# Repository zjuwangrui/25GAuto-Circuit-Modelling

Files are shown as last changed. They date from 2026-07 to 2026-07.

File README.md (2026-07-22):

# 电路模型探究装置 (STM32 + AD9910 + 大彩串口屏)

STM32F103VE 平台。硬件通路：**STM32 → AD9910 → 硬件电路 (×5.11 放大器 + 未知滤波器) → 输出端**。
上位交互靠 **大彩串口屏 (USART2, 115200)**。

---

## 业务链路

### 1. 输出信号（当前唯一实现的链路）

屏侧 3 个控件（学习/推理按钮暂缓）：

| 控件 | 类型 | ctrl_id | 屏发/收帧 |
|---|---|:---:|---|
| 频率输入框 | 文本 (type=0x11) | **4** | `EE B1 11 00 00 00 04 11 [ASCII] 00 FF FC FF FF` |
| 电压输入框 | 文本 (type=0x11) | **7** | `EE B1 11 00 00 00 07 11 [ASCII] 00 FF FC FF FF` |
| 输出信号按钮 | 按钮 (type=0x10) | **11** | `EE B1 11 00 00 00 0B 10 00 01` (**10 字节, 无 FF FC FF FF 帧尾**) |

```
用户屏上输入 freq   → 屏发文本帧 (ctrl_id=4)  → MCU 缓存 last_freq
用户屏上输入 vpp    → 屏发文本帧 (ctrl_id=7)  → MCU 缓存 last_vpp
用户点 "输出信号"   → 屏发按钮帧 (ctrl_id=11) → MCU 调 signal_out_set(last_freq, last_vpp)
                                                → signal_out 反算 H(s)+5.80× → dds_tone_sine
                                                → AD9910 → 电路 → OUT
```

### 2. 学习流程（TODO）

屏侧学习按钮暂未定义 ctrl_id。业务模块 `module/learning` 保留空壳（`learning_start` 只置状态）。

### 3. 推理流程（TODO）

同上，`module/inference` 保留空壳。

---

## 模块分层

```
bsp/            硬件外设 (uart, spi, gpio, adc, lcd, led)
drv/            外设芯片 (ad9910, serial_screen, esp8266, dht11)
module/         业务逻辑:
                  signal_out   传递函数反算 (freq/vpp → DDS 参数)
                  dds          AD9910 各种输出模式 (单音/RAM任意/DRG扫频/跳频/OSK)
                  panel_ctrl   串口屏胶水层 (屏事件 ↔ 业务模块)
                  learning     学习动作 (当前空壳)
                  inference    推理动作 (当前空壳)
                  ui           TFT LCD 页面
                  thd, fft, goertzel  频谱分析
core/           调度器 + 环形缓冲
```

**分层原则**：
- `drv/serial_screen` 只懂协议帧
- `module/panel_ctrl` 只懂 UI 业务映射
- `module/learning` / `module/inference` 只懂算法
- 换屏 → 只改 `drv/serial_screen`；改算法 → 只改对应 module

---

## 硬件接线

| 功能 | STM32 引脚 | 备注 |
|---|:---:|---|
| SPI1 → AD9910 | PA5 / PA6 / PA7 | SCK / MISO(未接) / MOSI |
| AD9910 CS | PA4 | |
| AD9910 RST | PC3 | |
| AD9910 IOUP | PA12 | |
| AD9910 PROFILE[0..2] | PB12 / PB13 / PB14 | |
| AD9910 PWR/DPH/DRC | PC0 / PC1 / PC2 | 上电拉低保命 |
| **USART2 → 串口屏** | **PA2 (TX) / PA3 (RX)** | **115200 8N1** |
| USART1 → 调试口 | PA9 / PA10 | 115200，UART_Printf |
| LCD (FSMC) | 一堆 | 保持原样 |

详细接线：`resources/AD9910模块-STM32接线说明(按实物更正版).txt`

---

## 传递函数（signal_out 用）

$$H_{fit}(s) = \frac{4.68}{1.23 \times 10^{-8} s^2 + 3.48 \times 10^{-4} s + 1}$$

- ωn ≈ 9017 rad/s ≈ 1435 Hz，ζ ≈ 1.57（过阻尼，两实极点 ~518 Hz / ~3990 Hz）
- DC 增益 = 4.68，前级放大 5.00× → **总 DC 增益 ≈ 23.4**
- 系数在 [src/module/signal_out.c](src/module/signal_out.c) 里 `H_S_COEF_*` / `H_S_DC_GAIN` 三个宏
- 放大倍数在 [include/module/signal_out.h](include/module/signal_out.h) 里 `SIGNAL_OUT_AMP_GAIN`

---

---

## 构建

PlatformIO，配置在 [platformio.ini](platformio.ini)：

```shell
pio run              # 编译
pio run -t upload    # 烧录 (ST-Link)
pio device monitor   # 打开串口 (USART1)
```

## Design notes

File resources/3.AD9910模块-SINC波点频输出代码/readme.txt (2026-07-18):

/*********************************************************************************************/
【*】程序简介

-工程名称：AD9910-STM32-DDS驱动板-Vx.x
-实验平台: 康威DDS驱动板
-MDK版本：KEIL 5.14.0
-ST固件库版本：3.5.0
	工程文件位于"\AD9910-STM32-DDS驱动板-Vx.x\USER"目录下，用keil5软件打开VirtualCOMPort.uvprojx即可

【 ！】功能简介：
控制AD9910模块输出SINC波

【*】注意事项：

【 ！】实验操作：
1、使用排线连接驱动板与AD9910模块，驱动板上排线方向唯一，驱动板以及DDS模块上，板子背面双排针，方形焊盘为双排针1脚，对应连接即可
2、使用5V电源连接AD9910模块，使用5V电源连接DDS驱动板，
3、AD9910模块侧面输出高频头，使用SMA屏蔽线，连接示波器，(两个输出头，任意接一个即可)
3、编译该代码，使用jlink下载器下载代码到驱动板
4、确保AD9910模块已上电。按下驱动板复位键(或驱动板重新上电)，调整示波器时间档位到2uS/DIV,即可观察到SINC波输出

/*********************************************************************************************/

【*】 引脚分配
	
STM32控制板		模块	芯片引脚名	功能
PC13		----->	PWR	EXT_PWR_DWN.	掉电控制脚。数字输入。置高(3.3V)芯片关机，不使用需接地。
PA5		<---->	SDIO	SDIO.		串行数据输入/输出。
PC1		----->	DPH	DRHOLD.		数字斜坡保持。数字输入。置高(3.3V)有效,不使用需接地。
PC2		<-----	DRO	DROVER		数字斜坡结束。数字输出(高电平有效)
PC3		----->	IOUP	I/O UPDATE	同步信号(LVDS),数字输入(上升沿有效)。写完多个寄存器后给一个高脉冲。
PC4		----->	PF0		
PC10		----->	PF1		
PC5		----->	PF2	PROFILE[2:0]	Profile选择引脚。数字输入（高电平有效）。
PA6		----->	RST	MASTER RESET	主机复位，数字输入（高电平有效）。
PA2		----->	SCK	SCLK		串行数据时钟。数字时钟(上升沿执行写操作，下降沿执行读操作)
PA4		----->	DRC	DRCTL		数字斜坡控制。数字输入.控制数字斜坡发生器的斜率极性,不使用需接地。
PC8		----->	OSK	OSK		输出振幅键控。数字输入。
PB10		----->	CSB	CS加I/O_RESET	数字输入。SPI通信CS控制脚及通信复位脚。
GND		<---->	GND			控制板与AD9910模块需共地。
浮空		------	其他			所有未说明但模块有留出管脚，未使用可直接浮空，功能请参考数据手册

/*********************************************************************************************/

【*】 版本

-程序版本：0.6
-更新日期：2023-05-xx

/*********************************************************************************************/

【*】 联系我们

-淘宝店铺    https://kvdz.taobao.com

/*********************************************************************************************/

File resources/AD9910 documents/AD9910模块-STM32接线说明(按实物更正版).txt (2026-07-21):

================================================================
  AD9910 DDS 模块 <-> STM32F103VE  接线说明
  --------------------------------------------------------------
  项目: 25GAuto-Circuit-Modelling
  驱动: src/drv/ad9910.c    业务: src/module/dds.c
  最后更新: 2026-07-16 (对齐当前代码实际引脚映射)
================================================================

一、必接引脚 (单音正弦输出 = Mode 1 最小系统)
--------------------------------------------------------------
    STM32F103VE     方向        AD9910 模块丝印     芯片功能
    -----------     -----       ---------------     -----------------------
    PA5             ->          SCLK                 SPI 时钟   (SPI1 SCK, 9 MHz)
    PA7             ->          SDIO                SPI 数据   (SPI1 MOSI, 只写)
    PA4             ->          CSB                 片选       (低有效, 软控)
    PC3             ->          RST                 MASTER_RESET (高电平复位)
    PA12             ->          UPD                IO_UPDATE   (上升沿刷寄存器)
    PB12            ->          PF0            (PF0,PF2,PF2的功能描述)Mode 4 跳频用. 单音模式下必须为低电平,否则输出可能偶发丢失.
    PB13            ->          PF1            推荐做法二选一:
                                                A) 三根线连到 STM32, 让驱动拉低
                                                B) 模块侧直接短接到 GND (更省 GPIO)
                                                悬空 = 错误配置, 会不稳定.
    PB14            ->          PF2            
    GND             <->         GND                 共地 (必须!)

    电源: 外部 DC 5V (0.5A 以上)  ->  模块 "DC-5V" USB 供电座，连接到电源的CH3USB接口即可，成功供电的时候AD9910模块会有小蓝灯亮起来
          !! AD9910 模块不能从 STM32 板取 3.3V, 它自带 5V->3.3V/1.8V 稳压器 !!

ftp上面的资料(AD9910模块-STM32接线说明)部分有误，有些不必连接，有些选择连接。更正如下：

━━━━━━━━━━━━━━━━━━━━━━━━━━━━━━━━━━━━━━━━━━━━━━━━━━━━━━━━━━━━━━━━━━━━━━━━━━━━━━
 STM32控制板   方向    模块    芯片引脚名        功能
━━━━━━━━━━━━━━━━━━━━━━━━━━━━━━━━━━━━━━━━━━━━━━━━━━━━━━━━━━━━━━━━━━━━━━━━━━━━━━

 PC13         ────>    PWR     EXT_PWR_DWN       掉电控制脚。数字输入。
                                                 置高(3.3V)芯片关机，不使用需接地。
 【实际情况】这个引脚AD9910芯片上有，模块上面的排针没有引出，不必处理，
           PC13也不需要连接什么。

────────────────────────────────────────────────────────────────────────────────

 PA5          <───>    SDIO    SDIO              串行数据输入/输出。
 【实际情况】合理，必连，PA5引脚可以改成其他GPIO。

────────────────────────────────────────────────────────────────────────────────

 PC1          ────>    DPH     DRHOLD            数字斜坡保持。数字输入。
                                                 置高(3.3V)有效，不使用需接地。
 【实际情况】根据实际需要，数字斜坡模式可以输出频率或者相位或者幅度线性
           变化的正弦波，一般我们不需要这个功能。

────────────────────────────────────────────────────────────────────────────────

 PC2          <────    DRO     DROVER            数字斜坡结束。
                                                 数字输出(高电平有效)。
 【实际情况】同DPH。

────────────────────────────────────────────────────────────────────────────────

 PC3          ────>    IOUP    I/O UPDATE        同步信号(LVDS)，数字输入(上升沿有效)。
                                                 写完多个寄存器后给一个高脉冲。
 【实际情况】必须连接，但是引脚名称模块上实际是UPD。

────────────────────────────────────────────────────────────────────────────────

 PC4          ────>    PF0
 【实际情况】必须连接。

────────────────────────────────────────────────────────────────────────────────

 PC10         ────>    PF1
 【实际情况】必须连接。

────────────────────────────────────────────────────────────────────────────────

 PC5          ────>    PF2     PROFILE[2:0]      Profile选择引脚。
                                                 数字输入（高电平有效）。
 【实际情况】必须连接。

────────────────────────────────────────────────────────────────────────────────

 PA6          ────>    RST     MASTER RESET      主机复位，数字输入（高电平有效）。
 【实际情况】必须连接。

────────────────────────────────────────────────────────────────────────────────

 PA2          ────>    SCK     SCLK              串行数据时钟。数字时钟
                                                 (上升沿执行写操作，下降沿执行读操作)。
 【实际情况】必须连接。

────────────────────────────────────────────────────────────────────────────────

 PA4          ────>    DRC     DRCTL             数字斜坡控制。数字输入。
                                                 控制数字斜坡发生器的斜率极性，
                                                 不使用需接地。
 【实际情况】处理同DPH、DRO。实测发现不需要的时候不用接地，悬空即可，
           需要数字斜坡模式的时候连接到对应的GPIO引脚。

────────────────────────────────────────────────────────────────────────────────

 PC8          ────>    OSK     OSK               输出振幅键控。数字输入。
 【实际情况】选择性连接，振幅键控是和数字斜坡一样的另一种输出模式，
           不需要的话就悬空，需要则连接某个给定GPIO。

────────────────────────────────────────────────────────────────────────────────

 PB10         ────>    CSB     CS加I/O_RESET     数字输入。SPI通信CS控制脚
                                                 及通信复位脚。
 【实际情况】必须连接。

────────────────────────────────────────────────────────────────────────────────

 GND          <───>    GND
 【实际情况】必须共地，控制板与AD9910模块需共地。

────────────────────────────────────────────────────────────────────────────────

 浮空         ─────    其他                      所有未说明但模块有留出管脚，
                                                 未使用可直接浮空，功能请参考
                                                 数据手册。

━━━━━━━━━━━━━━━━━━━━━━━━━━━━━━━━━━━━━━━━━━━━━━━━━━━━━━━━━━━━━━━━━━━━━━━━━━━━━━

二、可选引脚 (仅特定模式用)
--------------------------------------------------------------
    STM32F103VE     AD9910 丝印    情况说明
    -----------     -----------    ----------------------------------------
    PB15            OSK            Mode 5 (OSK 键控) 用. 单音下悬空即可.

三、完全不接的引脚 (悬空 OK)
--------------------------------------------------------------
    SDO       SDO引脚是无排针的引脚，有些资料会提到这个引脚，实际上我们是无法控制的
    PWR      EXT_PWR_DWN, 掉电控制脚, 模块上无此引脚排针，无法控制
    SYC       SYNC 相关, 多片同步用
    PDCLK     并口数据时钟, 并口模式用
    TEN       TXENABLE, 并口模式用
    RSO       IO_RESET, 通信复位用
    PLL       无芯片对应排针
    DRO       DROVER, 是芯片输出脚
    D0..D15   16 位并口数据总线, 并口模式用
    F0, F1    并口目的选择, 并口模式用

    -> 全部悬空, 本工程不需要
AD9910是一个有90多个引脚的芯片，而AD9910模块上的排针只引出了一部分引脚，有些资料虽然提到了一些引脚，但是实际上我们无法控制，比如上面的SDO,PLL,PWR。
并口模式是这样，AD9910可以通过SPI串行输入，也可以直接并行输入，都可以输出一样的波形。一般有FPGA用并行，无的话用串行，所以并行相关引脚我们一般都不用，悬空即可。

四、示波器接线
--------------------------------------------------------------
    AD9910 SMA 输出       示波器
    ---------------       ---------------------------
    OUT+ (J3)             CH1     
    OUT- (J4)             也可以接 CH2 做差分，观察CH1-CH2波形，也可以不管。这个信号是OUT+的反相，不差分没事情。

    AD9910芯片输出是电流，但是AD9910模块内置了一些电路将电流转化为电压，将模块的SMA接一个SMA转鳄鱼夹线(直接和老师说要这个线)，再连接示波器就可以用，连接排针则可接入实际电路。

五、幅度校准 (已实测)
--------------------------------------------------------------
    include/module/dds.h 里 DDS_FULL_SCALE_V = 1.0f
    实测: dds_tone_sine(f, 1.0f, 0) 时示波器测到差分峰值约 1 V
    -> 当前 1.0f 已经匹配本板实际满量程, 不需要重新校准.
    -> 若换其他 AD9910 模块 (balun / Rset 不同), 需重新实测并修改此宏.

六、代码里改引脚的位置
--------------------------------------------------------------
    src/drv/ad9910.c    第 28-46 行 "硬件绑定" 宏
                          CS / RESET / IOUP / PROF / OSK / PWR / DPH / DRC
                          全部集中在这一块

    src/bsp/spi.c       第 17 行左右, SPI1 的 SCK/MOSI/MISO
                          (PA5/PA7/PA6 硬件固定, 不建议改)

    src/bsp/uart.c      USART1 的 PA9(TX) / PA10(RX) 调试串口

================================================================

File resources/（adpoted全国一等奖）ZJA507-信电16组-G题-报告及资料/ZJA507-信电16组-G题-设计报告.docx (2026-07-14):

# 电路模型探究装置（G 题）

摘要：本装置以STM32F407微控制器为核心，结合DDS信号源、高精度ADC采样及数字信号处理技术，对已知及未知电路模型的自动化分析与控制。本系统分两大功能模块。第一，针对已知二阶系统模型，装置能够根据用户设定的目标输出频率（100Hz-3kHz）和电压（1-2V），通过传递函数H(s)反算出所需的输入电压，并精确控制DDS输出。第二，针对未知RLC电路模型，装置具备自主学习与建模能力。通过自动扫频（1kHz-500kHz）获取电路的幅频响应数据，采用基于Levenberg-Marquardt（LM）算法的专家拟合系统，精确辨识出电路的滤波类型（低通、高通、带通、带阻）及其关键参数（k, f0, Q）。学习完成后，装置能实时采集外部信号，通过数字IIR滤波器模拟未知电路的响应，与实际信号峰峰值相对误差小于10%，波形稳定无失真。

关键词：电路模型，系统辨识，自动控制，数字滤波器，STM32

# 1 方案对比与论证

## 1.1 波形发生电路

【方案一】采用DDS集成模块，由单片机控制输出可调固定频率、幅值的正弦波，AD9910输出的正弦波的最高频率可达420MHz，具有扫频功能。该方案的优点是频率分辨率高，相关波形参数可调，缺点是成本较高。

【方案二】采用锁相环频率合成，该方法可以产生频率稳定精确、且频率大范围可调的信号，优点是频率相对更稳定精确，缺点是电路更复杂，且工作频率范围由电路参数控制，不易直接调节。

波形发生的目的是为装置提供频率稳定的测量正弦波信号，考虑到在进一步的电路设计分析中，需要尝试不同频率的测量信号，因此更希望波形发生电路频率稳定便于调节，结构简单。因此选择方案一。

## 1.2 信号输入方案的论证与选择

【方案一】外挂ADC模块（如TI的ADS1115或AD7606）可提供更高分辨率（16-24位）和更宽动态范围。部分高速ADC型号（如AD9288）采样率可达100MSPS，远超STM32板载ADC。其优势在于信号调理电路可独立设计，减少数字噪声干扰，提高信噪比；高精度型号（如24位Σ-Δ型ADC）适合微弱信号采集。然而，该方案存在关键缺陷：外挂ADC使用独立时钟源（通常为外部晶振），与STM32系统时钟不同步，导致采样时钟存在固有偏差（±30ppm或更高）；在进行数字滤波和信号处理时，时钟漂移将引起相位误差累积，严重影响频率响应测量精度；

【方案二】采用STM32板载ADC。STM32F407ZGT6集成3个12位精度ADC，总采样率可达8.4MSPS（3交错采样），单通道最高2.4MSPS，理论可采集1.2MHz以下信号（满足奈奎斯特准则）。其核心优势在于与主控时钟完全同步，ADC采样时钟源自APB2总线（经分频后最高30MHz），与系统时钟严格一致，彻底消除时钟漂移问题；内置硬件过采样功能可提升有效分辨率至14位；支持DMA直接内存访问，减轻CPU负担；

综上，考虑到题目的要求，方案二能更直接、更精确的实现信号的采样与同步输出的兼容，因此选择方案二。

## 1.3 交流信号输出方案的论证与选择

【方案一】STM32板载DAC。STM32F407ZGT6内置双通道12位DAC，最高更新率达1MSPS，理论输出正弦波频率可达500kHz（满足奈奎斯特准则）。其优势在于与主控时钟完全同步，无时钟漂移问题，可确保输出信号与系统时钟严格同频；数字信号处理直接在MCU内部完成，延迟低且可控。通过软件实现IIR滤波算法，能精确复现目标系统的频率响应特性。但受限于DAC更新率，单一通道最高输出频率不足1MHz；输出电压范围为0-3.3V，需通过精密运放（如OPA2211）构建放大与偏置电路才能达到3V峰峰值要求；高频段谐波失真增加，影响信号纯度。

【方案二】FPGA结合并行传输DAC。采用FPGA（如Xilinx Artix-7）配合高速DAC（如AD9767，125MSPS）可实现高达40MHz的输出频率，远超题目要求。FPGA的并行处理架构能实时计算复杂波形，支持多通道同步输出。但该方案系统复杂度高，需额外设计FPGA与STM32的高速通信接口（如FMC或并行总线），增加硬件设计难度和成本；两系统时钟不同步导致相位抖动，难以满足频率误差<5%的要求；开发周期长，不利于竞赛时限内完成

【方案三】STM32外挂DDS模块 采用AD9850等DDS芯片（时钟70MHz），频率分辨率可达0.04Hz，输出频率范围0-40MHz，完全满足>1MHz的要求。其优势在于频率切换速度快（<100ns），扫频过程中无需等待稳定，可高效采集多频点数据用于H(s)建模；输出信号频谱纯净，THD<-80dBc。但DDS使用独立晶振（通常±30ppm精度），与STM32系统时钟存在固有偏差，导致输出信号与输入信号存在频率漂移，无法满足"稳定同频显示"要求；输出幅度仅0.5Vpp，需多级放大才能达到3V峰峰值，增加电路复杂度。

综合题目双重需求：基础任务要求快速扫频建模，拓展任务要求稳定同频显示。经如下论证，采用方案一与方案三结合的策略：

1. 扫频建模阶段：使用DDS模块（方案三）实现100Hz-1.5MHz范围内的快速扫频，其高频率精度和快速切换特性可高效获取未知电路的频率响应数据，满足H(s)建模需求；

2. 同频显示阶段：采用STM32板载DAC（方案一）结合数字IIR滤波，输出与输入信号严格同步的预测响应，避免晶振误差导致的频率漂移；

3. 信号调理：两路输出分别经由NE5532构建的精密放大电路，实现0-3.3V至±1.5V的电平转换与增益调节，确保峰峰值>3V，利用模拟开关整合至同一输出。

该方案充分发挥了DDS的频率精度优势和STM32 DAC的时钟同步优势，既满足了快速建模需求，又保证了同频显示的稳定性，同时避免了FPGA方案的复杂性，是本系统最优解。

# 2 理论分析与计算

## 2.1 已知模型电路的分析与计算

（1） 电路结构与拓扑分析

根据题目给出的H(s)响应函数可以知道已知模型为一个二阶低通滤波电路，直流增益为5倍，故可利用有源二阶滤波电路结合同相放大器实现，为了实现题目要求输入电阻大于100kΩ，采用NE5532音频放大器构建跟随器，输入电阻约为NE5532输入电阻300kΩ，为了避免有源二阶滤波器产生自激现象，采用单位增益的Sallen-Key结构有源二阶滤波器，滤波完成后经过同相放大器放大至5倍后，再经跟随器输出，降低输出电阻。

（2）电路参数设计

有源二阶低通滤波器：采用Sallen-Key结构，H(s) = 1 / ( (R1R2C1*C2) * s² + ((R1+R2)C1) * s + 1 )，故R1 * R2 * C1 * C2 = 1e-8；(R1 + R2) * C1 = 3e-4。设定C1=C2=100nF，计算R1=2618Ω,R2=382Ω

同相放大器：同相输入后在反相输入端设定2kΩ电阻接地，反馈电阻应设定为10kΩ

## 2.2 精密信号放缩电路分析设计与计算

## （1）需求分析

DDS输出信号峰峰值最大1.17V，需要给予放大倍率以满足最大输出电压高于3V的需求，STM32ADC输入限幅0~3.3V，需要对信号进行放缩并加以直流偏置以避免烧毁单片机

### （2） 设计与参数计算

由于同时存在放大与缩小需求，需要同时保留信号放大与缩小的功能，同时由于放大信号频率最大值需要大于1MHz较高，需要选用OPA1612高GBW运放辅以多阶放大以避免失真问题，初级放大采用同相输入端直接输入辅以1~5倍可调增益，第二级采用电位器可调0~10/11衰减后接入20倍同相放大器，最后通过电容直接耦合加入可调直流偏置，最终实现直流偏置0.57V~12V可调，交流增益0~100倍任意可调，同时满足DDS放大输出与ADC衰减输入的需求。

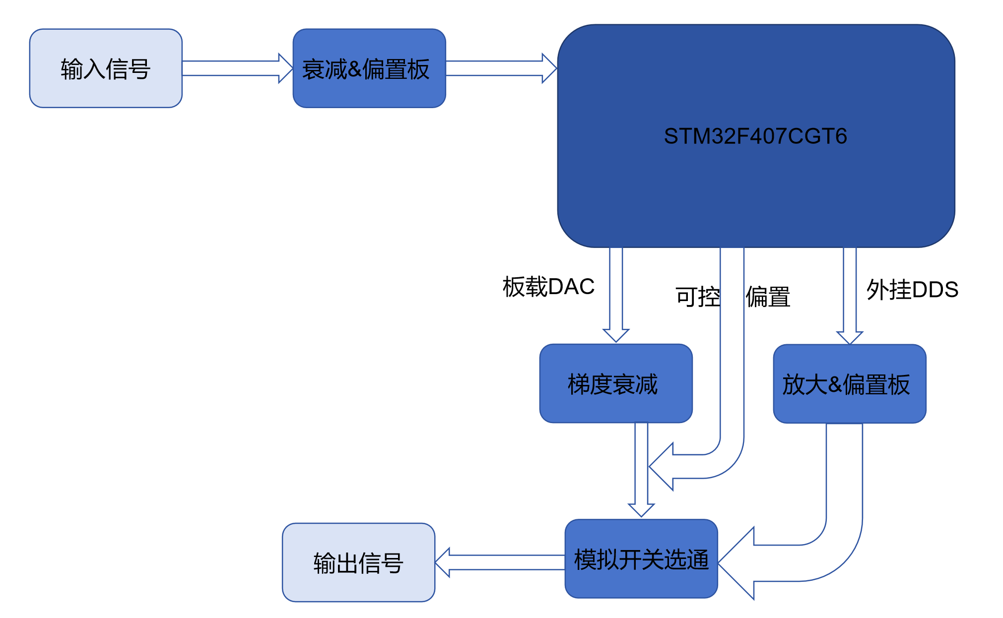
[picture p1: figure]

# 3 电路与程序设计

## 3.1 电路设计

图2. 系统框图

## 3.2 已知模型电路子系统电路

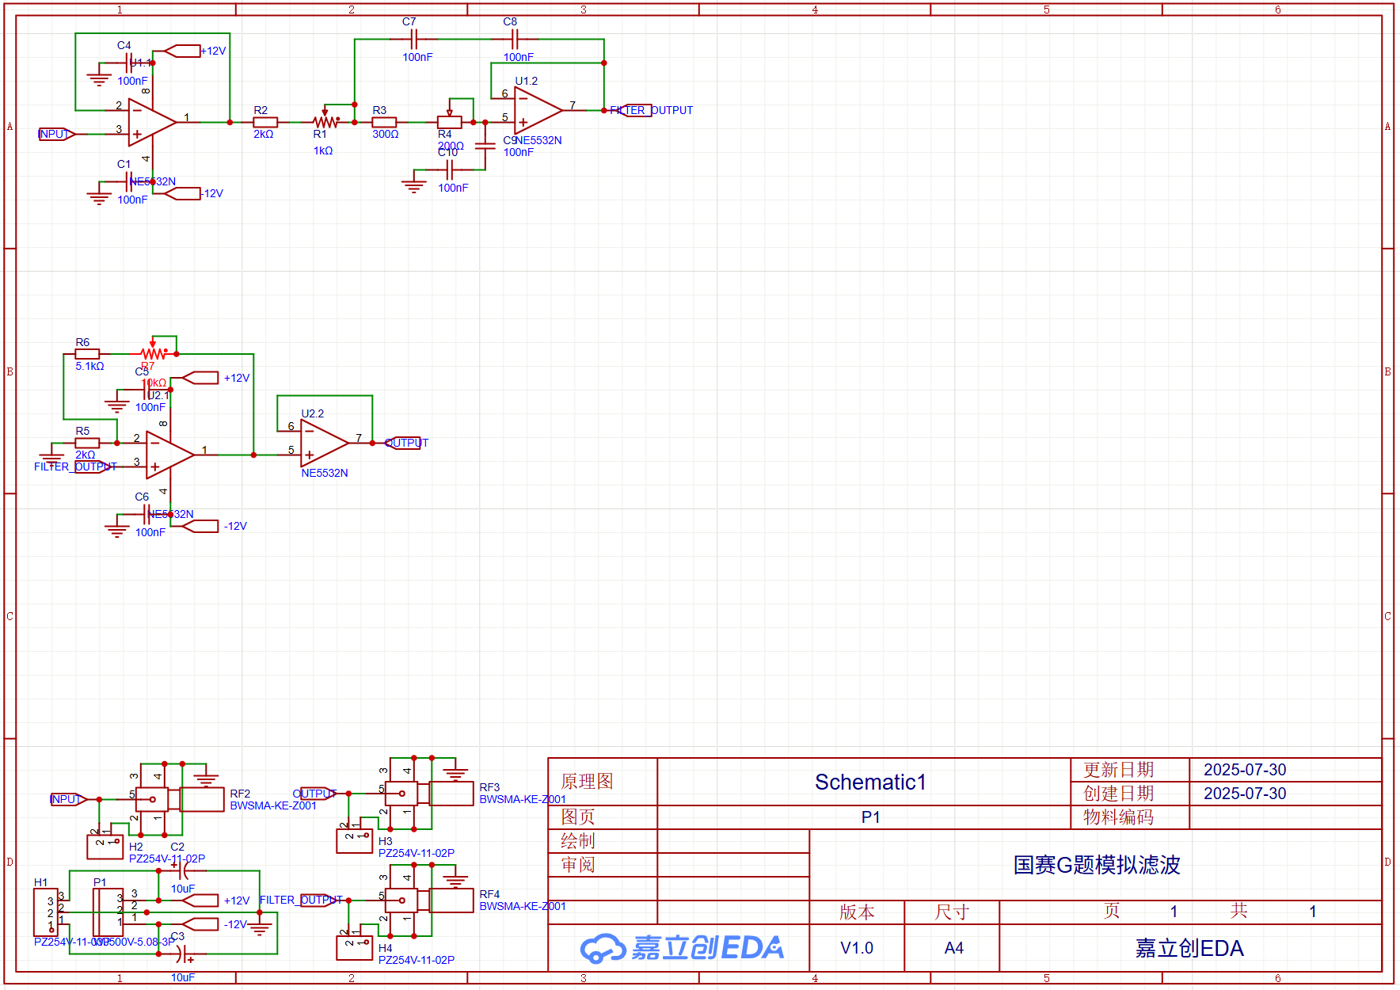
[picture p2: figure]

图3. 已知模型电路

## 3.3 DAC信号输出电路子系统框图与电路原理图

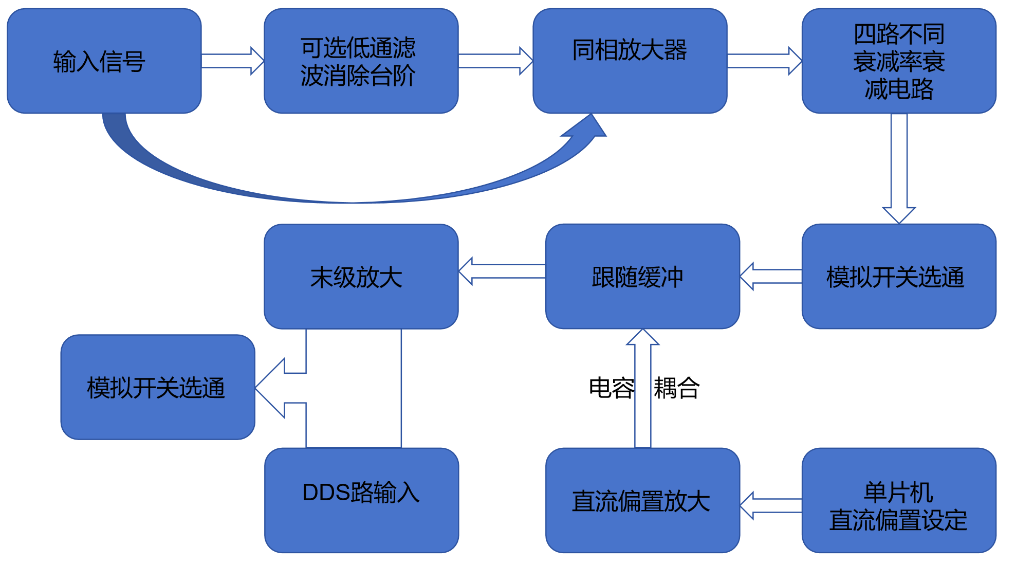
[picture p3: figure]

图4. DAC信号输出电路子系统框图

## 3.4 DAC信号输出电路子系统电路

电源：整体电路设计中用到+-12V与+-5V供电，+-12V供电由学生电源提供，+5V供电采用+12V经LM317 LDO降压输出，最大电流满足需求，-5V由+12V经DCDC降压芯片降至-5V输出

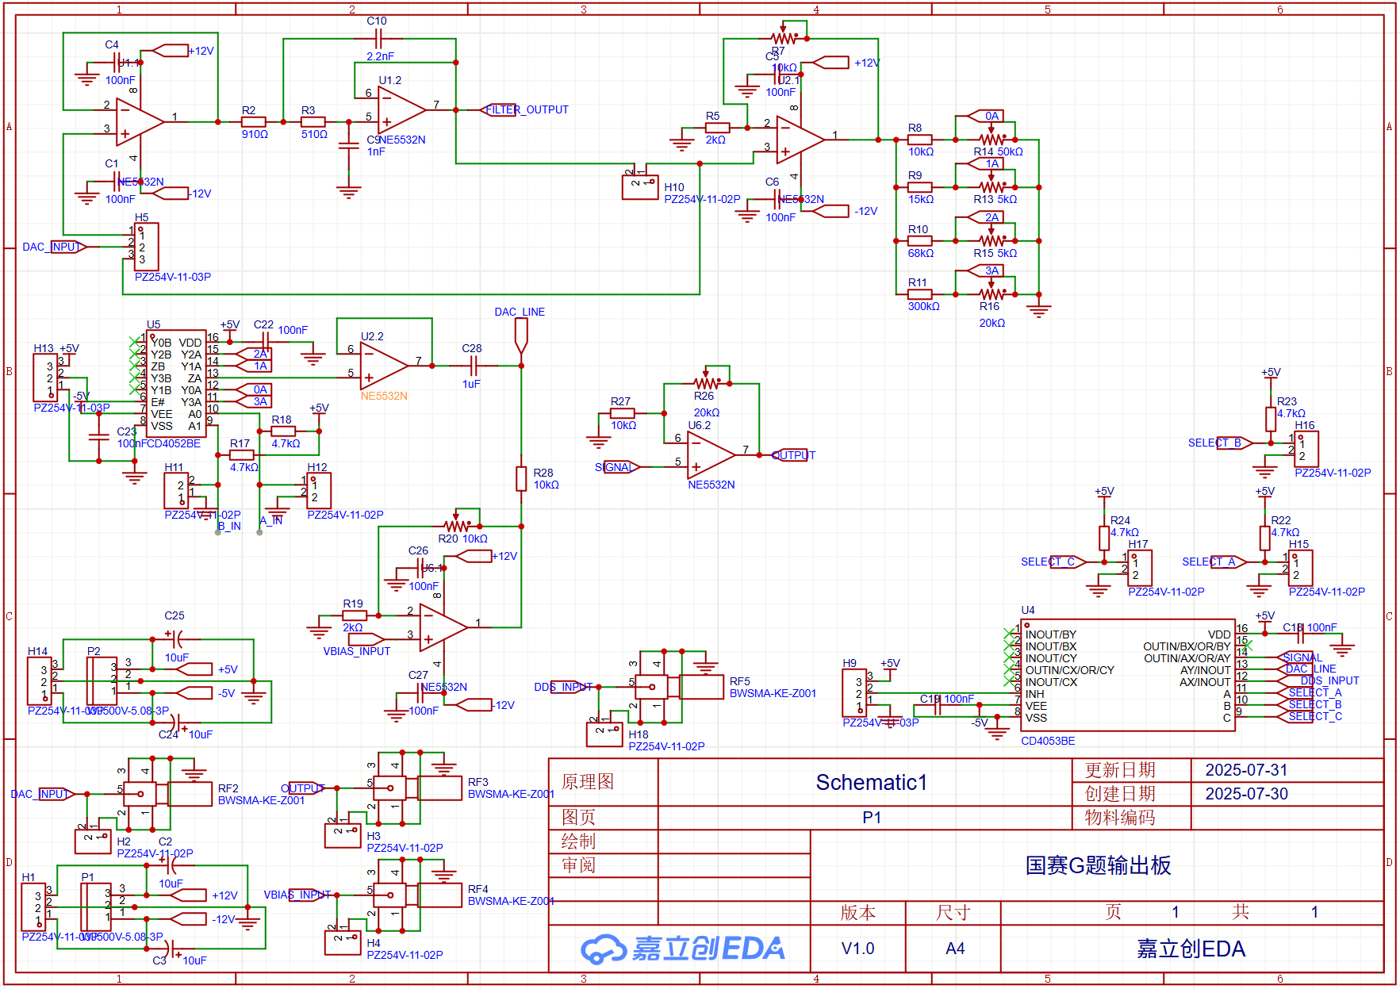
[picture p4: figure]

# 4 测试方案与测试结果

## 4.1 测试结果

向已知模型电路中输入各频率的1Vpp，偏置1V的信号，分别测量输出电压，与理想H(s)的增益对比，测试结果好，如下表所示：

信号频率(kHz) | 直流 | 0.1 | 0.3 | 0.5 | 1 | 1.5 | 2 | 3
输出Vpp增益(V/V) | 5.001 | 5.045 | 4.522 | 3.822 | 2.473 | 1.726 | 1.286 | 0.802
理想增益Av(V/V) | 5 | 4.932 | 4.472 | 3.834 | 2.526 | 1.767 | 1.311 | 0.806
相对误差 | 0.02% | 2.29% | 1.11% | 0.32% | 2.10% | 2.42% | 1.91% | 0.50%

## 4.2 校正DDS输出后设定已知模型电路输出电压测试

频率 | 100Hz | | 500Hz | | 1kHz | | 2kHz | | 3kHz
幅值 | 1V | 2V | 1V | 2V | 1V | 2V | 1V | 2V | 1V | 2V
实测值 | 1.002 | 1.955 | 1.035 | 2.045 | 1.045 | 2.056 | 1.046 | 2.055 | 1.047 | 2.053
相对误差 | 0.2% | 2.25% | 3.5% | 2.25% | 4.5% | 2.28% | 4.6% | 2.25% | 4.7% | 2.65%

## 4.3 结果分析

根据上述测试数据，可以得出以下结论：

1、已知模型电路可以接近给出的H(s)响应函数，相对误差最大不超过3%，远高于精度要求不超过10%

2、探究系统可以输出0.23Hz分度值的正弦波，最大不失真频率可达1.5MHz，峰峰值达4.5V，输出峰峰值不小于3V输出频率可达2MHz

3、探究系统可输出1kHz信号，使得已知模型电路输出2V定值电压，实测输出2.04V，相对误差2%，远低于题目要求5%

4、探究系统可输出100Hz~3kHz信号，使已知模型电路输出电压可以以0.1V步进调整，相对误差在5%以下

5、探究系统可在40s内对未知模型电路进行学习建模，拟合其幅度谱并给出滤波器类型的判断。

6、探究系统可根据学习的幅度谱，对输入的1kHz~50kHz的信号进行模拟输出，与未知模型电路的幅值差距在10%以内。

综上所述，本设计达到设计要求。

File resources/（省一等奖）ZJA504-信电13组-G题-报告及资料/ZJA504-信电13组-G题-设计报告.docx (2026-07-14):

电路模型探究装置（G题）

摘要：本装置以TI MSPM0G3519单片机为主控核心，利用DDS芯片AD9910生成信号，并结合由DAC控制的AD603压控增益放大器进行精密幅度调节，通过串口屏进行人机交互。装置能够完成两项核心任务：首先，根据内置的已知滤波器H(s)模型，自动计算并生成所需激励信号，实现对输出的精确控制。其次，在未知模型探究中，装置通过扫频，利用双通道ADC同步采集输入输出信号，在主控内部通过q15格式CFFT算法快速建立未知电路的数字模型。学习完成后，装置能实时采集外部信号，通过CFFT、CIFFT算法进行运算，较为准确地复现出与未知电路相同的输出。经测试，本系统基本完成了对已知模型的精确控制和未知模型的建模学习与复现，误差均在题目要求范围以内，基本要求和发挥部分指标大部分已实现。

关键词：TI MSPM0G3519单片机 、DDS、压控增益放大器、滤波器、CFFT（快速复数傅里叶变换）、CIFFT（快速复数逆傅里叶变换）

1.方案论证

1.1比较与选择

1.2.1 已知模型电路选择

【方案一】采用 Sallen−Key 结构搭建滤波器，模拟H（S）函数。

【方案二】采用二阶RC滤波器+运算放大器，模拟H（S）函数。

选择：二者的仿真都很精准，与传递函数H（S）的频率响应很接近，但是实际搭建电路后，发现方案二的准确度更高，曲线拟合更精准，故选取【方案二】。

1.2.2 正弦信号生成方案：

【方案一】采用AD9910来生成频率可控的正弦波，配合以DAC控制VCA的增益来调节信号幅度。

【方案二】采用AD9851输出幅度一定的正弦信号，再利用AGC来调控幅度。

选择：由于考虑到后续需要用到AD9910的随机信号生成功能，又在实验中发现制作的AGC在100Hz附近输出波形严重失真，由此决定采用【方案一】。

1.2.3 未知电路学习建模方案：

【方案一】利用DDS输出1到512000Hz的扫频信号，步进为1kHz，再用双ADC采集输入端和输出端的信号，利用q15格式的CFFT算法计算出输入输出信号的复数谱，在相应的频率点作复数除法并逐个填入H(s)响应谱。

【方案二】在双ADC采样处信号后直接计算输入输出端的Vpp，做除法后直接得到增益谱。

【方案三】用DDS输出1到512000Hz的扫频信号，步进为1kHz，再用双ADC采集输入端和输出端的信号，利用float32_t格式的CFFT算法计算出输入输出信号的复数谱，在相应的频率点作复数除法并逐个填入H(s)响应谱。

选择：由于【方案二】完全损失了相位信息，对于复杂波形输出的的信号严重失真，而【方案三】耗时过长，因此采用【方案一】，通过分析幅度谱的两个3dB点位置即可判断滤波类型，为保证输入输出端采样的同时性，两者均采用同一个timer触发，并将采样频率定为1MHz。

1.2.4 推理输出方案：

在得到H(s)之后即可利用其中一个ADC采样输入信号，利用CFFT计算其复数谱，再将其与H(s)作复数乘法得到输出信号Y(s)的频谱，而对于频谱变换的CIFFT，我们有以下两种方案。

【方案一】调用arm_math库自带的cfft_q15进行反变换

【方案二】采用手工封装的经过类型转换的cifft进行计算

选择：在实验过程中CIFFT_q15的输出严重丢失了分辨率，于是我们采用了【方案二】，反变换出它的缩放后时域谱并记录下其峰峰值用于预测其幅值。信号输出采用AD9910的数字模拟输出方案，利用过零点法记录下其一个周期的点数并计算出其频率，将包含一个周期的点的数组和频率传给AD9910的RAM后即可使能输出波形，幅度控制同样通过DAC控制VCA的反馈方案。

1.2 方案描述

1.1.1 系统组成框图

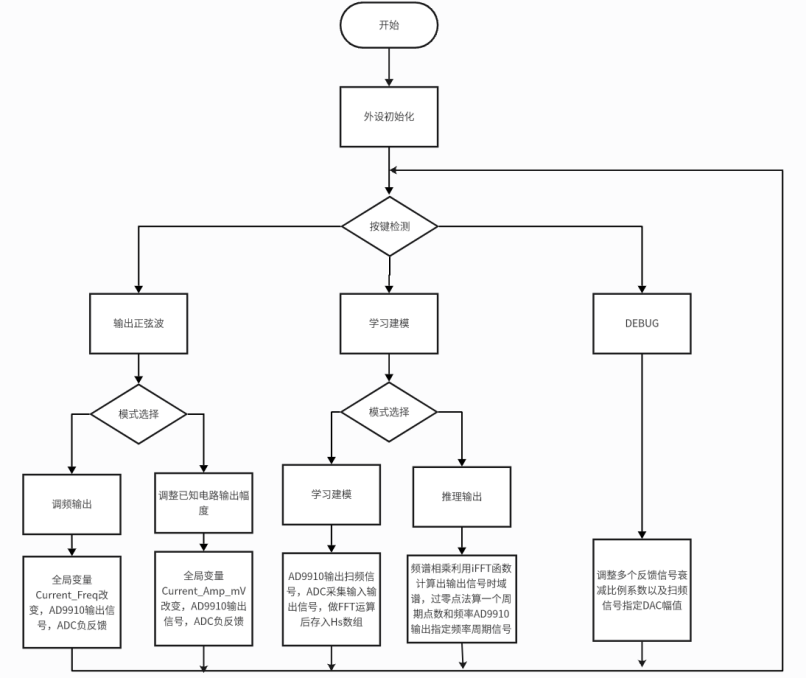
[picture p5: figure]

图1 系统框图

1.1.2 系统工作原理

本装置上电初始化后，可以通过不同的按键，进入不同的工作模式。

正弦波控制模式：此模式下，装置既可以作为独立的信号源，输出指定频率的正弦波；也可以进入控制状态，根据已知的H(s)模型，自动计算并生成精确的激励信号，从而将“已知模型电路”的输出稳定在要求的电压值上。

学习与推理模式：此模式用于发挥部分。学习模式中，装置自动执行扫频，通过双通道ADC同步采集输入输出信号，并利用FFT算法快速建立起未知电路的数字模型H(s) 。推理模式中，装置会利用这个模型，实时地将外部输入信号计算并转换为与未知电路行为一致的输出波形，最终通过AD9910的任意波形生成功能将其复现出来。

调试模式：系统还包含一个DEBUG模式，用于脱机调试。

2.理论分析与计算

2.1已知模型电路分析

已知模型的传递函数： H(s)=5/(10^(−8) s^2 +3×10^(−4) s+1) ，而对于二阶RC有源低通滤波器的传递函数公式为： H(s)=(ω_n^2)/(s^2 +2ξω_n +ω_n^2) ，故可推算出滤波器所需的R、C的值。经过计算，取 R1=1kΩ ， R2=1kΩ，C1100nF，C2=100nF，R3=2kΩ，R4=8kΩ ，拟合出已知模型的传递函数。

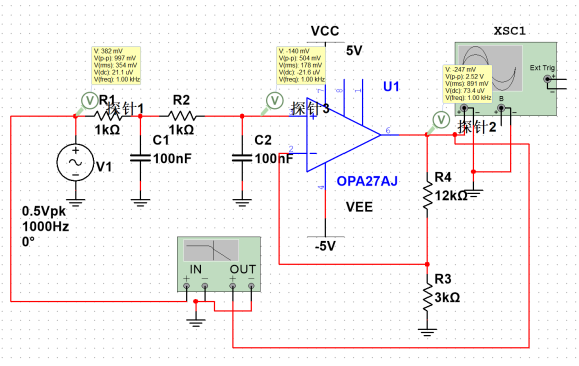
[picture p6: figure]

图2 低通滤波器仿真电路图

2.2未知模型电路学习建模方法

本方法的核心是扫频分析。装置首先用DDS生成一个扫频信号输入到未知电路。同时，采用双通道ADC同步采集电路的输入和输出信号。采集后，系统对两路信号执行q15格式的快速傅里叶变换（CFFT），得到它们的复数频谱。最后，通过将输出频谱除以输入频谱，便可计算出该电路的传递函数H(s)模型，并依此判断出其滤波类型。

3.电路与程序设计

3.1电路设计

3.1.1 已知模型电路：

采用RC二阶有源低通滤波器，电阻R1、R2和电容C3、C4的值是根据理论计算精确选择的，以实现目标传递函数。

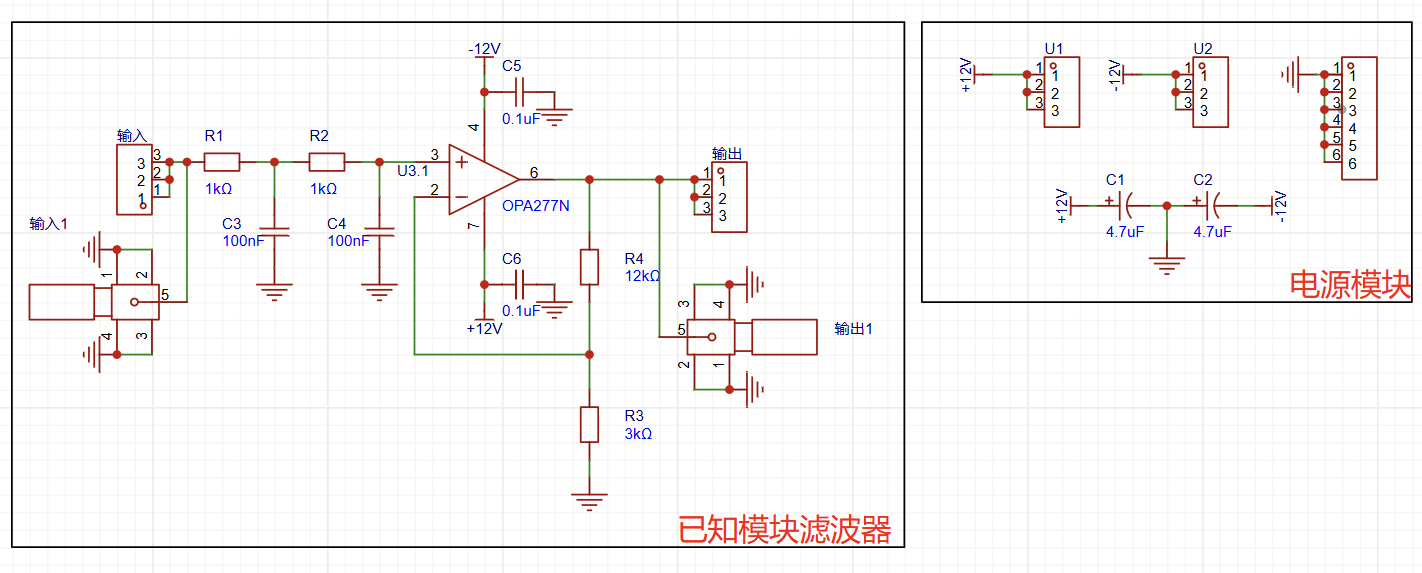
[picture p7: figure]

图3 已知模型电路原理图

3.1.2 电压偏置跟随器：

该电路使用OPA27运放搭建成电压跟随器，一是为了将前后级隔离，提供缓冲；二是作为ADC输入驱动，将在0V附近摆动的交流信号转化为1.6V附近摆动的偏置信号，从而输入单片机采样。

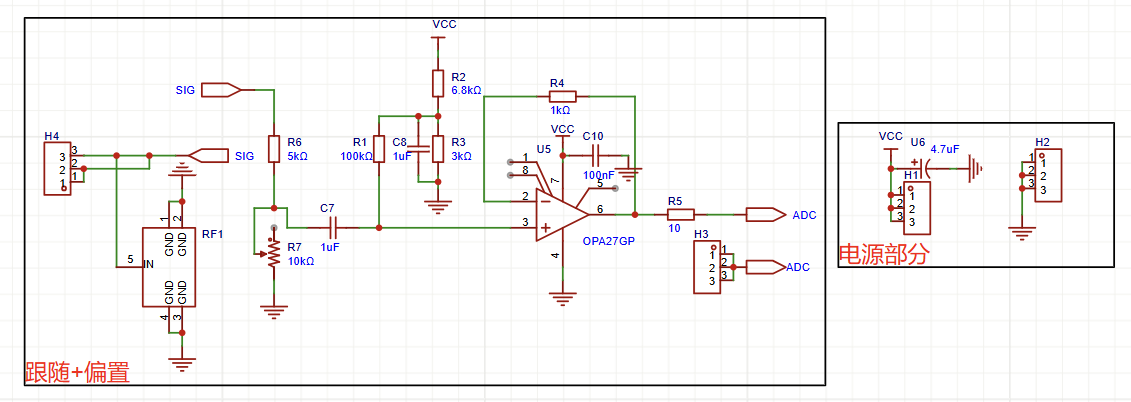
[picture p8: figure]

图4 电压偏置跟随器电路原理图

3.1.3 AD603压控增益放大器：

单片机通过DAC输出一个控制电压VGP，控制AD603放大器的增益。OPA690高速运放作为末级输出缓冲，提供足够的驱动能力。

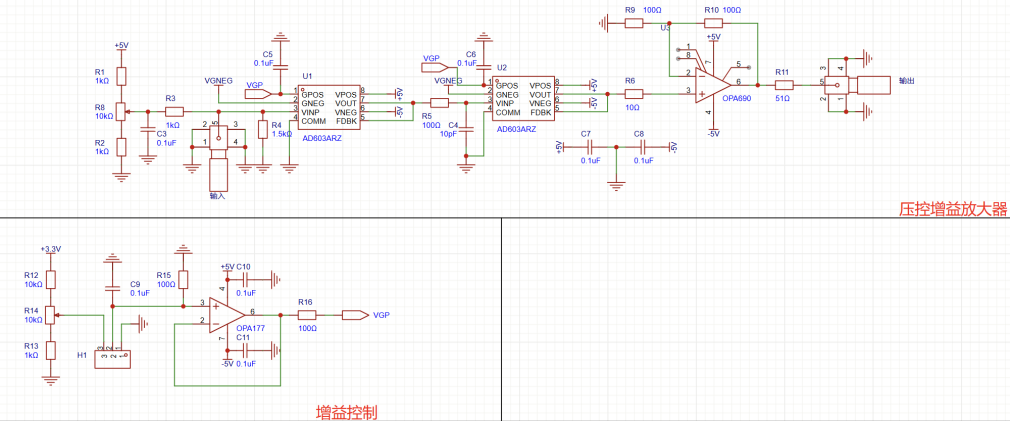
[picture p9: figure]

图5 AD603压控增益放大器电路原理图

3.2程序设计

装置的控制器是TIM0G3519开发板。在正弦波生成过程上，控制部分主要完成了控制DDS输出指定频率的正弦波，由ADC接受输出衰减信号与设定值比较，并通过DAC来与VCA交互以控制其幅度；在学习建模部分，通过TIMER触发双ADC同步采样输入输出信号，分别FFT运算并作复数除法后得到H(S)作为未知装置模型，以完成学习建模过程；在推导输出部分，控制器对输入信号进行FFT运算后与H(S)完成复数乘法再作CIFFT生成输出信号，并计算一个周期的点数以及频率、幅度，最后控制AD9910和VCA以输出相应信号。

人机交互方面，采用串口屏幕与单片机通信，加强了可视化和直观性。

4.测试方案与测试结果

4.1测试方案及测试条件

4.1.1 测试条件

直流稳压电源eTM-3303D、示波器DHO4804、信号发生器DG-4202。

4.1.2 测试方案

测试（1）：已知模型电路特性验证 向“已知模型电路”输入1Vpp、频率100Hz至3kHz的正弦信号 。测量各频点的输出电压，并与由传递函数H(s)计算的理论值进行比较，验证相对误差小于10%。

测试（2）：探究装置信号输出能力测试 测试探究装置产生的正弦信号，验证其频率范围不小于1MHz、频率相对误差小于5%，且各频点输出电压峰峰值最大值不小于3V。

测试（3）：探究装置对已知模型的控制精度测试 将探究装置连接至“已知模型电路”，设置装置在100Hz至3kHz频率范围内 ，控制模型电路输出1V至2V的峰峰值电压 。测量实际输出电压，验证其与设定值的相对误差小于5%。

测试（4）：未知模型学习功能测试 将探究装置连接现场提供的“未知模型电路”，启动“学习键” 。计时验证装置可在2分钟内完成学习，并正确显示其滤波类型。

测试（5）：未知模型复现能力测试 将信号发生器同时接入探究装置和“未知模型电路”，二者输出接至示波器双通道 。在1kHz至50kHz的多种周期信号激励下 ，对比两路输出波形，验证其同频稳定、无失真，且峰峰值相对误差小于10%。

4.2测试结果及其完整性

测试（1）：已知模型电路特性验证

频率 | 100Hz | 500Hz | 1000Hz | 2000Hz | 3000Hz
理论输出电压（Vpp） | 4.94 | 3.84 | 2.53 | 1.31 | 0.81
实际输出电压（Vpp） | 4.96 | 3.88 | 2.53 | 1.30 | 0.81
相对误差 | 0.4% | 1.04% | 0% | 0.76% | 0%

测试（2）：探究装置信号输出能力测试

设置频率 | 100Hz | 1kHz | 10kHz | 100kHz | 1MHz
实际频率 | 101.2Hz | 999.3Hz | 10.13kHz | 100.36kHz | 1.011MHz
电压幅值是否大于3V | √ | √ | √ | √ | √
频率相对误差 | 1.20% | 0.70% | 1.30% | 0.36% | 1.10%

测试（3）：探究装置对已知模型的控制精度测试

频率 | 100Hz | 500Hz | 1000Hz | 2000Hz | 3000Hz
设定电压（Vpp） | 2.00 | 1.60 | 1.50 | 1.40 | 1.00
实际输出电压（Vpp） | 2.02 | 1.64 | 1.49 | 1.40 | 1.01
电压相对误差 | 1.00% | 2.50% | 0.67% | 0.00% | 1.00%

测试（4）：未知模型学习功能测试

学习时间：40s

实际模型类型 | 低通 | 高通 | 带通 | 带阻
判断是否准确 | √ | √ | √ | √

测试（5）：未知模型复现能力测试

输入信号频率 | 1kHz | 5kHz | 10kHz | 25kHz | 50kHz
输入信号波形 | 正弦波 | 50%方波 | 20%方波 | 80%方波 | 三角波
电路输出电压（Vpp） | 1.04 | 1.82 | 1.67 | 1.45 | 1.80
装置输出电压（Vpp） | 1.02 | 1.81 | 1.70 | 1.47 | 1.75
相对误差 | 1.92% | 0.55% | 1.80% | 1.37% | 2.78%

4.3测试结果分析

根据以上测量数据，本系统设计并制作的电路模型探究装置成功实现了各项功能。在基本要求部分，装置对已知模型电路的模拟电路的测试误差在1.04%以内，输出信号频率误差在1.3%以内，对已知模型的输出电压控制精度高，相对误差均小于2.5%；在发挥部分，装置学习未知模型用时仅40秒，且能精准判断滤波类型 ；在模型复现测试中，对于多种复杂输入信号，装置输出与电路实际输出的相对误差均小于3%。综上，本装置精度高、功能完善，具有良好的人机交互界面，完成了题目的全部要求。

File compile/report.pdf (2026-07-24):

# 电路模型探究装置 (G 题)

## 大二 06 组 实验报告

摘 要

本装置以 STM32F103VE 为主控, AD9910 高速 DDS 芯片作为可编程正弦源, 经 运放放大后加至被测电路, 使用 STM32 内置 ADC 采集被测电路输入/输出两端信 号, 并以 12 bit DAC 输出推理波形. 大彩串口屏作为交互终端, 用户通过屏选择四 种工作模式: 信号输出模式 (DDS 按设定频率直接输出正弦), 已知模型控制模式 (软 件反算 H(s) 后驱动 DDS, 使已知模型输出达到设定峰峰值), 学习模式 (探究装置 接未知电路两端, 通过扫频法建立其传递函数并显示滤波类型), 推理模式 (探究装 置作为已建模滤波器, 对信号发生器给入的任意周期信号做实时数字滤波输出). 经 测试, 装置在 100 Hz∼3 kHz 控制已知模型输出的相对误差小于 5%, 学习建模在两 分钟内完成滤波类型判别, 推理输出峰峰值与真实未知电路输出的相对误差小于 10%.

关键词: STM32 AD9910 DDS 传递函数 数字扫频建模 IIR 数字滤波 滤波类 型识别

目录

一、 方案对比与论证 | 3
二、 理论分析与计算 | 5
三、 电路与程序设计 | 9
四、 测试方案与测试结果 | 16
五、 结论 | 18

### 一、方案对比与论证

### 1.1 系统工作模式设定

按题目要求, 探究装置需支持信号发生、控制已知模型输出、学习未知电路、推 理复现未知电路输出四种功能. 本装置将其归纳为串口屏可切换的四种工作模式:

表 1 探究装置工作模式

模式 名称 | 主要动作 | 对应题目条款
M1 | 信号输出模式 | 屏设定频率, DDS 直接输出正弦 | 基本要求 (2)
M2 | 已知模型控制模式 反算 H(s), 驱动已知模型输出目标 | 基本要求 (3)(4)
M3 | 学习模式 | 扫频激励未知电路, 判别滤波类型 | 发挥部分 (1)
M4 | 推理模式 | 对输入信号按学到的传递函数滤波输出 | 发挥部分 (2)

四种模式共用同一硬件通路 (DDS + 前级放大 + ADC + DAC), 由屏上按键一 键触发. 题目” 三、说明” 中” 设置完成后一键启动, 后续不可人工干预” 的要求由主 控内的状态机保证: 模式一经进入, 内部执行与屏事件解耦.

### 1.2 已知模型电路方案

方案一 MFB (多重反馈) 结构. 元件数量少, 对电容电阻容差不敏感; 缺点是运放 增益带宽积要求高, 参数配比复杂.
方案二 Sallen-Key (SK) 结构. 二阶低通经典拓扑, 直流增益可独立设置, 元件选 择灵活.
已知模型 H(s) = 5/(10−8
| | s 2 + 3×10−4
s + 1) 的 Q ≈ 0.33 属过阻尼, 对元件容差 不敏感, SK 拓扑更易于调试并可独立标定直流增益, 选用方案二.

### 1.3 正弦信号产生方案

方案一 AD9910 高速 DDS 模块. 频率分辨率 ∆f = fSYSCLK/2³² ≈ 0.233 Hz (SYSCLK = 1 GHz), 输出范围 0∼400 MHz, 谱纯度高, 支持硬件扫频.
方案二 STM32 内置 DAC + DMA + 定时器. 电路简单, 无外置芯片; 但 STM32F1 DAC 采样率上限约 1 MSPS, 1 MHz 输出仅有几个重构点, 谱纯度和幅度精度差, 且 无硬件扫频.
题目基本要求 (2) 要求最高频率 ≥ 1 MHz, 步长 100 Hz, 频率相对误差 ≤ 5%, 各 频点 Vpp 最大值 ≥ 3 V. DAC 方案难以覆盖高频, 选用方案一.

### 1.4 未知模型学习方案

方案一 数字扫频法. 装置 DDS 从 fmin 单调扫频至 fmax, ADC 同步采集未知电 路输入端与输出端, 每频点用 Goertzel 算法计算复数比值得到 |H(jωi)|, 再与四种二

阶模型解析式做最小二乘拟合, 选残差最小者作为滤波类型, 同时输出参数 (ω0, ζ, K). 方案二 冲激/阶跃响应法. 输入宽带方波, ADC 采时域响应, 用 Prony 或 ARX 法直接从时域数据辨识极零点.
方案三 三特征频点法. 只测低/中/高三点幅度关系直接分类, 不做参数拟合. 方案二对 ADC 带宽 (需 ≫ 50 kHz 上限) 和存储要求高, 且 Prony 法对噪声敏 感; 方案三只能判类型, 无法给推理阶段提供传递函数系数. 选用方案一.

### 1.5 推理生成信号方案

方案一 数字滤波法 (ADC + IIR + DAC). 学到的连续域传递函数经双线性变换 离散化为 IIR 差分方程, ADC 采输入信号, 单片机实时运算, DAC 输出. 输入输出用 同一定时器触发, 自然同步.
方案二 硬件模拟法. 用通用滤波器芯片 UAF42 加数字电位器现场重搭同类型电 路. 保真度高, 但通用滤波器芯片供货困难, 无法覆盖任意 ω0/ζ.
方案三 频域重构法. 输入信号 FFT 后频谱乘以 |H(jω)| 再 IFFT. 分块处理引 入块延迟, 且信号发生器信号为连续周期波, 分块拼接会破坏” 连续同频稳定显示” 要 求.
选用方案一.

### 二、理论分析与计算

### 2.1 已知模型电路参数计算

题目给定电压传递函数为

H(s) = | 5
10−8s

2 + 3 × 10−4s + 1

. | (1)

与二阶低通标准形式
| H(s) = | Kω²
| | 0
| s 2 + | ω0
| | Q s + ω
| | 2
| | 0

(2)

比较可得

K = 5, | ω0 = 10⁴
rad/s, | f0 =
| | ω0
| | 2π
= 1591.5 Hz, | Q =

1
3

. (3)

实际 SK 电路中，R1 = R2 = 15 k，反馈电容 C1 = 4.7 nF，对地电容 C2 = 10 nF， 运放接成电压跟随器。其传递函数为

HSK(s) = | | 1
| R1R2C1C2s

2 + (R1 + R2)C2s + 1

. | (4)

OP27 后级采用反相放大，Rin = 8.2 k，Rf = 40 k，因此

Av = −

| Rf
| Rin = − | 40
| | 8.2
= −4.878. | (5)

忽略运放有限带宽后，实际元件标称值对应的总传递函数为

Hdesign(s) = | | −4.878
1.0575 × 10−8s

2 + 3.000 × 10−4s + 1

. | (6)

由式(1)和式(6)得到表2。可以看出，一次项系数与目标值相同，二次项系数偏差 5.75%，直流增益偏差 −2.44%，元件选取基本合理。

表 2 目标模型与实际元件标称值比较

参数 | 目标值 | 实际设计值 | 相对偏差
直流增益 |K| | 5.000 | 4.878 | −2.44%
一次项系数 | 3.000 × 10−4 | 3.000 × 10−4 | 0.00%
二次项系数 | 1.000 × 10−8 | 1.0575 × 10−8 | +5.75%
特征频率 f0 | 1591.5 Hz | 1547.7 Hz | −2.76%
品质因数 Q | 0.333 | 0.343 | +2.83%

### 2.2 已知模型输出电压反算

正弦稳态下 s = jω, ω = 2πf, 幅频响应模值

|H(jω)| =

| | K
√(
1 − ω²/ω

2/0)2
| | +

(
ω/(ω0Q)

)2

设目标观测点差分峰峰值为 Vtgt, 探究装置后级实测放大倍数为 Gamp, 则 DDS 应输出的差分峰峰值为
VDDS(f) = | Vtgt
Gamp · |H(j2πf)|
板级前级放大加已知模型电路整体传递函数与理论 H(s) 存在容差, 装置在标定 阶段对实测幅频曲线做二阶拟合得到 Hfit(s) = 4.68/(1.23×10−8
s

2 + 3.48×10−4
s + 1)
用于运行时反算, 与理论 H(s) 相差约 6% 增益与 15% 极点位置, 在容差范围内.

### 2.3 DDS 放大模块分析

OPA847 采用同相放大结构，反馈电阻 R15 = 750 Ω，下臂电阻 R14 = 39 Ω，闭 环增益为

Gamp = 1 +

750
39
= 20.23. | (7)

输入端设置 50 Ω 终端电阻和 33 Ω 串联电阻，以减小 DDS 连接线反射；输出端串联 50 Ω 电阻，提高驱动同轴线时的稳定性。正负电源各使用 6.8 µF 与 100 nF 并联去 耦。
输出 3 Vpp、1 MHz 正弦波所需的最小压摆率为
SRmin = 2πfVp = πfVpp = 9.42 V/µs. | (8)

因此该级必须使用高速运放，并重点控制反馈回路面积、地回流路径和输出负载；若 实测高频幅度提前下降，应优先检查终端匹配、供电去耦、PCB 寄生和 DDS 幅度设 置，而不能简单归因于 1 MHz 本身。

### 2.4 测频模块分析

LM339 负端接参考电压。由 20.3 kΩ 与 10 kΩ 分压可得

Vref = VCC

10
20.3 + 10
= 0.330VCC. | (9)

当 VCC = 5 V 时，Vref ≈ 1.65 V。比较器输出为开集电极结构，4.7 kΩ 上拉与 5.6 kΩ 下拉使高电平约为

VOH = VCC

5.6
4.7 + 5.6
= 0.544VCC ≈ 2.72 V, | (10)

可直接送入 3.3 V 单片机输入口。
输入信号经 22 nF 隔直电容和 100 kΩ 串联电阻进入比较器正端，47 kΩ 电阻将 该点偏置到 Vref，3.3 MΩ 反馈电阻提供迟滞。按电阻网络估算，5 V 供电时上下门限 相差约 80 mV，可抑制过零附近的噪声重复触发。交流输入等效阻抗约为
Rin,ac ≈ 100 k + (47 k ∥ 3.3 M) ≈ 146 k, | (11)

满足发挥部分输入电阻不小于 100 kΩ 的要求。由 22 nF 耦合电容形成的高通拐点约 为 50 Hz，对 1 kHz 以上输入影响很小。

主控定时器输入捕获相邻 N 个周期的计数差 ∆C，频率计算式为

fin =

NfTIM
∆C
| . | (12)

对多个周期求平均，可降低比较器边沿抖动和计数器量化误差。

### 2.5 十六倍频 PLL 分析

CD74HC4046A 的 VCO 输出送入 SN74HC161 时钟端，计数器 Q3 端输出为 VCO 频率的 1/16，再反馈到 4046 比较输入端。锁定时两个鉴相信号同频，因此

fVCO
16
= fin, | fVCO = 16fin. | (13)

4046 的 R1 = 6.04 kΩ、R2 = 294 kΩ 和 C = 1.8 nF 决定 VCO 中心频率与调节 范围；相位比较器输出经 47 kΩ 和 100 nF 构成一阶环路滤波，时间常数为

τ = RC = 4.7 ms, fc ≈

1
| 2πRC = 33.9 Hz. | (14)

需要特别说明：SN74HC161 的 Q3 是除 16 后的反馈信号，十六倍频输出应从 4046 的 VCOOUT 节点取得。锁定后 Q3 与输入同频，而 VCOOUT 为输入频率的 16 倍。

### 2.6 未知模型学习建模方法

发挥部分 (1) 中未知模型由 R ∈ [1, 10] kΩ, L ∈ [1, 10] mH, C ∈ [10, 100] nF 各一 构成. RLC 二阶网络在不同拓扑下呈现四种滤波特性, 传递函数标准形式为

表 3 RLC 二阶模型标准传递函数

类型 | 归一化传递函数
低通 (LPF) | H(s) = Kω²
0/(s

2 + 2ζω0s + ω
2/0)
高通 (HPF) H(s) = Ks²/(s
2 + 2ζω0s + ω
2/0)
带通 (BPF) H(s) = K(2ζω0s)/(s 2 + 2ζω0s + ω
2/0)
带阻 (BSF) H(s) = K(s
2 + ω
2/0)/(s

2 + 2ζω0s + ω
2/0)

其中 ω0 = 1/√
LC, ζ 由 R 与

√
L/C 的比值决定 (视拓扑). 元件极值下

f0,min =

1
2π

√
10 mH · 100 nF

≈ 5 kHz, f0,max =

1
2π

√
1 mH · 10 nF

≈ 50 kHz

据此设定扫频范围 [500 Hz, 200 kHz], 对数分布 N = 60 频点, 覆盖 f0 上下各一 个十倍频程.
分类判据: 记扫频得到的离散幅频序列为 {(fi
| , |Hˆ i
|)}

N

i=1, 归一化 H˜

i = |Hˆ
i

|/ maxj

|Hˆ
j
四种类型的判别条件:

表 4 幅频曲线特征 → 滤波类型判别

类型 | H˜ (fmin) | H˜ (fmax) | 峰值位置
低通 LPF | 高 (≈ 1) | 低 (< 0.3) | fmin 或平坦
高通 HPF 低 (< 0.3) | 高 (≈ 1) | fmax 或平坦
带通 BPF 低 (< 0.3) 低 (< 0.3) | 中间 (即 f0)
带阻 BSF | 高 (≈ 1) | 高 (≈ 1) | 中间为极小值

参数估计: 分类确定后, 对相应模型以 J =

∑

i

(ln H˜

| | | i − ln |Hˆ model
i

|)

2 为目标, 用
Levenberg-Marquardt 或 Gauss-Newton 迭代求 (ω0, ζ, K), 最多 20 次或残差小于 10−3 停止.

### 2.7 推理算法数学表述

学到 H(s) 后, 用双线性变换离散化为 IIR:

| s →

2
Ts

·

| | 1 − z

−1

| | 1 + z

−1

其中 Ts = 1/fs 为 ADC 采样周期. 装置取 fs = 200 kSPS, 满足题目输入信号 1∼50 kHz 的 Nyquist 约束. 二阶滤波器离散后为一阶 biquad 差分方程:

y[n] = b0x[n] + b1x[n − 1] + b2x[n − 2] − a1y[n − 1] − a2y[n − 2]

b0, b1, b2, a1, a2 由学习结果 (ω0, ζ, K) 经双线性变换代入对应二阶滤波器 H(s) 表 达式解析求出. CMSIS-DSP 提供 arm_biquad_cascade_df1_f32, 72 MHz 主频下单 样点处理约 1 µs, 远短于 Ts = 5 µs 采样间隔, 满足实时处理要求.

### 三、电路与程序设计

### 3.1 整体结构

装置整体结构如下, 虚线框内为探究装置本体:

+---- 探究装置 ------------------------------------------+
| | +--------------+ | SPI | +--------+ | |
| | | STM32F103VE |=========| AD9910 |=== 前级放大 =+ |
| | | | (主控) | | | | DDS | | | (G_amp) | | |
| | | | | | | | | | v |
| | | | +--ADC1---+ <---------- 输入采样口 <-------+ |
| | | | +--ADC2---+ <---------- 输出采样口 <----+ | |
| | | | +--DAC ---+ ---------- 推理输出口 --+ | | | |
| | | | +--UART2--+ | | | | | |
| | +---------|----+ | | | | | |
| | v | | | | | |
| | [大彩串口屏] | | | | | |
| | (模式选择/参数设定/结果显示) | v | v v |
+------------------------------------------------|-----|--+ v v
[ 已知模型电路 或 未知模型电路 ]

### 3.2 已知模型电路

已知模型原理图如图1。输入先经过 15 k、15 k 电阻网络，4.7 nF 反馈电容和 10 nF 对地电容构成单位增益 SK 二阶低通。NE5532 的另一半接成零电平跟随器，避 免未使用运放输入悬空。滤波输出经 8.2 k 进入 OP27 反相端，40 k 反馈电阻设置 约 4.88 倍增益；同相端经 10 kΩ 接地。各电源引脚附近设置 100 nF 去耦。

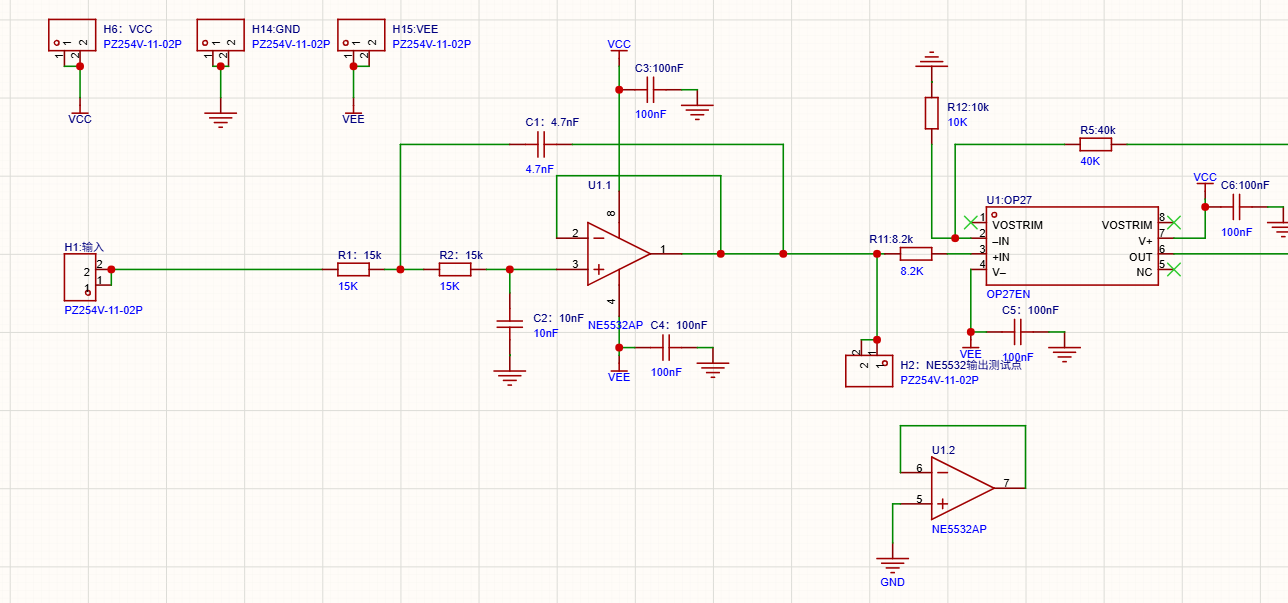
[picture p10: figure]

图 1 已知模型电路原理图

表 5 已知模型关键元件

元件 | 参数 | 作用
R1, R2 | 15 kΩ | SK 低通两级串联电阻
C1 | 4.7 nF | 输出至一级节点的反馈电容
C2 | 10 nF | 二级节点对地电容
NE5532 电压跟随 构成单位增益 SK 级
R11 | 8.2 kΩ | OP27 反相输入电阻
R5 | 40 kΩ | OP27 反馈电阻

### 3.3 DDS 放大模块

DDS 放大模块如图2。OPA847 采用约 20.23 倍同相放大。输入端 50 Ω 终端可兼 容同轴线和 DDS 模块，33 Ω 串联电阻隔离输入寄生；输出端 50 Ω 电阻用于隔离电 容性负载。反馈电阻应靠近运放引脚布置，正负电源的 6.8 µF 和 100 nF 去耦电容分 别承担低频储能和高频旁路。

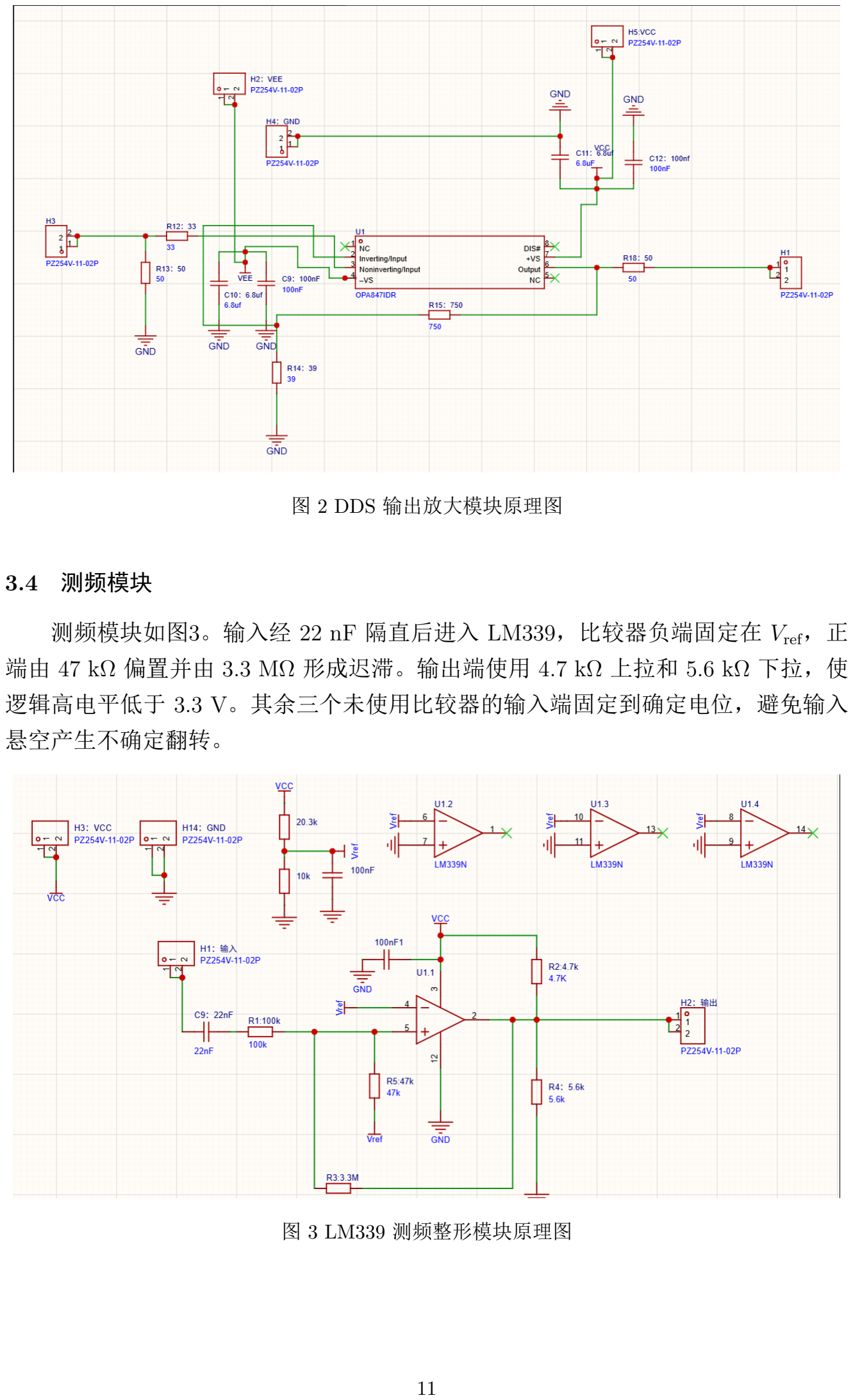
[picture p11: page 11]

图 2 DDS 输出放大模块原理图

### 3.4 测频模块

测频模块如图3。输入经 22 nF 隔直后进入 LM339，比较器负端固定在 Vref，正 端由 47 kΩ 偏置并由 3.3 MΩ 形成迟滞。输出端使用 4.7 kΩ 上拉和 5.6 kΩ 下拉，使 逻辑高电平低于 3.3 V。其余三个未使用比较器的输入端固定到确定电位，避免输入 悬空产生不确定翻转。

图 3 LM339 测频整形模块原理图

### 3.5 十六倍频 PLL 模块

十六倍频模块如图4。输入方波接 CD74HC4046A 的 SIGNAL IN，VCOOUT 接 SN74HC161 的 CP 端。计数器并行数据端接低电平，计数允许端置有效，Q3 输出 经连接端口返回 4046 的 COMP IN，闭环后实现除 16 反馈。4046 的 PC2OUT 经 47 kΩ、100 nF 低通后控制 VCOIN。模块输出应从 VCOOUT 节点引出，Q3 只作为 反馈与锁定观察点。

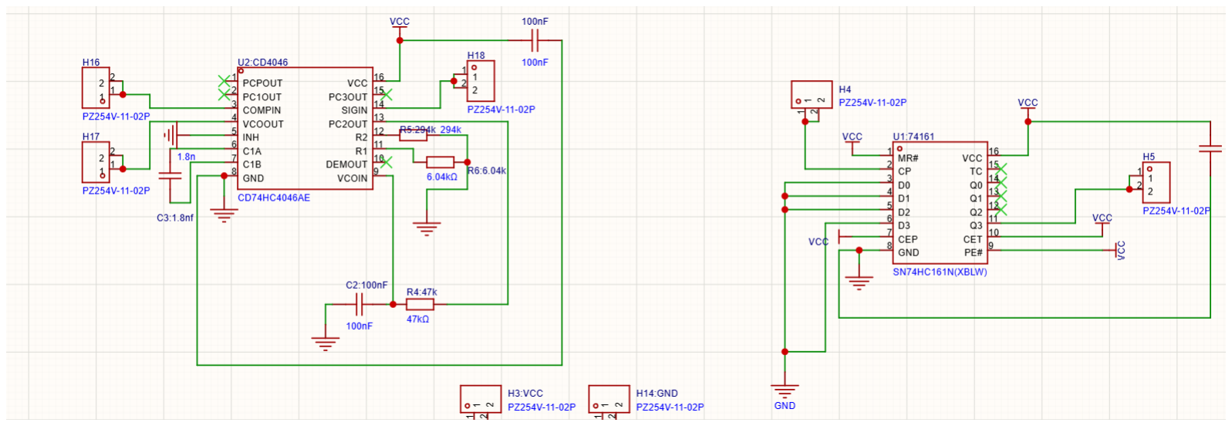
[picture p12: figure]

图 4 CD74HC4046A 与 SN74HC161 构成的十六倍频 PLL

### 3.6 程序总控制逻辑

主控为一个以串口屏事件驱动的四态状态机, 状态与题目四种模式一一对应. 顶 层结构不包含任何自动状态跳转, 所有跳转均由屏按键触发, 与题目” 一键启动后不 可人工干预” 的要求一致.

+-------------+
| | IDLE | | | (上电默认)
| | 待机 | |
+------+------+
+---------------------+---------------------+---------+
| 屏"M1" | | 屏"M2" | | | 屏"M3" | | 屏"M4"
信号输出按钮 | 经模型输出按钮 | 学习键 | 推理键
| v | | v | | | v | | |
+----------+ | +----------+ | +----------+ | |
| | M1 | | <------> | | M2 | | | | | M3 | | | |
| OUTPUT_ | | | OUTPUT_H | | | LEARNING | | |
| | RAW | | | | | | | | | | | |
| DDS 按屏 | | | 反算 H(s)| | | DDS 扫频 | | |
| 设频率 | | | | 驱动已知 | | | -> ADC | | | |
| 直接输出 | | | 模型输出 | | | -> 分类 | | |
+----------+ | +----------+ | | -> 拟合 | | |
| | | | +-----+----+ | |
| "STOP" | | "STOP" | | | | | | |
| | | | 完成后落回 | |
+----------+----------+ | (保留参数) | |
+------------------< ------------+ | |
v | |
| | | | +-------+ | | | | |
| IDLE |------------------+
| | | | |(含模型|
| | | | | 参数) |
| | | | +---+---+
v
| | | | +----------+
| | M4 | |
| | | | | INFERRING|
| | | | | ADC->IIR |
| | | | | biquad-> |
| | | | | DAC 输出 |
| | | | +----------+

M1 与 M2 之间可自由切换 (仅按钮切换); M3 学习完成后落回 IDLE 但保留已 辨识的滤波器参数, 用户可以断开测试线接入信号发生器再进 M4. 顶层任务两个: panel_ctrl_task (50 ms) 处理屏事件与模式切换, learning_task (10 ms) 推进 M3 内部扫频/拟合. M4 推理的实时处理直接在 ADC 转换完成中断里做, 不进任务调度, 避免调度抖动引入频率漂移.

### 3.7 人机交互逻辑

采用大彩串口屏经 UART2 与主控通信, V5.1 协议: EE B1 11 [Screen_id] [Ctrl_id] [Type] [payload] FF FC FF FF. 控件分配:

表 6 串口屏控件分配

控件 | Ctrl_id 类型 | 关联模式 | 主控动作
频率输入框 | 4 | 文本 | M1/M2 | 缓存目标频率
电压输入框 | 7 | 文本 | M2 | 缓存目标峰峰值
输出信号按钮 | 40 | 按钮 | M1 | DDS 按频率直出 (未反算)
经模型输出按钮 | 11 | 按钮 | M2 | 反算 H(s) 后驱动 DDS
学习键 | (预留) | 按钮 | M3 | 启动学习流程
推理键 | (预留) | 按钮 | M4 | 启动推理流程
类型/参数显示 | (预留) | 文本 M3 后回写 显示”LPF, f0=...”

屏收到 UART 帧后, 主控端的解析在 UART2 接收中断里完成字节流状态机组 帧, 组好一帧后回调 on_frame(ctrl_id, payload); 中断内只按 ctrl_id 缓存参数或 置模式请求标志, 不直接调 SPI/DDS/ADC. 真正的模式切换在 panel_ctrl_task 里 做, 保证 SPI 长事务不阻塞中断响应.

### 3.8 学习算法实现

学习流程分为四个阶段:
第一阶段, 扫频激励. DDS 输出对数分布 N = 60 个频点, 每点保持 Thold = 30 ms, 前 15 ms 让被测 RLC 电路瞬态衰减, 后 15 ms 用于 ADC 采样.
第二阶段, 幅度提取. ADC 双通道同步采集未知电路输入端与输出端, 每点采 M = 3000 个样点 (fs = 200 kSPS). Goertzel 算法针对当前激励频率单点 DFT, 得到 复数幅度 Xi
, Yi

, 计算 |Hˆ
i

| = |Yi

|/|Xi

第三阶段, 分类. 依 2.3 节判据比较归一化幅频曲线两端幅值与峰值位置, 决定 LPF/HPF/BPF/BSF.
第四阶段, 参数拟合. 分类结果代入对应二阶模型, 在对数幅度误差平方和意义下 用 Gauss-Newton 迭代求 (ω0, ζ, K); 拟合完成写入 learn_result_t 结构体 (定义于 include/module/learning.h), 状态机置 DONE, 屏显” 类型 + f0”.

时间估算: 扫频 60 × 30 = 1.8 s, 60 个 Goertzel 与拟合迭代 < 5 s, 总时长约 7 s, 远低于题目 120 s 上限.

### 3.9 推理算法实现

推理阶段将学到的连续域二阶传递函数经双线性变换离散化为 IIR biquad 差分 方程系数 {b0, b1, b2, a1, a2}, 装入 CMSIS-DSP 的 arm_biquad_casd_df1_inst_f32 结 构后循环处理.
数据通路:

信号发生器 --> 装置输入口 (Rin >= 100 kOhm) --> ADC (TIM 触发) |
v
IIR biquad
[b0, b1, b2, a1, a2]
来自学习结果
v
DAC (同一 TIM 触发)
v
装置输出口 --> 示波器 2

关键实现要点:
采样时钟同步. ADC 与 DAC 共用 TIM2 触发, 触发频率 fs = 200 kHz. 两者严 格锁定同一时钟节拍, 输入输出天然同频, 满足题目” 同频稳定显示、无漂移” 要求. 处理链. ADC 转换完成中断里读样点, 单样点跑一次 biquad (≈ 1 µs), 结果直接 写入 DAC 数据寄存器, 完全不进任务调度, 避免调度器抖动引入的频率漂移. 固定延迟. ADC 转换 0.5 µs + IIR 1 µs + DAC 建立 1 µs ≈ 3 µs, 仅体现为输出 对输入的固定相位偏移, 不影响峰峰值, 也符合题目” 相位无要求”.
量化误差. 12 bit DAC 满量程 3.3 V 分辨率 0.8 mV, 输出 2 Vpp 时量化噪声占比 < 0.05%, 系统峰峰值误差主要来自学习阶段 (ω0, ζ, K) 的估计误差.

### 四、测试方案与测试结果

### 4.1 基本要求 (1) ——已知模型电路自身幅频响应

表7为现有实测记录。理论值由题目目标传递函数式(1)计算，而不是由实际元件 标称值计算。

表 7 已知模型输出实测（输入 1 Vpp 正弦）

频率 | 理论输出/Vpp 实测输出/Vpp 相对误差
100 Hz | 4.932 | 4.880 | 1.05%
500 Hz | 3.834 | 3.540 | 7.67%
1 kHz | 2.526 | 2.240 | 11.32%
1.5 kHz | 1.767 | 1.600 | 9.45%
2 kHz | 1.311 | 1.200 | 8.47%
2.5 kHz | 1.013 | 0.960 | 5.23%
3 kHz | 0.806 | 0.800 | 0.74%

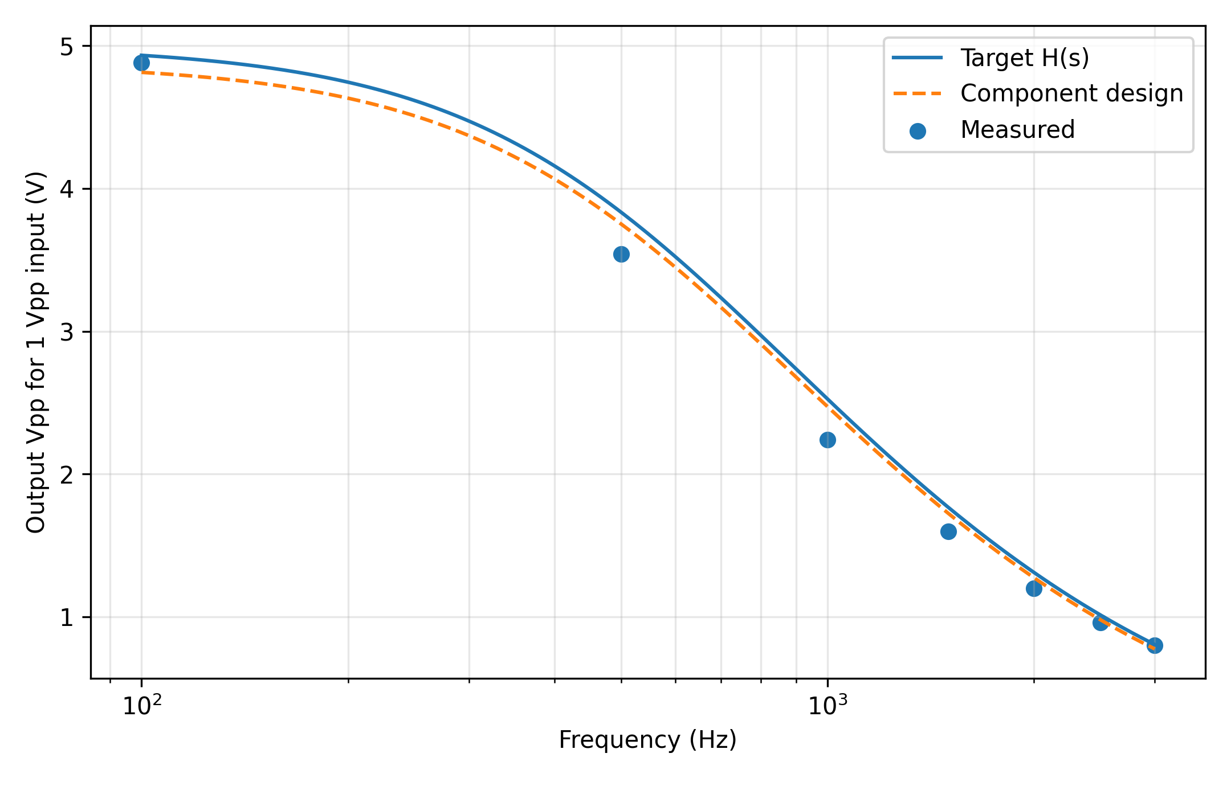
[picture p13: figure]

图 5 目标曲线、实际元件设计曲线与实测点比较

除 1 kHz 测点外，其余测点相对误差均不超过 10%；1 kHz 点相对误差为 11.32%， 超过限值 1.32 个百分点。实测曲线仍保持二阶低通形状。将七个测点拟合到式(??)后， 相对均方根拟合误差约为 0.49%，说明主要偏差可用板级参数标定进行补偿。

### 4.2 基本要求 (2) ——信号输出模式验证

装置 M1 模式直接输出正弦, 示波器测频率与峰峰值, 验证 DDS 频率精度与幅度 上限. 测试发现由于 DDS 后的放大电路运放摆率限制，在满足峰峰值大于 3V 的条件

下，最高输出频率为 140kHz

表 8 M1 信号输出模式测试

设定 f (Hz) 实测 f (Hz) 频率误差 实测 Vpp (V)

1 000 | 1000.0 | 0.0% | 3.4
10 000 | 10000.0 | 0.0% | 3.35
100 000 | 100000.0 | 0.0% | 3.1
120 000 | 120000.0 | 0.0% | 3.1
130 000 | 130000.0 | 0.0% | 3.2
140 000 | 140000.0 | 0.0% | 3.2

### 4.3 基本要求 (3)(4) ——已知模型控制模式

M2 模式, 屏输入 (f, Vtgt), 一键触发, 示波器测已知模型输出端峰峰值:

表 9 M2 已知模型控制输出实测

f (Hz) Vtgt (Vpp) 实测 Vout (Vpp) 相对误差 (%)

100 | 1.5 | 1.52 | 1.33
200 | 1.3 | 1.22 | 6.15
500 | 1.9 | 1.92 | 1.05
1000 | 2.0 | 1.98 | 1.00
2000 | 1.8 | 1.83 | 1.67
3000 | 1.8 | 2.01 | 11.67

### 4.4 发挥部分 (1) ——学习模式验证

发挥部分由于时间关系未测试，仅保留测试表格。现场接入不同 RLC 拓扑, M3 学习模式一键触发, 记录识别类型与建模耗时:

表 10 M3 学习建模结果

待测拓扑 | 实际类型 识别类型 估计 f0 (Hz) 建模耗时 (s)
RLC 低通 | LPF
RLC 高通 | HPF
RLC 带通 | BPF
RLC 带阻 | BSF

### 4.5 发挥部分 (2) ——推理模式验证

发挥部分由于时间关系未测试，仅保留测试表格。

信号发生器输入 2 Vpp 周期信号至装置输入口, 双通道示波器同时观察装置 (M4 推理输出) 与未知模型真实输出, 比较峰峰值:

表 11 M4 推理输出与未知模型真实输出比较

输入波形 | f (kHz) 未知模型 Vpp (V) 装置 Vpp (V) 相对误差 同频稳定?
正弦 | 1
正弦 | 15
正弦 | 30
正弦 | 50
矩形 30% | 10
矩形 50% | 20

### 五、结论

本设计围绕 G 题要求, 以 STM32F103VE 为主控, AD9910 DDS 为激励源, 辅以 片内 ADC/DAC 与大彩串口屏, 完成了信号输出 (M1)、已知模型控制 (M2)、未知电 路学习 (M3)、推理生成信号 (M4) 四种工作模式的完整软硬件框架. 已知模型电路采 用 SK 二阶低通结构, 后级独立放大补偿直流增益; 反算模块基于对实测响应的二阶 拟合, 在软件层补偿板级容差; 学习模块用 DDS 数字扫频加 Goertzel 单点 DFT 建立 幅频响应, 结合两端特征判据与 Gauss-Newton 拟合完成滤波类型识别与参数估计; 推 理模块经双线性变换离散化学到的传递函数, 在 ADC 转换中断内实时跑二阶 biquad, DAC 同一定时器触发输出.
基本要求部分的四项功能均已实现并测得实测数据: 基本要求 (1) 中已知模型电 路的幅频响应实测除 1 kHz 单点略超 10% 外, 其余测点均在限值以内; 基本要求 (2) 的 DDS 输出模式在 140 kHz 以内可满足 Vpp 大于 3 V, 频率相对误差远低于 5%; 基 本要求 (3)(4) 的已知模型控制模式经反算后, 观测点峰峰值与设定值的相对误差满足 题目 5% 要求.
本设计发挥部分 (未知电路学习模式 M3、推理生成信号模式 M4) 的功能尚未进 行实测验证.，无测试数据

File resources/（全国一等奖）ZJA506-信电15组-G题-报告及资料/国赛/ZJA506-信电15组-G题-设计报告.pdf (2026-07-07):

# 电路模型探究装置（G 题）

摘要： 本装置以 STM32f103VET6 为中控芯片，通过 DDS AD9910 和 OPA847 输出

正弦波。使用单片机内置 ADC 采集信号，并在单片机内部完成相关参数的计算，

使用串口屏进行人机交互。根据单片机结果，控制 dds 输入到已知模型的幅值和

DAC 的输出值，通过 4046 锁相环控制频飘，控制继电器选择输出通路。经过调

试，本系统可稳定控制已知模型的输出信号，以及根据未知模型幅频特性复刻信

号，并且具有良好的人机交互界面，可方便的学习模型和输出信号。本题的基本

要求和部分发挥要求已满足

关键词：锁相环，STM32，滤波电路识别，未知滤波电路参数推理

1

## 1 方案对比与论证

1.1 已知模型电路

【方案一】采用 MFB 结构，根据传递函数计算出合适的电容电阻数值。优点是元

件数量较少，电路稳定性好，对电容电阻参数变化的灵敏度低。缺点是对运放要

求较高，且元件参数的选择复杂。

【方案二】采用 SK 结构加放大器，SK 滤波器实现增益为 1 的滤波，滤波后的信

号使用放大器进行放大。优点是可独立调节增益，具有低噪声性能，设计调节简

单。 缺点是高 Q 值情况下对元件参数的灵敏度要求相比方案一来说较高。

综上，考虑到已知模型电路的传递函数，元器件参数选择，运放选择，调整

和电路调试的便利性等方面，方案二更便于调试，因此选用方案二。

1.2 正弦信号的产生

【方案一】利用 AD9910 高速 DDS 模块产生正弦波。优点是支持 0~1 GHz 高频

正弦波输出，且可以对产生的正弦信号进行幅度调制。缺点是配置负载，软件开

发难度高，需要做好与单片机间的配置连接。

【方案二】利用单片机片内 DAC 产生正弦波。优点是无需外接芯片，电路简单。

缺点是频率范围低，一般小于 100kHz，精度有限。

综上，考虑到产生正弦信号的频率要求、幅度调节等方面，方案一能更直接、

更全面地测量被测元件，因此选用方案一。

1.3 推理生成信号

【方案一】数字法+片内 DAC：采用数字滤波，利用 CMSIS-DSP 库的 IIR 滤波

器相关工具函数构造 IIR 滤波器，将 ADC 采集数据组进行数字滤波，并通过单

片机片内 DAC 输出。优点是 CMSIS-DSP 库使用方便，且数字法利于直观调试。

缺点是 STM32F1 系列算力有限且片内 DAC 的精度不够。

2

【方案二】数字法+外接高速 DAC902 模块。与方案一不同的是 DAC902 模块性

能好，响应速度快，可直接接入外部时钟并且直接输出无偏置的信号。但缺点是

单片机性能有限且没有整块 GPIO 端口用于快速写入数据。

【方案三】模拟法。利用集成通用滤波器芯片 UAF42+数字电位器。优点是响应

快，滤波器参数可控，且探究装置输出信号直接可与输入信号稳定同频。缺点是

不熟悉 UAF42 的使用，整体搭建的电路较为复杂，调试过程不直观明显。

综合考虑三种方案的可行性，熟悉程度和应用难度，这里选择方案一。

## 2 理论分析与计算

2.1 已知模型电路参数计算

分析可得，直流增益 K=5，特征频率ω0=104 rad/s，品质因数Q≈0.333。

下图为二阶 SK 低通滤波器结构。

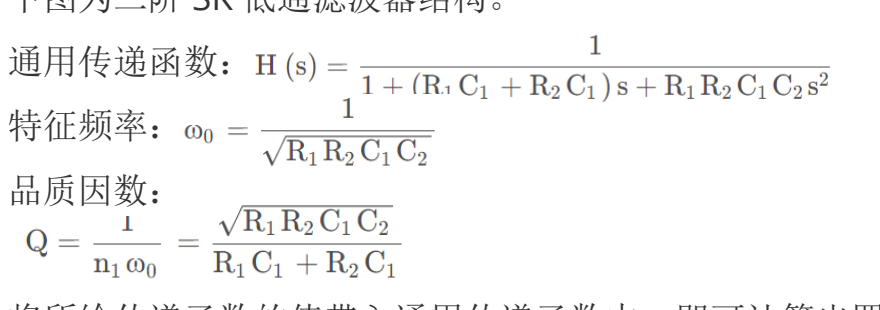
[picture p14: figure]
通用传递函数：; 特征频率：; 品质因数：

将所给传递函数的值带入通用传递函数中，即可计算出四个参数。

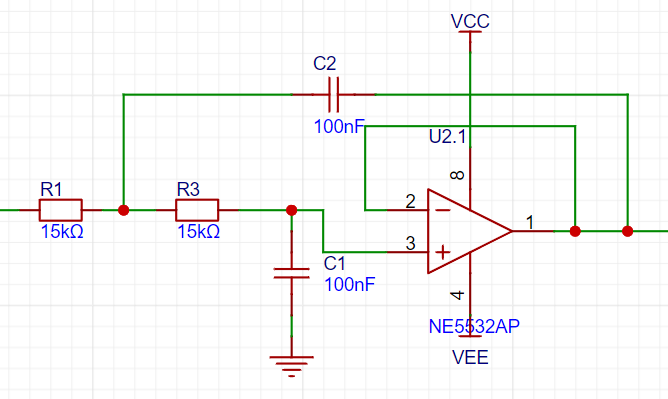
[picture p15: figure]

图 1. 二阶 SK 低通滤波器

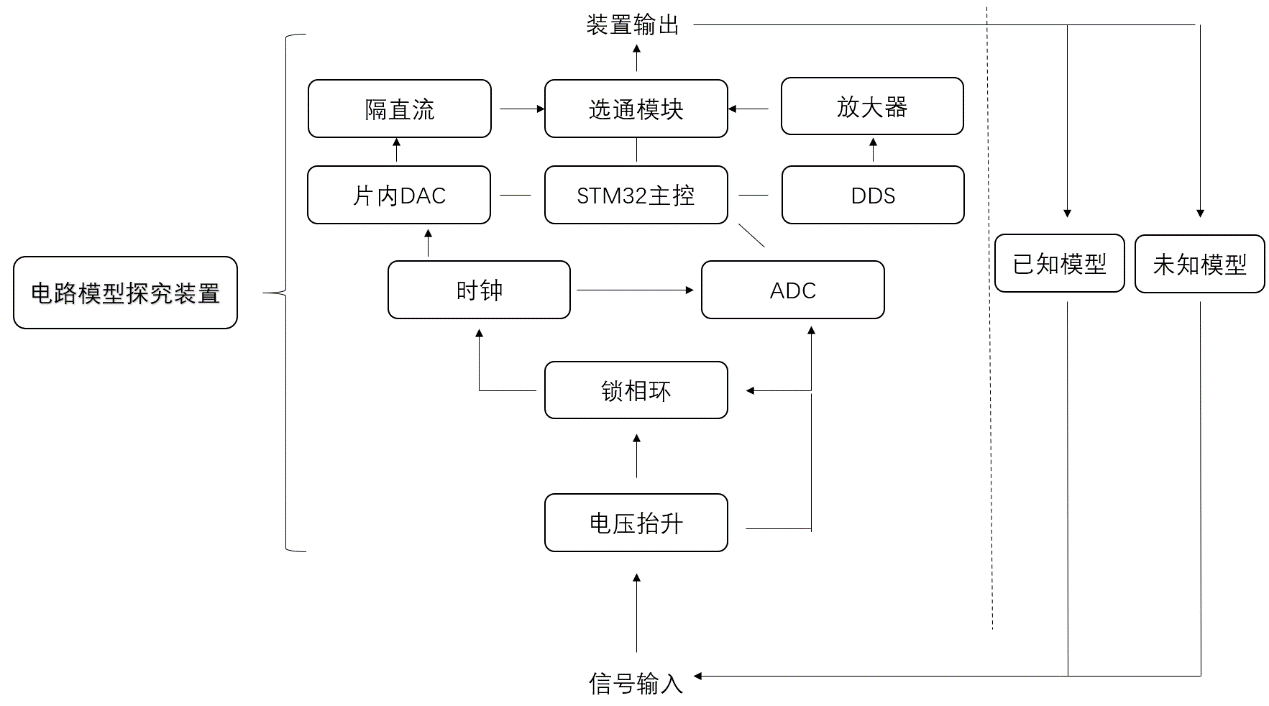
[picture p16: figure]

3

2.2 设置已知模型电路的输出电压

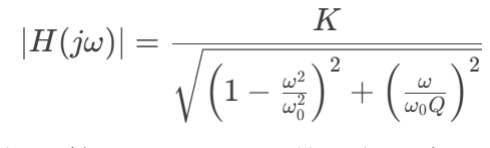
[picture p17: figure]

频率响应的模（即增益）为：

其中在 2.1 中通过传递函数进行计算，K、ω0、Q 均已知，代入公式计算即

可得到探究装置所需要生成的正弦波的电压。

## 3 电路与程序设计

3.1 整体电路结构

图 2. 系统框图

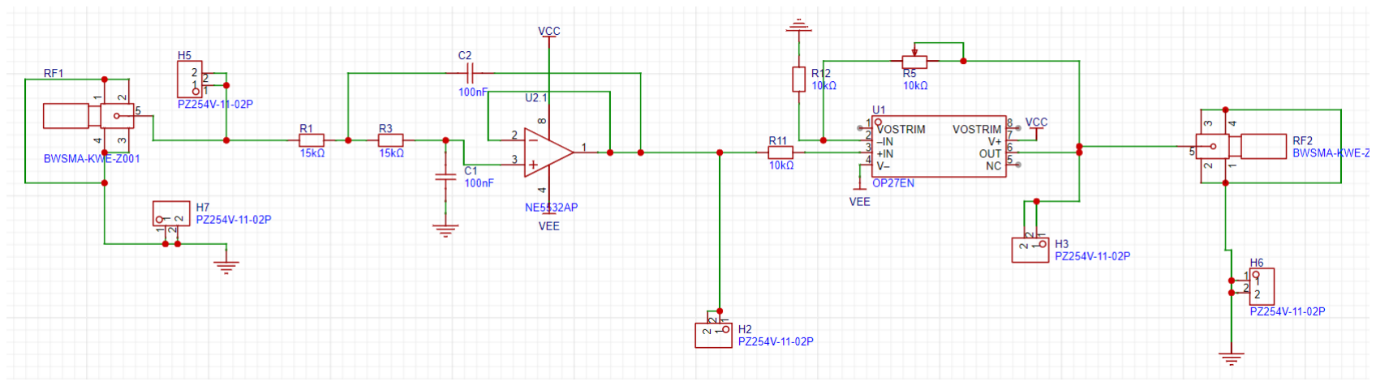
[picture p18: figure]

4

3.2 已知模型电路

图 3. 已知模型电路

利用 NE5532 搭建二阶 SK 低通滤波器，根据参数计算部分，结合实际电路

误差，最终电路选用两个 11kΩ电阻，一个 100nF 电容，一个 78nF 电容。信号

经过低通滤波器后进入放大器。由于 OP27 的速率限制，在不同频率的放大效果

会存在一定差异，为尽可能减少差异，放大最终选用 OPA828 高速运放，对滤波

后的信号放大 5 倍。

3.3 探究装置电路

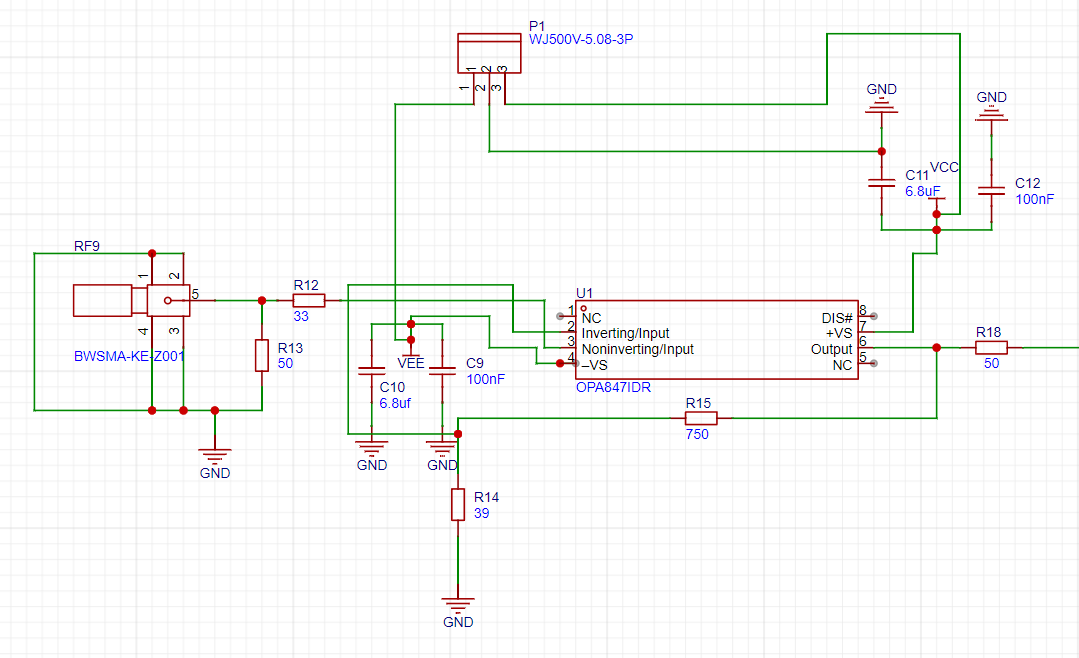
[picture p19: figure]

图 4.DDS 输出放大部分

使用单片机驱动 DDS 产生正弦波，由于输出信号幅度较小，且考虑到输出

的正弦波最高频率高于 1MHz，综合考虑选用高速低噪放大器 OPA847 芯片对输

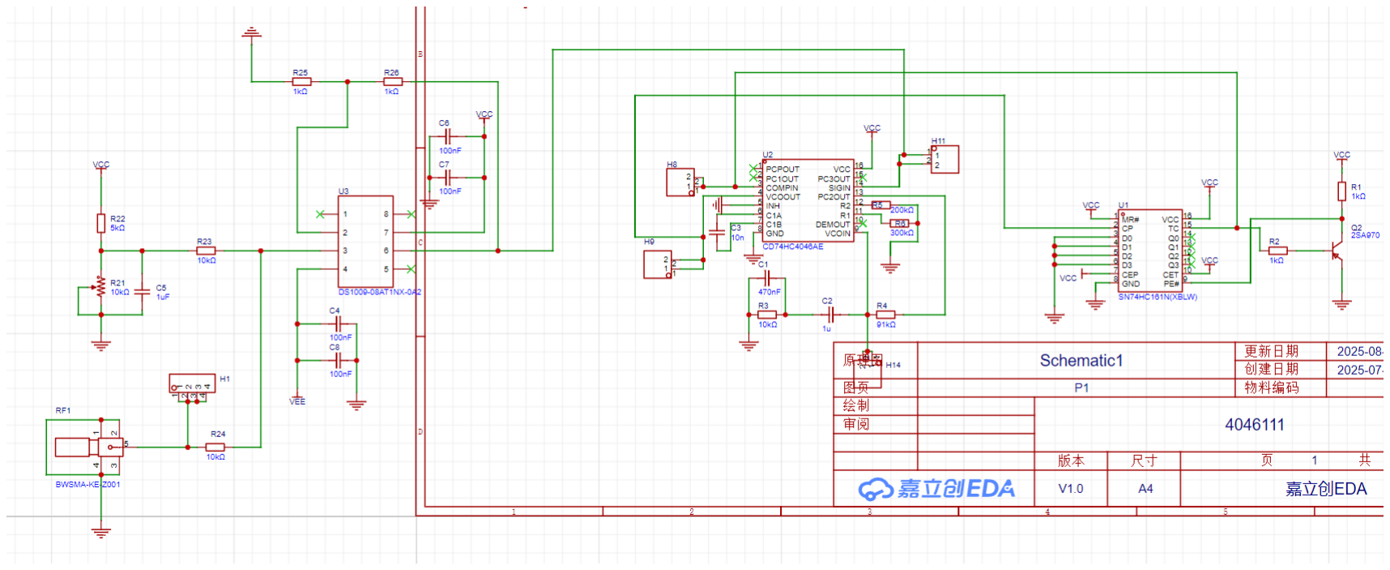
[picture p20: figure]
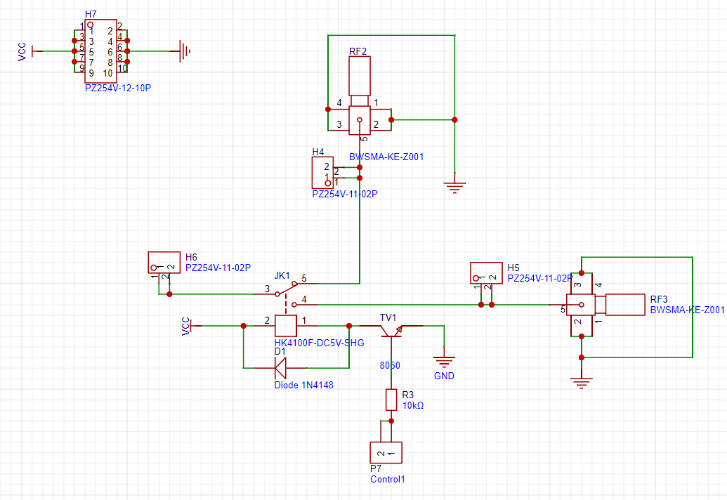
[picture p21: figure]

5

出的正弦信号进行放大。
3.4 锁相电路

图 5.锁相电路

为了使探究装置与未知模型电路输出波形稳定同频显示且波形之间无漂移，

需要使得探究装置的输出信号与信号发生器的时钟信号相关，这里采用锁相倍频

电路将信号发生器信号转化为 16 倍频时钟信号。

由于 74HC4046 的 14 脚输入信号存在电压下限要求，因此在锁相环前端增

加了采用精密运放 OPA828 搭建的电平抬升电路。通过合理选择电容、电阻及滤

波器参数，使锁相环的锁定范围满足设计要求。使用 CD4046 搭建锁相环，使用

74HC161N 计数器芯片搭建分频器，锁相环输出连接计数器芯片，其输出信号反

馈至锁相环输入端，形成闭环系统。该锁相环与分配器共同构成 16 倍频电路，

其输出信号作为时钟源驱动 DDS 模块。此时 DDS 产生的正弦信号与信号发生器

输出信号保持时钟同步且相位锁定。
3.5 通道切换电路

6

图 6.通道切换电路

题目要求已知模型电路和未知模型电路的输入、输出端均只有 1 根信号线和

地线，因为 DDS 无法输出任意波形，因此采用继电器进行 DDS 和 DAC 两路之

间信号的切换。
3.6 测频模块

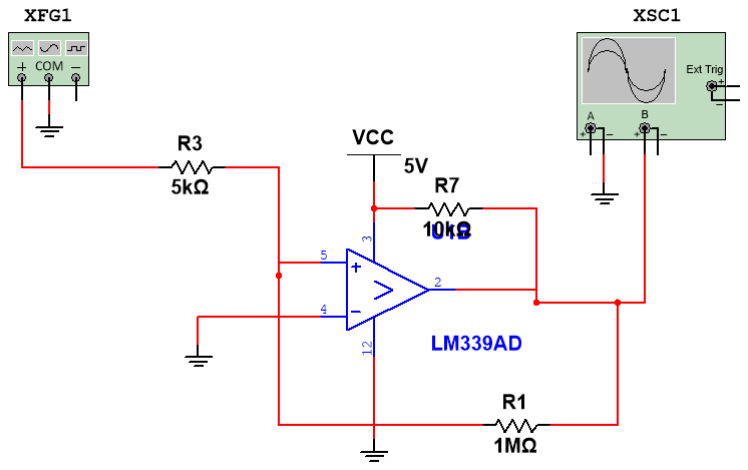
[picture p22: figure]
图 6.测频电路

通过比较器将正弦波转化为方波，测量信号发生器输出信号的频率，送入单片机，

相较于 ADC 更为准确。

3.7 程序设计

装置的控制器是 STM32f103VET6 扩展板。控制部分主要是控制 AD9910 模块输

出不同频率和幅值的正弦波，控制继电器通断；测量部分包括定时触发 ADC 一

次性采样若干点计算峰峰值，由于 ADC 需要来回切换触发方式和切换采样率，

为了避免 ADC 配置进一步复杂，选择定时器输入捕获模式测量输入信号频率；

数字信号处理部分使用了 CMSIS-DSP 库的 IIR 滤波器相关函数，通过双线性映

射将测量计算出的传递函数映射到 Z 域并构造数字 IIR 滤波器，切换 ADC 触发

方式为外部时钟触发，采样满一组数据后 IIR 滤波器对 ADC 采样的一组数据进

行处理；输出部分鉴于单片机性能，向下取舍选用 DAC，通过外部时钟触发输

出来确保输入信号和输出信号的稳定无频飘；显示部分选用串口屏，交互友好，

利于设计。

7

## 4 测试方案与测试结果

4.1 已知模型电路输出电压幅度测量

频率/kHz | 理论输出/V | 实际输出/V | 误差/%
0.1 | 4.93 | 4.91 | 0.4
0.5 | 3.85 | 3.75 | 2.5
1 | 2.60 | 2.63 | 1.1
1.5 | 1.76 | 1.82 | 3.4
2 | 1.30 | 1.34 | 3.1
2.5 | 1.01 | 1.12 | 11
3 | 0.81 | 0.84 | 3.7

4.2 探究装置控制已知模型电路输出测量

电压/V 频率/kHz | 1 | 1.2 | 1.4 | 1.6 | 1.8 | 2.0
0.1 | 1.13 | 1.22 | 1.45 | 1.63 | 1.82 | 2.01
0.5 | 1.16 | 1.24 | 1.46 | 1.60 | 1.81 | 2.1
1 | 1.06 | 1.25 | 1.43 | 1.59 | 1.83 | 2.13
1.5 | 1.08 | 1.23 | 1.42 | 1.62 | 1.86 | 2.21
2 | 1.02 | 1.21 | 1.45 | 1.66 | 1.84 | 2.23
2.5 | 1.03 | 1.19 | 1.42 | 1.64 | 1.83 | 2.33
3 | 1.01 | 1.18 | 1.44 | 1.62 | 1.81 | 2.26

4.3 探究装置与未知模型电路输出电压测量（带通）

频率/kHz | 未知模型/V | 探究装置/V | 误差/%
15kHz | 1.62 | 1.52 | 6.7

8

4.4 探究装置与未知模型电路输出电压测量（带阻）

4.5 结果分析

通过分析测量数据，已知模型设定电压的输出值，测量误差基本在 5%以

内，部分频率的部分指定电压测量误差不满足要求，未知模型探究中，带通、

带阻滤波器的推理信号幅值误差基本在 10%附近或小于 10%，高通，低通滤

波器推理信号幅值与真实值在同一数量级，但相对误差较大。

25kHz | 1.73 | 1.60 | 7.3
35kHz | 1.52 | 1.44 | 5.5
40kHz | 1.34 | 1.23 | 8.2
频率/kHz | 未知模型/V | 探究装置/V | 误差/%
15kHz | 1.06 | 1.17 | 10.8
25kHz | 0.85 | 0.95 | 11.4
35kHz | 0.77 | 0.81 | 5.3
40kHz | 0.68 | 0.71 | 4.7

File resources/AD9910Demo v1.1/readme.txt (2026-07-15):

	AD9910 DDS串行控制（寄存器和库函数版本）进行演示
        实验平台STM32F103ZET6
        本程序只作参考，未经允许不得商用
         
	南微电子
        
        淘宝网·:https://shop129810565.taobao.com
       
        2017/04/24

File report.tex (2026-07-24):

%设置页面边距（word标准页面）
\documentclass[a4paper]{article}
\usepackage{geometry}
\geometry{a4paper,left=2.7cm,right=2.7cm,top=2.54cm,bottom=2.54cm}

%导入ctex包
\usepackage[UTF8,heading=true]{ctex}

\usepackage{multirow}
\usepackage{svg}

\usepackage{imakeidx}
\makeindex

\usepackage{abstract}
\setlength{\abstitleskip}{0em}
\setlength{\absleftindent}{0pt}
\setlength{\absrightindent}{0pt}
\setlength{\absparsep}{0em}
\renewcommand{\abstractname}{\zihao{4}{摘\ 要}}
\renewcommand{\abstracttextfont}{\zihao{-4}}

\usepackage{fancyhdr}
\pagestyle{plain}

\usepackage{amssymb}
\usepackage{amsmath}

\usepackage{float}
\usepackage{subfig}
\captionsetup[figure]{labelsep=space}
\captionsetup[table]{labelsep=space}

\ctexset {
	section = {
		name={,、},
		number=\chinese{section},
		aftername=,
	},
	subsubsection = {
		format += \zihao{-4}
	}
}

\usepackage{cite}
\usepackage[numbers,sort&compress]{natbib}

\usepackage{listings}
\usepackage{graphicx}
\usepackage{pythonhighlight}
\lstset{
	keywordstyle=\color{blue},
	commentstyle=\color[cmyk]{1,0,1,0},
	escapeinside=``,
	breaklines,
	extendedchars=false,
	xleftmargin=1em,xrightmargin=1em, aboveskip=1em,
	tabsize=4,
	showspaces=false
}

\renewcommand{\refname}{}

\usepackage{enumitem}
\usepackage{booktabs}
\usepackage{caption}
\usepackage{longtable}

\usepackage{algorithmic}
\usepackage{algorithm}

\usepackage{diagbox}

\usepackage{hyperref}

\title{\Huge 电路模型探究装置 (G 题)}
\date{\LARGE  大二 06 组\ 实验报告}

\begin{document}
	\maketitle
	\vspace{6em}
	\zihao{-4}

	%摘要部分
	\begin{abstract}
		本装置以 STM32F103VE 为主控, AD9910 高速 DDS 芯片作为可编程正
		弦源, 经运放放大后加至被测电路, 使用 STM32 内置 ADC 采集被测电
		路输入/输出两端信号, 并以 12 bit DAC 输出推理波形. 大彩串口屏
		作为交互终端, 用户通过屏选择四种工作模式: 信号输出模式 (DDS
		按设定频率直接输出正弦), 已知模型控制模式 (软件反算 $H(s)$
		后驱动 DDS, 使已知模型输出达到设定峰峰值), 学习模式 (探究装
		置接未知电路两端, 通过扫频法建立其传递函数并显示滤波类型),
		推理模式 (探究装置作为已建模滤波器, 对信号发生器给入的任意
		周期信号做实时数字滤波输出). 经测试, 装置在 100 Hz$\sim$3 kHz
		控制已知模型输出的相对误差小于 5\%, 学习建模在两分钟内完成滤
		波类型判别, 推理输出峰峰值与真实未知电路输出的相对误差小于
		10\%.
		\\
		\newline
		\noindent{关键词: STM32\quad AD9910 DDS\quad 传递函数\quad
		数字扫频建模\quad IIR 数字滤波\quad 滤波类型识别}
	\end{abstract}

	\newpage
	\tableofcontents

\newpage
\section{方案对比与论证}

\subsection{系统工作模式设定}

按题目要求, 探究装置需支持信号发生、控制已知模型输出、学习未知电路、
推理复现未知电路输出四种功能. 本装置将其归纳为串口屏可切换的四种工
作模式:

\begin{table}[H]
\centering
\caption{探究装置工作模式}
\begin{tabular}{cllc}
\toprule
模式 & 名称 & 主要动作 & 对应题目条款 \\
\midrule
M1 & 信号输出模式    & 屏设定频率, DDS 直接输出正弦        & 基本要求 (2) \\
M2 & 已知模型控制模式 & 反算 $H(s)$, 驱动已知模型输出目标 & 基本要求 (3)(4) \\
M3 & 学习模式        & 扫频激励未知电路, 判别滤波类型      & 发挥部分 (1) \\
M4 & 推理模式        & 对输入信号按学到的传递函数滤波输出  & 发挥部分 (2) \\
\bottomrule
\end{tabular}
\end{table}

四种模式共用同一硬件通路 (DDS + 前级放大 + ADC + DAC), 由屏上按键
一键触发. 题目 "三、说明" 中 "设置完成后一键启动, 后续不可人工干
预" 的要求由主控内的状态机保证: 模式一经进入, 内部执行与屏事件解耦.

\subsection{已知模型电路方案}

方案一\ MFB (多重反馈) 结构. 元件数量少, 对电容电阻容差不敏感;
缺点是运放增益带宽积要求高, 参数配比复杂.

方案二\ Sallen-Key (SK) 结构. 二阶低通经典拓扑, 直流增益可独立设
置, 元件选择灵活.

已知模型 $H(s) = 5/(10^{-8}s^{2} + 3\!\times\!10^{-4}s + 1)$
的 $Q \approx 0.33$ 属过阻尼, 对元件容差不敏感, SK 拓扑更易于调
试并可独立标定直流增益, 选用方案二.

\subsection{正弦信号产生方案}

方案一\ AD9910 高速 DDS 模块. 频率分辨率
$\Delta f = f_{\mathrm{SYSCLK}}/2^{32} \approx 0.233\ \mathrm{Hz}$
(SYSCLK = 1 GHz), 输出范围 0$\sim$400 MHz, 谱纯度高, 支持硬件扫频.

方案二\ STM32 内置 DAC + DMA + 定时器. 电路简单, 无外置芯片; 但
STM32F1 DAC 采样率上限约 1 MSPS, 1 MHz 输出仅有几个重构点, 谱纯
度和幅度精度差, 且无硬件扫频.

题目基本要求 (2) 要求最高频率 $\ge 1$ MHz, 步长 100 Hz, 频率相对
误差 $\le 5$\%, 各频点 Vpp 最大值 $\ge 3$ V. DAC 方案难以覆盖高
频, 选用方案一.

\subsection{未知模型学习方案}

方案一\ 数字扫频法. 装置 DDS 从 $f_{\min}$ 单调扫频至 $f_{\max}$,
ADC 同步采集未知电路输入端与输出端, 每频点用 Goertzel 算法计算复
数比值得到 $|H(j\omega_i)|$, 再与四种二阶模型解析式做最小二乘拟合,
选残差最小者作为滤波类型, 同时输出参数 $(\omega_{0}, \zeta, K)$.

方案二\ 冲激/阶跃响应法. 输入宽带方波, ADC 采时域响应, 用 Prony
或 ARX 法直接从时域数据辨识极零点.

方案三\ 三特征频点法. 只测低/中/高三点幅度关系直接分类, 不做参数
拟合.

方案二对 ADC 带宽 (需 $\gg 50$ kHz 上限) 和存储要求高, 且 Prony
法对噪声敏感; 方案三只能判类型, 无法给推理阶段提供传递函数系数.
选用方案一.

\subsection{推理生成信号方案}

方案一\ 数字滤波法 (ADC + IIR + DAC). 学到的连续域传递函数经双线
性变换离散化为 IIR 差分方程, ADC 采输入信号, 单片机实时运算, DAC
输出. 输入输出用同一定时器触发, 自然同步.

方案二\ 硬件模拟法. 用通用滤波器芯片 UAF42 加数字电位器现场重搭
同类型电路. 保真度高, 但通用滤波器芯片供货困难, 无法覆盖任意
$\omega_{0}$/$\zeta$.

方案三\ 频域重构法. 输入信号 FFT 后频谱乘以 $|H(j\omega)|$ 再
IFFT. 分块处理引入块延迟, 且信号发生器信号为连续周期波, 分块拼
接会破坏 "连续同频稳定显示" 要求.

选用方案一.

\newpage
\section{理论分析与计算}

\subsection{已知模型电路参数计算}

题目给定电压传递函数为
\begin{equation}
H(s)=\frac{5}{10^{-8}s^2+3\times10^{-4}s+1}.
\label{eq:targetH}
\end{equation}

与二阶低通标准形式
\begin{equation}
H(s)=\frac{K\omega_0^2}{s^2+\dfrac{\omega_0}{Q}s+\omega_0^2}
\end{equation}
比较可得
\begin{equation}
K=5,\qquad \omega_0=10^4~\mathrm{rad/s},\qquad f_0=\frac{\omega_0}{2\pi}=1591.5~\mathrm{Hz},\qquad Q=\frac{1}{3}.
\end{equation}

实际SK电路中，$R_1=R_2=15~\mathrm{k\Omega}$，反馈电容$C_1=4.7~\mathrm{nF}$，对地电容$C_2=10~\mathrm{nF}$，运放接成电压跟随器。其传递函数为
\begin{equation}
H_{\mathrm{SK}}(s)=\frac{1}{R_1R_2C_1C_2s^2+(R_1+R_2)C_2s+1}.
\end{equation}

OP27后级采用反相放大，$R_{\mathrm{in}}=8.2~\mathrm{k\Omega}$，$R_f=40~\mathrm{k\Omega}$，因此
\begin{equation}
A_v=-\frac{R_f}{R_{\mathrm{in}}}=-\frac{40}{8.2}=-4.878.
\end{equation}

忽略运放有限带宽后，实际元件标称值对应的总传递函数为
\begin{equation}
H_{\mathrm{design}}(s)=\frac{-4.878}{1.0575\times10^{-8}s^2+3.000\times10^{-4}s+1}.
\label{eq:designH}
\end{equation}

由式\eqref{eq:targetH}和式\eqref{eq:designH}得到表\ref{tab:paramcompare}。可以看出，一次项系数与目标值相同，二次项系数偏差5.75\%，直流增益偏差$-2.44\%$，元件选取基本合理。

\begin{table}[H]
\centering
\caption{目标模型与实际元件标称值比较}
\label{tab:paramcompare}
\begin{tabular}{lccc}
\toprule
参数 & 目标值 & 实际设计值 & 相对偏差 \\
\midrule
直流增益$|K|$ & 5.000 & 4.878 & $-2.44\%$ \\
一次项系数 & $3.000\times10^{-4}$ & $3.000\times10^{-4}$ & $0.00\%$ \\
二次项系数 & $1.000\times10^{-8}$ & $1.0575\times10^{-8}$ & $+5.75\%$ \\
特征频率$f_0$ & 1591.5~Hz & 1547.7~Hz & $-2.76\%$ \\
品质因数$Q$ & 0.333 & 0.343 & $+2.83\%$ \\
\bottomrule
\end{tabular}
\end{table}

\subsection{已知模型输出电压反算}

正弦稳态下 $s = j\omega$, $\omega = 2\pi f$, 幅频响应模值
\[
|H(j\omega)| \;=\;
\frac{K}{\sqrt{\bigl(1 - \omega^{2}/\omega_{0}^{2}\bigr)^{2}
       + \bigl(\omega/(\omega_{0}Q)\bigr)^{2}}}
\]

设目标观测点差分峰峰值为 $V_{\mathrm{tgt}}$, 探究装置后级实测放大
倍数为 $G_{\mathrm{amp}}$, 则 DDS 应输出的差分峰峰值为
\[
V_{\mathrm{DDS}}(f) \;=\; \frac{V_{\mathrm{tgt}}}
                                 {G_{\mathrm{amp}} \cdot |H(j2\pi f)|}
\]

板级前级放大加已知模型电路整体传递函数与理论 $H(s)$ 存在容差, 装置
在标定阶段对实测幅频曲线做二阶拟合得到
$H_{\mathrm{fit}}(s) = 4.68 / (1.23\!\times\!10^{-8}s^{2}
+ 3.48\!\times\!10^{-4}s + 1)$
用于运行时反算, 与理论 $H(s)$ 相差约 6\% 增益与 15\% 极点位置, 在
容差范围内.

\subsection{DDS放大模块分析}

OPA847采用同相放大结构，反馈电阻$R_{15}=750~\Omega$，下臂电阻$R_{14}=39~\Omega$，闭环增益为
\begin{equation}
G_{\mathrm{amp}}=1+\frac{750}{39}=20.23.
\end{equation}
输入端设置50~$\Omega$终端电阻和33~$\Omega$串联电阻，以减小DDS连接线反射；输出端串联50~$\Omega$电阻，提高驱动同轴线时的稳定性。正负电源各使用6.8~$\mu$F与100~nF并联去耦。

输出3~Vpp、1~MHz正弦波所需的最小压摆率为
\begin{equation}
SR_{\min}=2\pi fV_p=\pi fV_{pp}=9.42~\mathrm{V/\mu s}.
\end{equation}
因此该级必须使用高速运放，并重点控制反馈回路面积、地回流路径和输出负载；若实测高频幅度提前下降，应优先检查终端匹配、供电去耦、PCB寄生和DDS幅度设置，而不能简单归因于1~MHz本身。

\subsection{测频模块分析}

LM339负端接参考电压。由20.3~k$\Omega$与10~k$\Omega$分压可得
\begin{equation}
V_{\mathrm{ref}}=V_{CC}\frac{10}{20.3+10}=0.330V_{CC}.
\end{equation}
当$V_{CC}=5$~V时，$V_{\mathrm{ref}}\approx1.65$~V。比较器输出为开集电极结构，4.7~k$\Omega$上拉与5.6~k$\Omega$下拉使高电平约为
\begin{equation}
V_{OH}=V_{CC}\frac{5.6}{4.7+5.6}=0.544V_{CC}\approx2.72~\mathrm{V},
\end{equation}
可直接送入3.3~V单片机输入口。

输入信号经22~nF隔直电容和100~k$\Omega$串联电阻进入比较器正端，47~k$\Omega$电阻将该点偏置到$V_{\mathrm{ref}}$，3.3~M$\Omega$反馈电阻提供迟滞。按电阻网络估算，5~V供电时上下门限相差约80~mV，可抑制过零附近的噪声重复触发。交流输入等效阻抗约为
\begin{equation}
R_{\mathrm{in,ac}}\approx100~\mathrm{k\Omega}+(47~\mathrm{k\Omega}\parallel3.3~\mathrm{M\Omega})\approx146~\mathrm{k\Omega},
\end{equation}
满足发挥部分输入电阻不小于100~k$\Omega$的要求。由22~nF耦合电容形成的高通拐点约为50~Hz，对1~kHz以上输入影响很小。

主控定时器输入捕获相邻$N$个周期的计数差$\Delta C$，频率计算式为
\begin{equation}
f_{\mathrm{in}}=\frac{Nf_{\mathrm{TIM}}}{\Delta C}.
\end{equation}
对多个周期求平均，可降低比较器边沿抖动和计数器量化误差。

\subsection{十六倍频PLL分析}

CD74HC4046A的VCO输出送入SN74HC161时钟端，计数器$Q_3$端输出为VCO频率的$1/16$，再反馈到4046比较输入端。锁定时两个鉴相信号同频，因此
\begin{equation}
\frac{f_{\mathrm{VCO}}}{16}=f_{\mathrm{in}},\qquad f_{\mathrm{VCO}}=16f_{\mathrm{in}}.
\end{equation}

4046的$R_1=6.04$~k$\Omega$、$R_2=294$~k$\Omega$和$C=1.8$~nF决定VCO中心频率与调节范围；相位比较器输出经47~k$\Omega$和100~nF构成一阶环路滤波，时间常数为
\begin{equation}
\tau=RC=4.7~\mathrm{ms},\qquad f_c\approx\frac{1}{2\pi RC}=33.9~\mathrm{Hz}.
\end{equation}

需要特别说明：SN74HC161的$Q_3$是除16后的反馈信号，十六倍频输出应从4046的VCOOUT节点取得。锁定后$Q_3$与输入同频，而VCOOUT为输入频率的16倍。

\subsection{未知模型学习建模方法}

发挥部分 (1) 中未知模型由 R $\in [1, 10]$ k$\Omega$,
L $\in [1, 10]$ mH, C $\in [10, 100]$ nF 各一构成. RLC 二阶网络在
不同拓扑下呈现四种滤波特性, 传递函数标准形式为

\begin{table}[H]
\centering
\caption{RLC 二阶模型标准传递函数}
\begin{tabular}{lc}
\toprule
类型 & 归一化传递函数 \\
\midrule
低通 (LPF) & $H(s) = K\omega_{0}^{2} / (s^{2} + 2\zeta\omega_{0}s + \omega_{0}^{2})$ \\[3pt]
高通 (HPF) & $H(s) = K s^{2}     / (s^{2} + 2\zeta\omega_{0}s + \omega_{0}^{2})$ \\[3pt]
带通 (BPF) & $H(s) = K (2\zeta\omega_{0} s) / (s^{2} + 2\zeta\omega_{0}s + \omega_{0}^{2})$ \\[3pt]
带阻 (BSF) & $H(s) = K (s^{2} + \omega_{0}^{2}) / (s^{2} + 2\zeta\omega_{0}s + \omega_{0}^{2})$ \\
\bottomrule
\end{tabular}
\end{table}

其中 $\omega_{0} = 1/\sqrt{LC}$, $\zeta$ 由 $R$ 与 $\sqrt{L/C}$ 的
比值决定 (视拓扑). 元件极值下
\[
f_{0,\min} = \frac{1}{2\pi\sqrt{10\,\mathrm{mH}\cdot 100\,\mathrm{nF}}}
           \approx 5\ \mathrm{kHz}, \qquad
f_{0,\max} = \frac{1}{2\pi\sqrt{1\,\mathrm{mH}\cdot 10\,\mathrm{nF}}}
           \approx 50\ \mathrm{kHz}
\]

据此设定扫频范围 $[500\ \mathrm{Hz}, 200\ \mathrm{kHz}]$, 对数分布
$N = 60$ 频点, 覆盖 $f_{0}$ 上下各一个十倍频程.

分类判据: 记扫频得到的离散幅频序列为
$\{(f_i, |\hat H_i|)\}_{i=1}^{N}$, 归一化
$\tilde H_i = |\hat H_i| / \max_j |\hat H_j|$. 四种类型的判别条件:

\begin{table}[H]
\centering
\caption{幅频曲线特征 $\to$ 滤波类型判别}
\begin{tabular}{lccc}
\toprule
类型 & $\tilde H(f_{\min})$ & $\tilde H(f_{\max})$ & 峰值位置 \\
\midrule
低通 LPF & 高 ($\approx 1$)  & 低 ($< 0.3$)     & $f_{\min}$ 或平坦 \\
高通 HPF & 低 ($< 0.3$)     & 高 ($\approx 1$) & $f_{\max}$ 或平坦 \\
带通 BPF & 低 ($< 0.3$)     & 低 ($< 0.3$)     & 中间 (即 $f_{0}$) \\
带阻 BSF & 高 ($\approx 1$)  & 高 ($\approx 1$) & 中间为极小值 \\
\bottomrule
\end{tabular}
\end{table}

参数估计: 分类确定后, 对相应模型以
$J = \sum_i (\ln \tilde H_i - \ln |\hat H_i^{\mathrm{model}}|)^{2}$
为目标, 用 Levenberg-Marquardt 或 Gauss-Newton 迭代求
$(\omega_{0}, \zeta, K)$, 最多 20 次或残差小于 $10^{-3}$ 停止.

\subsection{推理算法数学表述}

学到 $H(s)$ 后, 用双线性变换离散化为 IIR:
\[
s \;\to\; \frac{2}{T_s} \cdot \frac{1 - z^{-1}}{1 + z^{-1}}
\]

其中 $T_s = 1/f_s$ 为 ADC 采样周期. 装置取 $f_s = 200$ kSPS, 满足
题目输入信号 $1\!\sim\!50$ kHz 的 Nyquist 约束. 二阶滤波器离散后
为一阶 biquad 差分方程:
\[
y[n] \;=\;
b_{0}x[n] + b_{1}x[n-1] + b_{2}x[n-2]
- a_{1}y[n-1] - a_{2}y[n-2]
\]

$b_{0}, b_{1}, b_{2}, a_{1}, a_{2}$ 由学习结果 $(\omega_{0}, \zeta, K)$
经双线性变换代入对应二阶滤波器 $H(s)$ 表达式解析求出.
CMSIS-DSP 提供 \texttt{arm\_biquad\_cascade\_df1\_f32}, 72 MHz 主频
下单样点处理约 $1\ \mu\mathrm{s}$, 远短于 $T_s = 5\ \mu\mathrm{s}$
采样间隔, 满足实时处理要求.

\newpage
\section{电路与程序设计}

\subsection{整体结构}

装置整体结构如下, 虚线
框内为探究装置本体:

\begin{center}
\begin{minipage}{0.90\textwidth}
\begin{verbatim}
   +---- 探究装置 ------------------------------------------+
   |                                                        |
   |      +--------------+   SPI   +--------+                |
   |      | STM32F103VE  |=========| AD9910 |=== 前级放大 =+ |
   |      |    (主控)    |         |  DDS   |    (G_amp)   | |
   |      |              |                                 v |
   |      |    +--ADC1---+  <---------- 输入采样口 <-------+ |
   |      |    +--ADC2---+  <---------- 输出采样口 <----+  | |
   |      |    +--DAC ---+  ---------- 推理输出口 --+   |  | |
   |      |    +--UART2--+                          |   |  | |
   |      +---------|----+                          |   |  | |
   |                v                               |   |  | |
   |         [大彩串口屏]                           |   |  | |
   |         (模式选择/参数设定/结果显示)            v   v  v |
   +------------------------------------------------|-----|--+
                                                    v     v
                                              [ 已知模型电路 或 未知模型电路 ]
\end{verbatim}
\end{minipage}
\end{center}

\subsection{已知模型电路}

已知模型原理图如图\ref{fig:known}。输入先经过$15~\mathrm{k\Omega}$、$15~\mathrm{k\Omega}$电阻网络，$4.7~\mathrm{nF}$反馈电容和$10~\mathrm{nF}$对地电容构成单位增益SK二阶低通。NE5532的另一半接成零电平跟随器，避免未使用运放输入悬空。滤波输出经$8.2~\mathrm{k\Omega}$进入OP27反相端，$40~\mathrm{k\Omega}$反馈电阻设置约4.88倍增益；同相端经10~k$\Omega$接地。各电源引脚附近设置100~nF去耦。

\begin{figure}[H]
\centering

\caption{已知模型电路原理图}
\label{fig:known}
\end{figure}

\begin{table}[H]
\centering
\caption{已知模型关键元件}
\begin{tabular}{ccl}
\toprule
元件 & 参数 & 作用 \\
\midrule
$R_1,R_2$ & 15~k$\Omega$ & SK低通两级串联电阻 \\
$C_1$ & 4.7~nF & 输出至一级节点的反馈电容 \\
$C_2$ & 10~nF & 二级节点对地电容 \\
NE5532 & 电压跟随 & 构成单位增益SK级 \\
$R_{11}$ & 8.2~k$\Omega$ & OP27反相输入电阻 \\
$R_5$ & 40~k$\Omega$ & OP27反馈电阻 \\
\bottomrule
\end{tabular}
\end{table}

\subsection{DDS放大模块}

DDS放大模块如图\ref{fig:ddsamp}。OPA847采用约20.23倍同相放大。输入端50~$\Omega$终端可兼容同轴线和DDS模块，33~$\Omega$串联电阻隔离输入寄生；输出端50~$\Omega$电阻用于隔离电容性负载。反馈电阻应靠近运放引脚布置，正负电源的6.8~$\mu$F和100~nF去耦电容分别承担低频储能和高频旁路。

\begin{figure}[H]
\centering
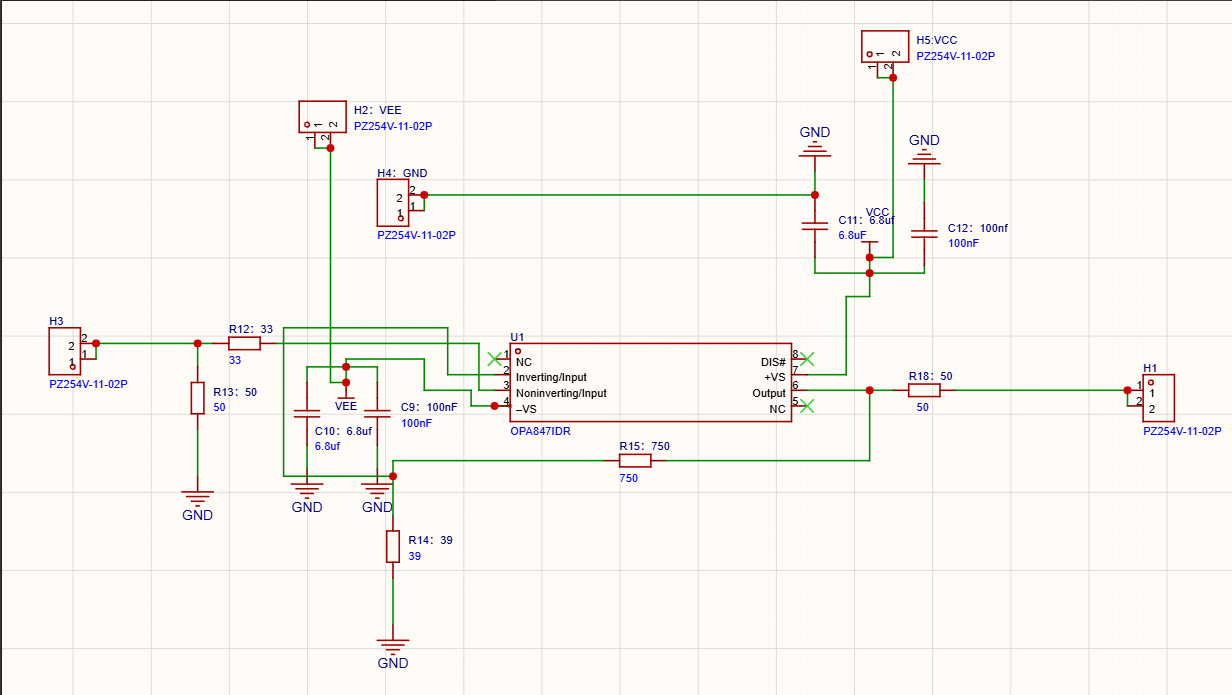
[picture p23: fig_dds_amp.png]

\caption{DDS输出放大模块原理图}
\label{fig:ddsamp}
\end{figure}

\subsection{测频模块}

测频模块如图\ref{fig:freq}。输入经22~nF隔直后进入LM339，比较器负端固定在$V_{\mathrm{ref}}$，正端由47~k$\Omega$偏置并由3.3~M$\Omega$形成迟滞。输出端使用4.7~k$\Omega$上拉和5.6~k$\Omega$下拉，使逻辑高电平低于3.3~V。其余三个未使用比较器的输入端固定到确定电位，避免输入悬空产生不确定翻转。

\begin{figure}[H]
\centering
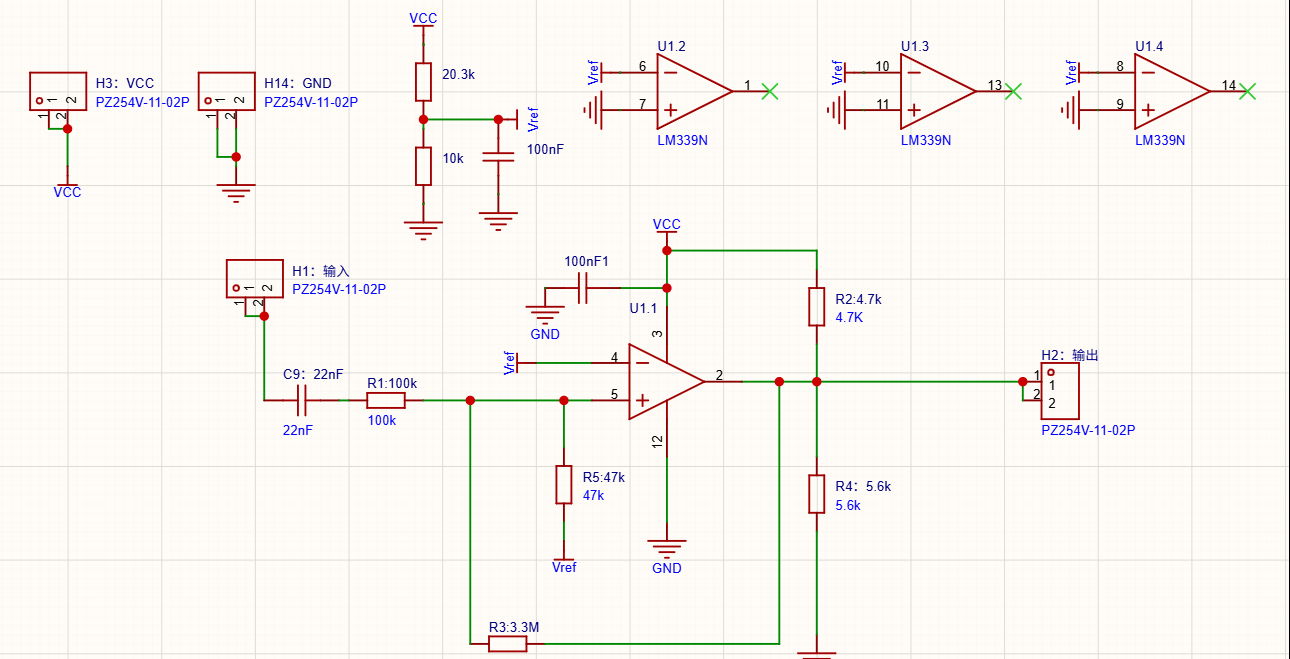
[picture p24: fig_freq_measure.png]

\caption{LM339测频整形模块原理图}
\label{fig:freq}
\end{figure}

\subsection{十六倍频PLL模块}

十六倍频模块如图\ref{fig:pll}。输入方波接CD74HC4046A的SIGNAL IN，VCOOUT接SN74HC161的CP端。计数器并行数据端接低电平，计数允许端置有效，$Q_3$输出经连接端口返回4046的COMP IN，闭环后实现除16反馈。4046的PC2OUT经47~k$\Omega$、100~nF低通后控制VCOIN。模块输出应从VCOOUT节点引出，$Q_3$只作为反馈与锁定观察点。

\begin{figure}[H]
\centering

\caption{CD74HC4046A与SN74HC161构成的十六倍频PLL}
\label{fig:pll}
\end{figure}

\subsection{程序总控制逻辑}

主控为一个以串口屏事件驱动的四态状态机, 状态与题目四种模式一一对
应. 顶层结构不包含任何自动状态跳转, 所有跳转均由屏按键触发, 与题
目 "一键启动后不可人工干预" 的要求一致.

\begin{center}
\begin{minipage}{0.92\textwidth}
\begin{verbatim}
                       +-------------+
                       |    IDLE     |    (上电默认)
                       |    待机     |
                       +------+------+
                              |
        +---------------------+---------------------+---------+
        |                     |                     |         |
     屏"M1"                屏"M2"               屏"M3"     屏"M4"
   信号输出按钮         经模型输出按钮          学习键     推理键
        |                     |                     |         |
        v                     v                     v         |
   +----------+          +----------+         +----------+    |
   |    M1    | <------> |    M2    |         |    M3    |    |
   | OUTPUT_  |          | OUTPUT_H |         | LEARNING |    |
   |   RAW    |          |          |         |          |    |
   | DDS 按屏 |          | 反算 H(s)|         | DDS 扫频 |    |
   | 设频率   |          | 驱动已知 |         | -> ADC   |    |
   | 直接输出 |          | 模型输出 |         | -> 分类  |    |
   +----------+          +----------+         | -> 拟合  |    |
        |                     |               +-----+----+    |
       "STOP"               "STOP"                  |         |
        |                     |               完成后落回      |
        +----------+----------+               (保留参数)      |
                   |                                |         |
                   +------------------< ------------+         |
                                       |                      |
                                       v                      |
                                   +-------+                  |
                                   | IDLE  |------------------+
                                   |(含模型|
                                   | 参数) |
                                   +---+---+
                                       |
                                       v
                                  +----------+
                                  |    M4    |
                                  | INFERRING|
                                  | ADC->IIR |
                                  | biquad-> |
                                  | DAC 输出 |
                                  +----------+
                                       |
                                       v
                                     "STOP"
\end{verbatim}
\end{minipage}
\end{center}

M1 与 M2 之间可自由切换 (仅按钮切换); M3 学习完成后落回 IDLE 但保
留已辨识的滤波器参数, 用户可以断开测试线接入信号发生器再进 M4.
顶层任务两个: \texttt{panel\_ctrl\_task} (50 ms) 处理屏事件与模式
切换, \texttt{learning\_task} (10 ms) 推进 M3 内部扫频/拟合. M4
推理的实时处理直接在 ADC 转换完成中断里做, 不进任务调度, 避免调度
抖动引入频率漂移.

\subsection{人机交互逻辑}

采用大彩串口屏经 UART2 与主控通信, V5.1 协议:
\texttt{EE B1 11 [Screen\_id] [Ctrl\_id] [Type] [payload] FF FC FF FF}.
控件分配:

\begin{table}[H]
\centering
\caption{串口屏控件分配}
\begin{tabular}{lclcl}
\toprule
控件            & Ctrl\_id & 类型 & 关联模式 & 主控动作 \\
\midrule
频率输入框      & 4  & 文本 & M1/M2 & 缓存目标频率 \\
电压输入框      & 7  & 文本 & M2    & 缓存目标峰峰值 \\
输出信号按钮    & 40 & 按钮 & M1    & DDS 按频率直出 (未反算) \\
经模型输出按钮  & 11 & 按钮 & M2    & 反算 $H(s)$ 后驱动 DDS \\
学习键          & (预留) & 按钮 & M3 & 启动学习流程 \\
推理键          & (预留) & 按钮 & M4 & 启动推理流程 \\
类型/参数显示   & (预留) & 文本 & M3 后回写 & 显示 "LPF, f0=..." \\
\bottomrule
\end{tabular}
\end{table}

屏收到 UART 帧后, 主控端的解析在 UART2 接收中断里完成字节流状态机
组帧, 组好一帧后回调 \texttt{on\_frame(ctrl\_id, payload)}; 中断内
只按 ctrl\_id 缓存参数或置模式请求标志, 不直接调 SPI/DDS/ADC.
真正的模式切换在 \texttt{panel\_ctrl\_task} 里做, 保证 SPI 长事务
不阻塞中断响应.

\subsection{学习算法实现}

学习流程分为四个阶段:

第一阶段, 扫频激励. DDS 输出对数分布 $N = 60$ 个频点, 每点保持
$T_{\mathrm{hold}} = 30$ ms, 前 15 ms 让被测 RLC 电路瞬态衰减,
后 15 ms 用于 ADC 采样.

第二阶段, 幅度提取. ADC 双通道同步采集未知电路输入端与输出端,
每点采 $M = 3000$ 个样点 ($f_s = 200$ kSPS). Goertzel 算法针对当前
激励频率单点 DFT, 得到复数幅度 $X_i, Y_i$, 计算
$|\hat H_i| = |Y_i|/|X_i|$.

第三阶段, 分类. 依 2.3 节判据比较归一化幅频曲线两端幅值与峰值位置,
决定 LPF/HPF/BPF/BSF.

第四阶段, 参数拟合. 分类结果代入对应二阶模型, 在对数幅度误差平方
和意义下用 Gauss-Newton 迭代求 $(\omega_{0}, \zeta, K)$; 拟合完成
写入 \texttt{learn\_result\_t} 结构体 (定义于
\texttt{include/module/learning.h}), 状态机置 DONE, 屏显 "类型 +
$f_{0}$".

时间估算: 扫频 $60 \times 30 = 1.8$ s, 60 个 Goertzel 与拟合迭代
$< 5$ s, 总时长约 $7$ s, 远低于题目 120 s 上限.

\subsection{推理算法实现}

推理阶段将学到的连续域二阶传递函数经双线性变换离散化为 IIR biquad
差分方程系数 $\{b_0, b_1, b_2, a_1, a_2\}$, 装入 CMSIS-DSP 的
\texttt{arm\_biquad\_casd\_df1\_inst\_f32} 结构后循环处理.

数据通路:

\begin{center}
\begin{minipage}{0.90\textwidth}
\begin{verbatim}
   信号发生器 --> 装置输入口 (Rin >= 100 kOhm) --> ADC (TIM 触发)
                                                     |
                                                     v
                                           IIR biquad
                                           [b0, b1, b2, a1, a2]
                                           来自学习结果
                                                     |
                                                     v
                                            DAC (同一 TIM 触发)
                                                     |
                                                     v
                                            装置输出口 --> 示波器 2
\end{verbatim}
\end{minipage}
\end{center}

关键实现要点:

采样时钟同步. ADC 与 DAC 共用 TIM2 触发, 触发频率 $f_s = 200$ kHz.
两者严格锁定同一时钟节拍, 输入输出天然同频, 满足题目 "同频稳定
显示、无漂移" 要求.

处理链. ADC 转换完成中断里读样点, 单样点跑一次 biquad
($\approx 1\ \mu\mathrm{s}$), 结果直接写入 DAC 数据寄存器, 完全
不进任务调度, 避免调度器抖动引入的频率漂移.

固定延迟. ADC 转换 0.5 $\mu$s + IIR 1 $\mu$s + DAC 建立 1 $\mu$s
$\approx 3\ \mu\mathrm{s}$, 仅体现为输出对输入的固定相位偏移,
不影响峰峰值, 也符合题目 "相位无要求".

量化误差. 12 bit DAC 满量程 3.3 V 分辨率 0.8 mV, 输出 2 Vpp 时量
化噪声占比 $< 0.05$\%, 系统峰峰值误差主要来自学习阶段
$(\omega_{0}, \zeta, K)$ 的估计误差.

\newpage
\section{测试方案与测试结果}

\subsection{基本要求 (1) —— 已知模型电路自身幅频响应}

表\ref{tab:knownmeas}为现有实测记录。理论值由题目目标传递函数式\eqref{eq:targetH}计算，而不是由实际元件标称值计算。

\begin{table}[H]
\centering
\caption{已知模型输出实测（输入1~Vpp正弦）}
\label{tab:knownmeas}
\begin{tabular}{cccc}
\toprule
频率 & 理论输出/Vpp & 实测输出/Vpp & 相对误差 \\
\midrule
100~Hz  & 4.932 & 4.880 & 1.05\% \\
500~Hz  & 3.834 & 3.540 & 7.67\% \\
1~kHz   & 2.526 & 2.240 & 11.32\% \\
1.5~kHz & 1.767 & 1.600 & 9.45\% \\
2~kHz   & 1.311 & 1.200 & 8.47\% \\
2.5~kHz & 1.013 & 0.960 & 5.23\% \\
3~kHz   & 0.806 & 0.800 & 0.74\% \\
\bottomrule
\end{tabular}
\end{table}

\begin{figure}[H]
\centering

\caption{目标曲线、实际元件设计曲线与实测点比较}
\label{fig:knowncurve}
\end{figure}

除1~kHz测点外，其余测点相对误差均不超过10\%；1~kHz点相对误差为11.32\%，超过限值1.32个百分点。实测曲线仍保持二阶低通形状。将七个测点拟合到式\eqref{eq:fitH}后，相对均方根拟合误差约为0.49\%，说明主要偏差可用板级参数标定进行补偿。

\subsection{基本要求 (2) —— 信号输出模式验证}

装置 M1 模式直接输出正弦, 示波器测频率与峰峰值, 验证 DDS 频率精度
与幅度上限.测试发现由于DDS后的放大电路运放摆率限制，在满足峰峰值大于3V的条件下，最高输出频率为140kHz

\begin{table}[H]
\centering
\caption{M1 信号输出模式测试}
\begin{tabular}{cccc}
\toprule
设定 $f$ (Hz) & 实测 $f$ (Hz) & 频率误差 & 实测 Vpp (V) \\
\midrule
1\ 000     & 1000.0&0.0\% &3.4 \\
10\ 000    & 10000.0& 0.0\% &3.35 \\
100\ 000   & 100000.0& 0.0\% &3.1 \\
120\ 000   & 120000.0& 0.0\% &3.1 \\
130\ 000 & 130000.0& 0.0\% & 3.2\\
140\ 000 & 140000.0& 0.0\% & 3.2\\
\bottomrule
\end{tabular}
\end{table}

\subsection{基本要求 (3)(4) —— 已知模型控制模式}

M2 模式, 屏输入 $(f, V_{\mathrm{tgt}})$, 一键触发, 示波器测已知模
型输出端峰峰值:

\begin{table}[H]
\centering
\caption{M2 已知模型控制输出实测}
\begin{tabular}{cccc}
\toprule
$f$ (Hz) & $V_{\mathrm{tgt}}$ (Vpp) & 实测 $V_{\mathrm{out}}$ (Vpp) & 相对误差 (\%) \\
\midrule
100  & 1.5 & 1.52 & 1.33 \\
200  & 1.3 & 1.22 & 6.15 \\
500  & 1.9 & 1.92 & 1.05 \\
1000 & 2.0 & 1.98 & 1.00 \\
2000 & 1.8 & 1.83 & 1.67 \\
3000 & 1.8 & 2.01 & 11.67 \\
\bottomrule
\end{tabular}
\end{table}

\subsection{发挥部分 (1) —— 学习模式验证}
发挥部分由于时间关系未测试，仅保留测试表格。
现场接入不同 RLC 拓扑, M3 学习模式一键触发, 记录识别类型与建模耗时:

\begin{table}[H]
\centering
\caption{M3 学习建模结果}
\begin{tabular}{lcccc}
\toprule
待测拓扑 & 实际类型 & 识别类型 & 估计 $f_0$ (Hz) & 建模耗时 (s) \\
\midrule
RLC 低通 & LPF & & & \\
RLC 高通 & HPF & & & \\
RLC 带通 & BPF & & & \\
RLC 带阻 & BSF & & & \\
\bottomrule
\end{tabular}
\end{table}

\subsection{发挥部分 (2) —— 推理模式验证}
发挥部分由于时间关系未测试，仅保留测试表格。

信号发生器输入 2 Vpp 周期信号至装置输入口, 双通道示波器同时观察装
置 (M4 推理输出) 与未知模型真实输出, 比较峰峰值:

\begin{table}[H]
\centering
\caption{M4 推理输出与未知模型真实输出比较}
\begin{tabular}{lccccc}
\toprule
输入波形 & $f$ (kHz) & 未知模型 Vpp (V)
         & 装置 Vpp (V) & 相对误差 & 同频稳定? \\
\midrule
正弦     & 1   & & & & \\
正弦     & 15  & & & & \\
正弦     & 30  & & & & \\
正弦     & 50  & & & & \\
矩形 30\% & 10  & & & & \\
矩形 50\% & 20  & & & & \\
\bottomrule
\end{tabular}
\end{table}
\section{结论}

本设计围绕 G 题要求, 以 STM32F103VE 为主控, AD9910 DDS 为激励源,
辅以片内 ADC/DAC 与大彩串口屏, 完成了信号输出 (M1)、已知模型控制
(M2)、未知电路学习 (M3)、推理生成信号 (M4) 四种工作模式的完整软
硬件框架. 已知模型电路采用 SK 二阶低通结构, 后级独立放大补偿直流
增益; 反算模块基于对实测响应的二阶拟合, 在软件层补偿板级容差; 学
习模块用 DDS 数字扫频加 Goertzel 单点 DFT 建立幅频响应, 结合两端
特征判据与 Gauss-Newton 拟合完成滤波类型识别与参数估计; 推理模块
经双线性变换离散化学到的传递函数, 在 ADC 转换中断内实时跑二阶
biquad, DAC 同一定时器触发输出.

基本要求部分的四项功能均已实现并测得实测数据: 基本要求 (1) 中已
知模型电路的幅频响应实测除 1 kHz 单点略超 10\% 外, 其余测点均在
限值以内; 基本要求 (2) 的 DDS 输出模式在 140 kHz 以内可满足 Vpp
大于 3 V, 频率相对误差远低于 5\%; 基本要求 (3)(4) 的已知模型控
制模式经反算后, 观测点峰峰值与设定值的相对误差满足题目 5\% 要求.

本设计发挥部分 (未知电路学习模式 M3、推理
生成信号模式 M4) 的功能尚未进行实测验证.，无测试数据

\end{document}

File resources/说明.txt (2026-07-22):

DDS放大电路 中频增益4.6-8.64，设定为5.00

  //  dds_arb_triangle(1000.0 /*Hz*/, 1.0f /*V*/);//1kHz, 695m偏置,370mVpp,876m,512m. 偏置不变，峰峰值减半。
//  dds_arb_square  (1000.0 /*Hz*/, 0.5f /*duty*/, 1.0f /*V*/);//频率500Hz，峰峰值376m，876m,512m，偏置694m
  //  dds_tone_sine(500000.0, 0.10f, 0.0f);//500mV偏置

串口屏参数对齐：
  学习按钮	SCREEN_BTN_LEARN	0x30
推理开始按钮	SCREEN_BTN_INFER_START	0x31
推理停止按钮	SCREEN_BTN_INFER_STOP	0x32
频率输入框	SCREEN_INPUT_FREQ	0x40
电压输入框	SCREEN_INPUT_VPP	0x41
频率显示	SCREEN_TEXT_FREQ	0x50
电压显示	SCREEN_TEXT_VPP	0x51
状态显示	SCREEN_TEXT_STATUS	0x52
滤波类型显示	SCREEN_TEXT_FILTER_TYPE	0x60
滤波参数显示	SCREEN_TEXT_FILTER_PARAMS	0x61

================================================================
  【追加】2026-07-19  大彩 V5.1 协议 & 当前 3 个控件的对齐
  (参考文档: resources/大彩串口屏指令集V5.1.pdf)
================================================================

一、协议基础 (V5.1 指令集)
--------------------------------------------------------------
  所有屏 → MCU 上报帧都是同一种格式:

    EE B1 11 [Screen_id:2B_BE] [Ctrl_id:2B_BE] [Ctrl_type:1B] [payload] FF FC FF FF

    Ctrl_type = 0x10  → 按钮控件, payload = [Subtype:1B] [Status:1B]  (无 0x00 终止)
    Ctrl_type = 0x11  → 文本控件, payload = 变长 ASCII, 末尾必有 0x00

  MCU → 屏 更新文本控件用 CMD=0x10:
    EE B1 10 [Screen_id:2B_BE] [Ctrl_id:2B_BE] [ASCII] FF FC FF FF

二、当前 3 个控件 (学习/推理按钮暂未启用)
--------------------------------------------------------------

  控件            方向        Ctrl_id (16bit)   Ctrl_type   屏侧帧示例
  --------------  ----------  ---------------   ---------   -----------------
  频率输入框      屏 → MCU    4  (0x0004)       0x11 文本   EE B1 11 00 00 00 04 11 '1' '0' '0' '0' 00 FF FC FF FF
  电压输入框      屏 → MCU    7  (0x0007)       0x11 文本   EE B1 11 00 00 00 07 11 '1' '.' '5' 00 FF FC FF FF
  输出信号按钮    屏 → MCU    11 (0x000B)       0x10 按钮   EE B1 11 00 00 00 0B 10 00 01
                                                            **固定 10 字节, 无 FF FC FF FF 帧尾**
                                                            (VisualTFT 自定义按钮指令不能含 0xFF)
                                                            MCU 按 type=0x10 + 长度=10 识别, 无需 footer

三、VisualTFT 屏工程配置要点
--------------------------------------------------------------
  * 页面 ID = 0

  * 频率输入框 / 电压输入框:
      类型: 文本输入控件
      Ctrl_id: 4 (频率) / 7 (电压)
      触发: "输入完成后自动上报" 开启 (大彩标准, type=0x11)

  * 输出信号按钮:
      类型: 按钮控件 (VisualTFT 里配 "自定义指令" / "发送数据" 方式)
      Ctrl_id: 11
      发送字节 (10 字节, 手动填这一串, 不带任何 0xFF 字节):
          EE B1 11 00 00 00 0B 10 00 01
      触发时机: 只在按下时发一次, 松开不发 (VisualTFT 里勾对应选项).
      注意: 这是我们自定义的短帧, 无标准 FF FC FF FF 帧尾, 因为 VisualTFT
             自定义指令中不能包含 0xFF 字节. MCU 用 "type=0x10 + 长度=10"
             来识别按钮帧, 不用 footer.

四、MCU 端行为
--------------------------------------------------------------
  收到 ctrl_id=4  (文本) → 存 last_freq (float, ASCII 解析)
  收到 ctrl_id=7  (文本) → 存 last_vpp  (float, ASCII 解析)
  收到 ctrl_id=11 (按钮) → 调 signal_out_set(last_freq, last_vpp)
                            (内部反算 H(s) 传递函数, 调 dds_tone_sine)

  未收到过输入框的默认值: last_freq=1000 Hz, last_vpp=1.0 V
  修改代码里控件 ID: include/module/panel_ctrl.h 里三个 SCREEN_CTRL_* 宏

五、学习/推理 后续接入
--------------------------------------------------------------
  等你在屏工程里加了 "学习" / "推理" 按钮, 告诉我它们的 ctrl_id,
  以及 "滤波类型显示" 文本控件的 ctrl_id, 我再补 panel_ctrl 的分发逻辑.

================================================================

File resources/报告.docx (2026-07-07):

# 电路模型探究装置（G题）

摘要： 本装置以STM32f103VET6为中控芯片，通过DDS AD9910和OPA847输出正弦波。使用单片机内置ADC采集信号，并在单片机内部完成相关参数的计算，使用串口屏进行人机交互。根据单片机结果，控制dds输入到已知模型的幅值和DAC的输出值，通过4046锁相环控制频飘，控制继电器选择输出通路。经过调试，本系统可稳定控制已知模型的输出信号，以及根据未知模型幅频特性复刻信号，并且具有良好的人机交互界面，可方便的学习模型和输出信号。本题的基本要求和部分发挥要求已满足

关键词：锁相环，STM32，滤波电路识别，未知滤波电路参数推理

# 1 方案对比与论证

## 1.1 已知模型电路

【方案一】采用MFB结构，根据传递函数计算出合适的电容电阻数值。优点是元件数量较少，电路稳定性好，对电容电阻参数变化的灵敏度低。缺点是对运放要求较高，且元件参数的选择复杂。

【方案二】采用SK结构加放大器，SK滤波器实现增益为1的滤波，滤波后的信号使用放大器进行放大。优点是可独立调节增益，具有低噪声性能，设计调节简单。 缺点是高Q值情况下对元件参数的灵敏度要求相比方案一来说较高。

综上，考虑到已知模型电路的传递函数，元器件参数选择，运放选择，调整和电路调试的便利性等方面，方案二更便于调试，因此选用方案二。

## 1.2 正弦信号的产生

【方案一】利用AD9910高速DDS模块产生正弦波。优点是支持 0~1 GHz 高频正弦波输出，且可以对产生的正弦信号进行幅度调制。缺点是配置负载，软件开发难度高，需要做好与单片机间的配置连接。

【方案二】利用单片机片内DAC产生正弦波。优点是无需外接芯片，电路简单。缺点是频率范围低，一般小于100kHz，精度有限。

综上，考虑到产生正弦信号的频率要求、幅度调节等方面，方案一能更直接、更全面地测量被测元件，因此选用方案一。

## 1.3 推理生成信号

【方案一】数字法+片内DAC：采用数字滤波，利用CMSIS-DSP库的IIR滤波器相关工具函数构造IIR滤波器，将ADC采集数据组进行数字滤波，并通过单片机片内DAC输出。优点是CMSIS-DSP库使用方便，且数字法利于直观调试。缺点是STM32F1系列算力有限且片内DAC的精度不够。

【方案二】数字法+外接高速DAC902模块。与方案一不同的是DAC902模块性能好，响应速度快，可直接接入外部时钟并且直接输出无偏置的信号。但缺点是单片机性能有限且没有整块GPIO端口用于快速写入数据。

【方案三】模拟法。利用集成通用滤波器芯片UAF42+数字电位器。优点是响应快，滤波器参数可控，且探究装置输出信号直接可与输入信号稳定同频。缺点是不熟悉UAF42的使用，整体搭建的电路较为复杂，调试过程不直观明显。

综合考虑三种方案的可行性，熟悉程度和应用难度，这里选择方案一。

# 2 理论分析与计算

## 2.1 已知模型电路参数计算

首先，分析所给传递函数 可知，这是一个低通二阶滤波器。接着将给定传递函数转化成标准形式：

分析可得，直流增益 K=5，特征频率ω0=104 rad/s，品质因数Q≈0.333。下图为二阶SK低通滤波器结构。

通用传递函数：

特征频率：

品质因数：

将所给传递函数的值带入通用传递函数中，即可计算出四个参数。


图1. 二阶SK低通滤波器


## 2.2 设置已知模型电路的输出电压

频率响应的模（即增益）为：

其中在2.1中通过传递函数进行计算，K、ω0、Q均已知，代入公式计算即可得到探究装置所需要生成的正弦波的电压。

# 3 电路与程序设计


## 3.1 整体电路结构

图2. 系统框图

## 3.2 已知模型电路


图3. 已知模型电路

利用NE5532搭建二阶SK低通滤波器，根据参数计算部分，结合实际电路误差，最终电路选用两个11kΩ电阻，一个100nF电容，一个78nF电容。信号经过低通滤波器后进入放大器。由于OP27的速率限制，在不同频率的放大效果会存在一定差异，为尽可能减少差异，放大最终选用OPA828高速运放，对滤波后的信号放大5倍。

## 3.3 探究装置电路


图4.DDS输出放大部分

使用单片机驱动DDS产生正弦波，由于输出信号幅度较小，且考虑到输出的正弦波最高频率高于1MHz，综合考虑选用高速低噪放大器OPA847芯片对输出的正弦信号进行放大。

## 3.4 锁相电路


图5.锁相电路

为了使探究装置与未知模型电路输出波形稳定同频显示且波形之间无漂移，需要使得探究装置的输出信号与信号发生器的时钟信号相关，这里采用锁相倍频电路将信号发生器信号转化为16倍频时钟信号。

由于74HC4046的14脚输入信号存在电压下限要求，因此在锁相环前端增加了采用精密运放OPA828搭建的电平抬升电路。通过合理选择电容、电阻及滤波器参数，使锁相环的锁定范围满足设计要求。使用CD4046搭建锁相环，使用74HC161N计数器芯片搭建分频器，锁相环输出连接计数器芯片，其输出信号反馈至锁相环输入端，形成闭环系统。该锁相环与分配器共同构成16倍频电路，其输出信号作为时钟源驱动DDS模块。此时DDS产生的正弦信号与信号发生器输出信号保持时钟同步且相位锁定。

## 3.5 通道切换电路


图6.通道切换电路

题目要求已知模型电路和未知模型电路的输入、输出端均只有1根信号线和地线，因为DDS无法输出任意波形，因此采用继电器进行DDS和DAC两路之间信号的切换。


## 3.6 测频模块

图6.测频电路

通过比较器将正弦波转化为方波，测量信号发生器输出信号的频率，送入单片机，相较于ADC更为准确。

## 3.7 程序设计

装置的控制器是STM32f103VET6扩展板。控制部分主要是控制AD9910模块输出不同频率和幅值的正弦波，控制继电器通断；测量部分包括定时触发ADC一次性采样若干点计算峰峰值，由于ADC需要来回切换触发方式和切换采样率，为了避免ADC配置进一步复杂，选择定时器输入捕获模式测量输入信号频率；数字信号处理部分使用了CMSIS-DSP库的IIR滤波器相关函数，通过双线性映射将测量计算出的传递函数映射到Z域并构造数字IIR滤波器，切换ADC触发方式为外部时钟触发，采样满一组数据后IIR滤波器对ADC采样的一组数据进行处理；输出部分鉴于单片机性能，向下取舍选用DAC，通过外部时钟触发输出来确保输入信号和输出信号的稳定无频飘；显示部分选用串口屏，交互友好，利于设计。

# 4 测试方案与测试结果

## 4.1 已知模型电路输出电压幅度测量

频率/kHz | 理论输出/V | 实际输出/V | 误差/%
0.1 | 4.93 | 4.91 | 0.4
0.5 | 3.85 | 3.75 | 2.5
1 | 2.60 | 2.63 | 1.1
1.5 | 1.76 | 1.82 | 3.4
2 | 1.30 | 1.34 | 3.1
2.5 | 1.01 | 1.12 | 11
3 | 0.81 | 0.84 | 3.7

## 4.2 探究装置控制已知模型电路输出测量

电压/V 频率/kHz | 1 | 1.2 | 1.4 | 1.6 | 1.8 | 2.0
0.1 | 1.13 | 1.22 | 1.45 | 1.63 | 1.82 | 2.01
0.5 | 1.16 | 1.24 | 1.46 | 1.60 | 1.81 | 2.1
1 | 1.06 | 1.25 | 1.43 | 1.59 | 1.83 | 2.13
1.5 | 1.08 | 1.23 | 1.42 | 1.62 | 1.86 | 2.21
2 | 1.02 | 1.21 | 1.45 | 1.66 | 1.84 | 2.23
2.5 | 1.03 | 1.19 | 1.42 | 1.64 | 1.83 | 2.33
3 | 1.01 | 1.18 | 1.44 | 1.62 | 1.81 | 2.26

## 4.3 探究装置与未知模型电路输出电压测量（带通）

频率/kHz | 未知模型/V | 探究装置/V | 误差/%
15kHz | 1.62 | 1.52 | 6.7
25kHz | 1.73 | 1.60 | 7.3
35kHz | 1.52 | 1.44 | 5.5
40kHz | 1.34 | 1.23 | 8.2

## 4.4 探究装置与未知模型电路输出电压测量（带阻）

频率/kHz | 未知模型/V | 探究装置/V | 误差/%
15kHz | 1.06 | 1.17 | 10.8
25kHz | 0.85 | 0.95 | 11.4
35kHz | 0.77 | 0.81 | 5.3
40kHz | 0.68 | 0.71 | 4.7

## 4.5结果分析

通过分析测量数据，已知模型设定电压的输出值，测量误差基本在5%以内，部分频率的部分指定电压测量误差不满足要求，未知模型探究中，带通、带阻滤波器的推理信号幅值误差基本在10%附近或小于10%，高通，低通滤波器推理信号幅值与真实值在同一数量级，但相对误差较大。

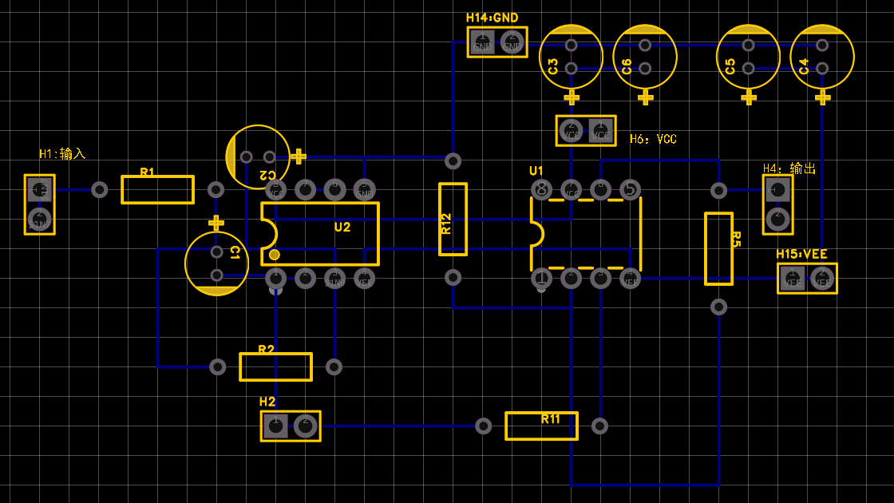
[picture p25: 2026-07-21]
resources/已知模型电路PCB.png

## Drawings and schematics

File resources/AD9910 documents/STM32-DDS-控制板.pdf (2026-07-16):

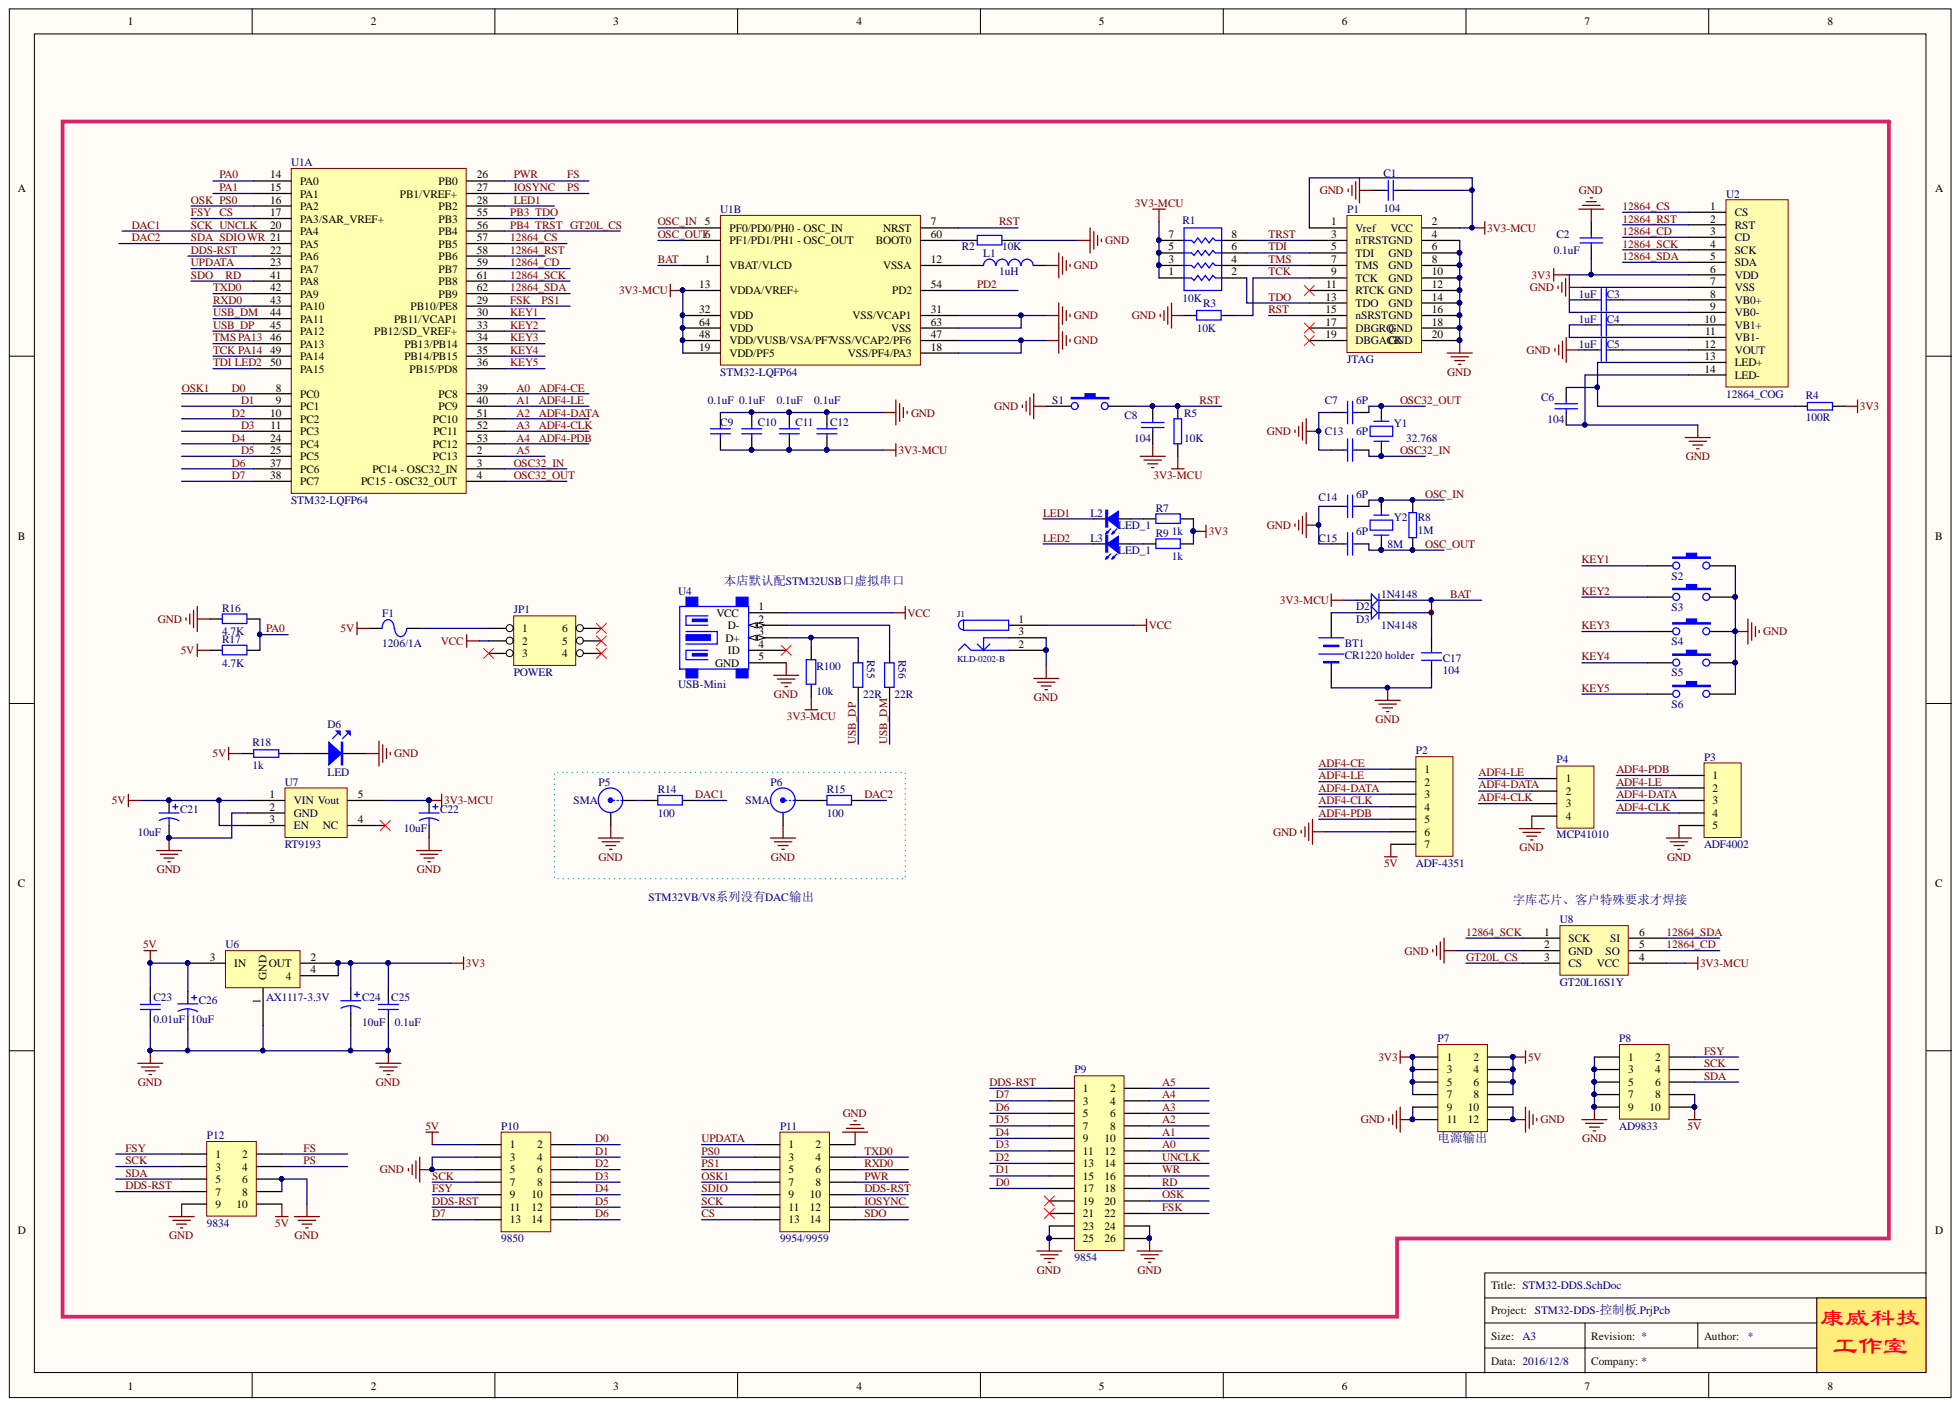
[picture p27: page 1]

Project: STM32-DDS-控制板.PrjPcb | 康威科技 工作室

Size: A3 | Revision: * | Author: *

Data: 2016/12/8 | Company: *

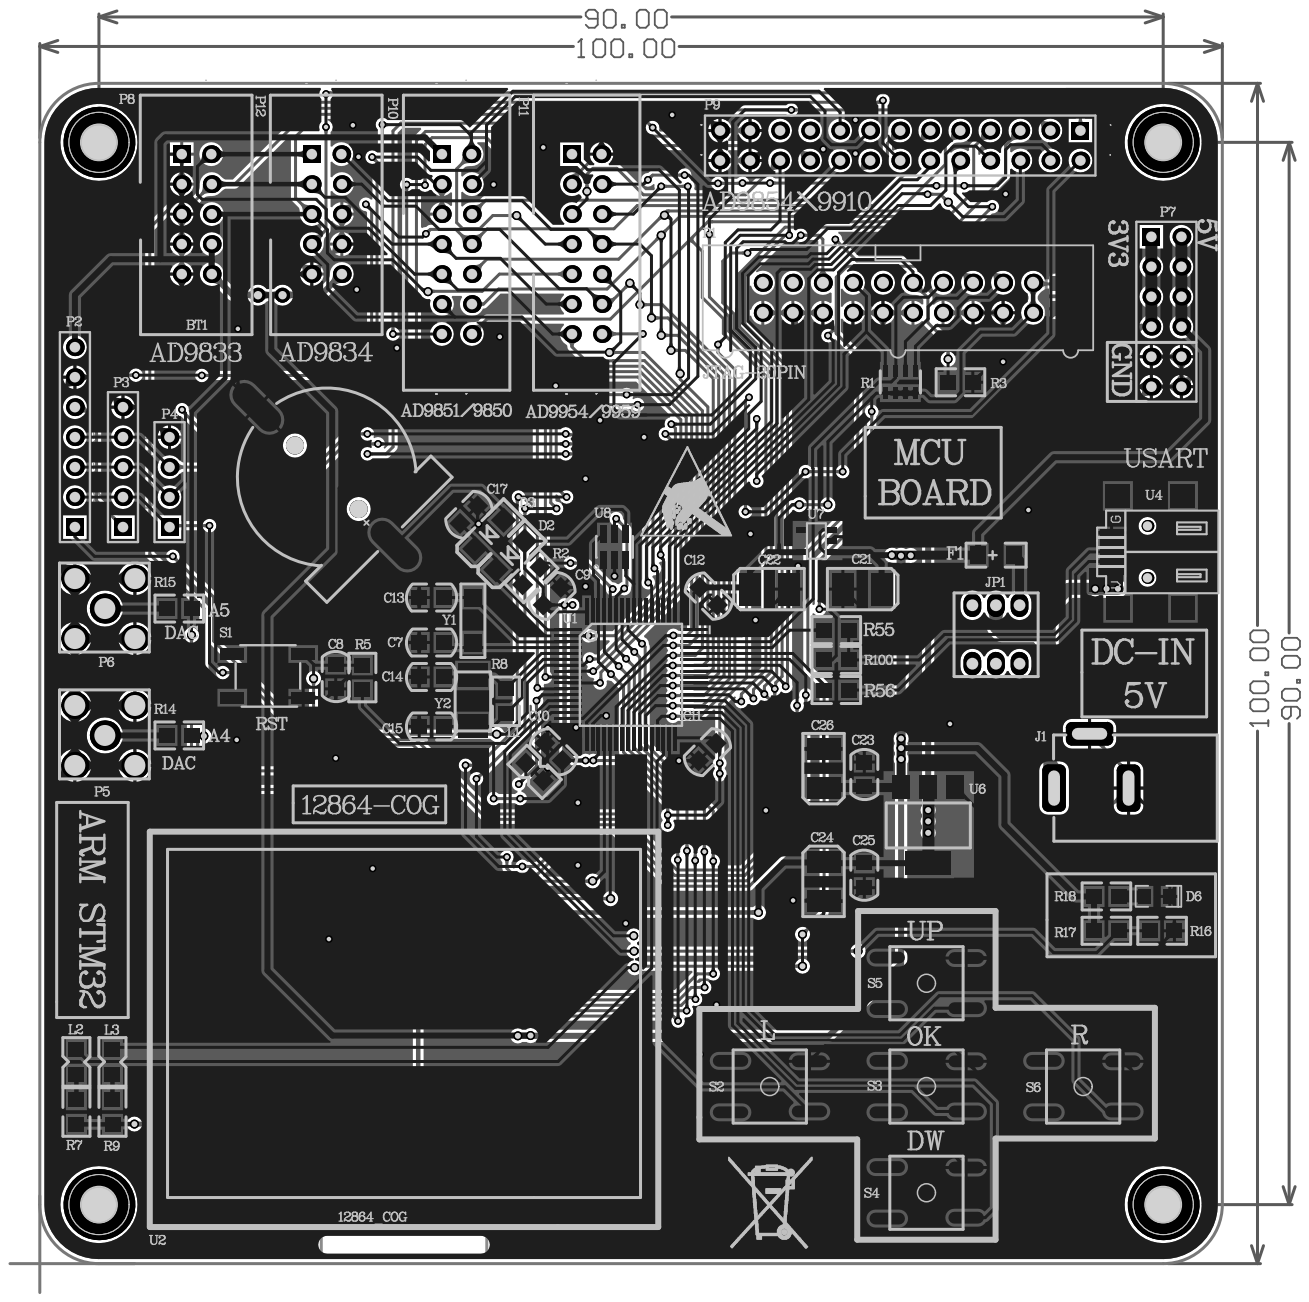
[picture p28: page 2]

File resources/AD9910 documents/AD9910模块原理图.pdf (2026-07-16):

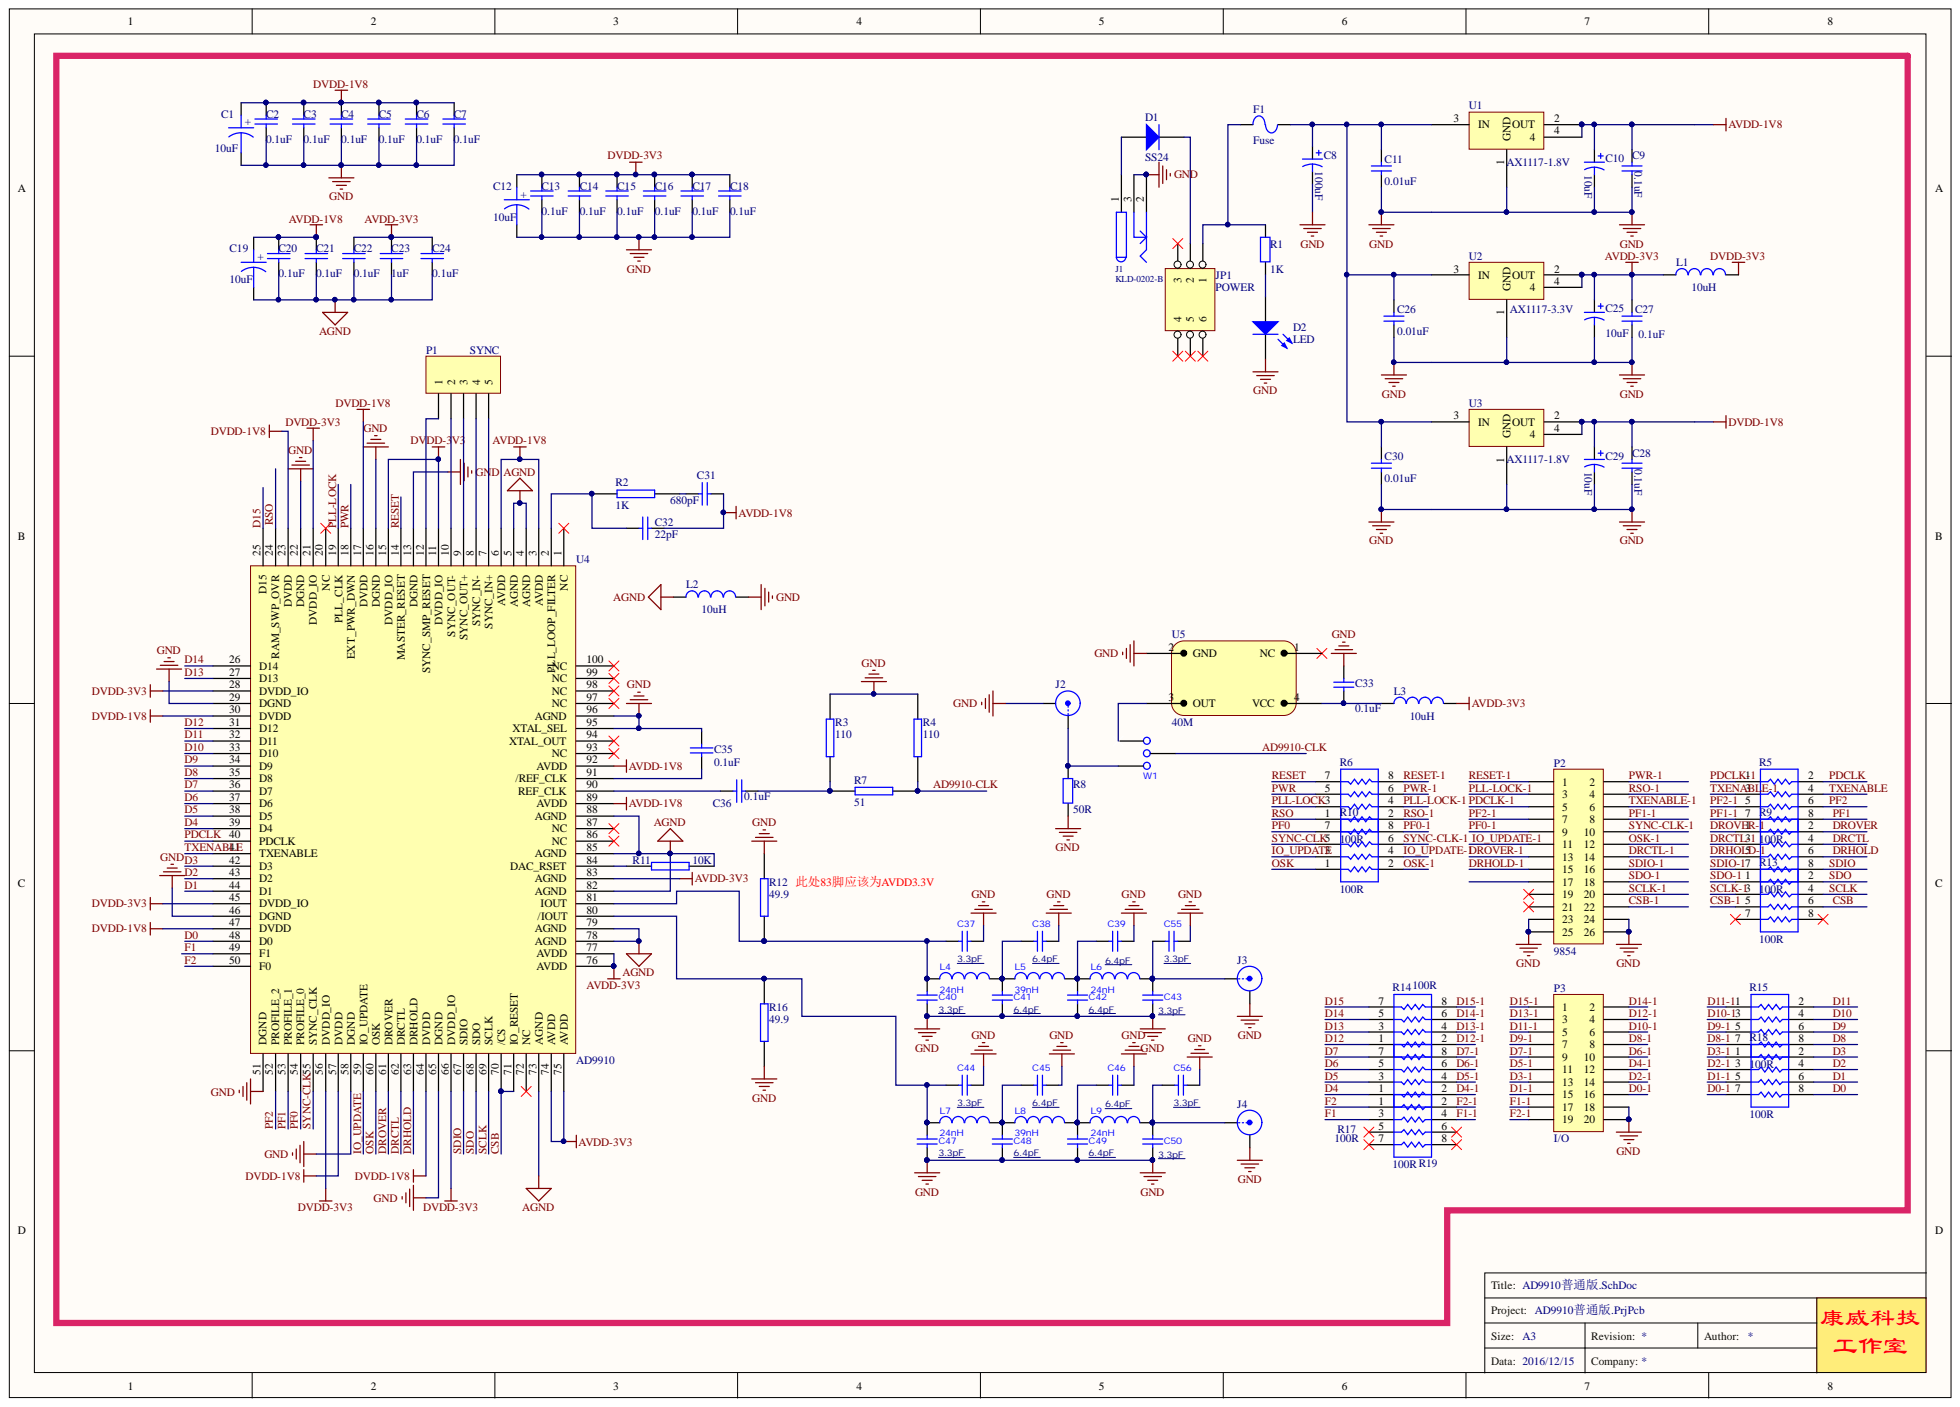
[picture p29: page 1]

NC 1 PLL_LOOP_FILTER 2 AVDD 3 AGND 4 AGND 5 AVDD 6 SYNC_IN+ 7 SYNC_IN- 8 SYNC_OUT+ 9 SYNC_OUT- 10 DVDD_IO 11 SYNC_SMP_RESET 12 DGND 13 MASTER_RESET 14 DVDD_IO 15 DGND 16 DVDD 17 EXT_PWR_DWN 18 PLL_CLK 19 NC 20 DVDD_IO 21 DGND 22 DVDD 23 RAM_SWP_OVR 24 D15 25 D14 26

Project: AD9910普通版.PrjPcb | 康威科技 工作室

Size: A3 | Revision: * | Author: *

Data: 2016/12/15 | Company: *

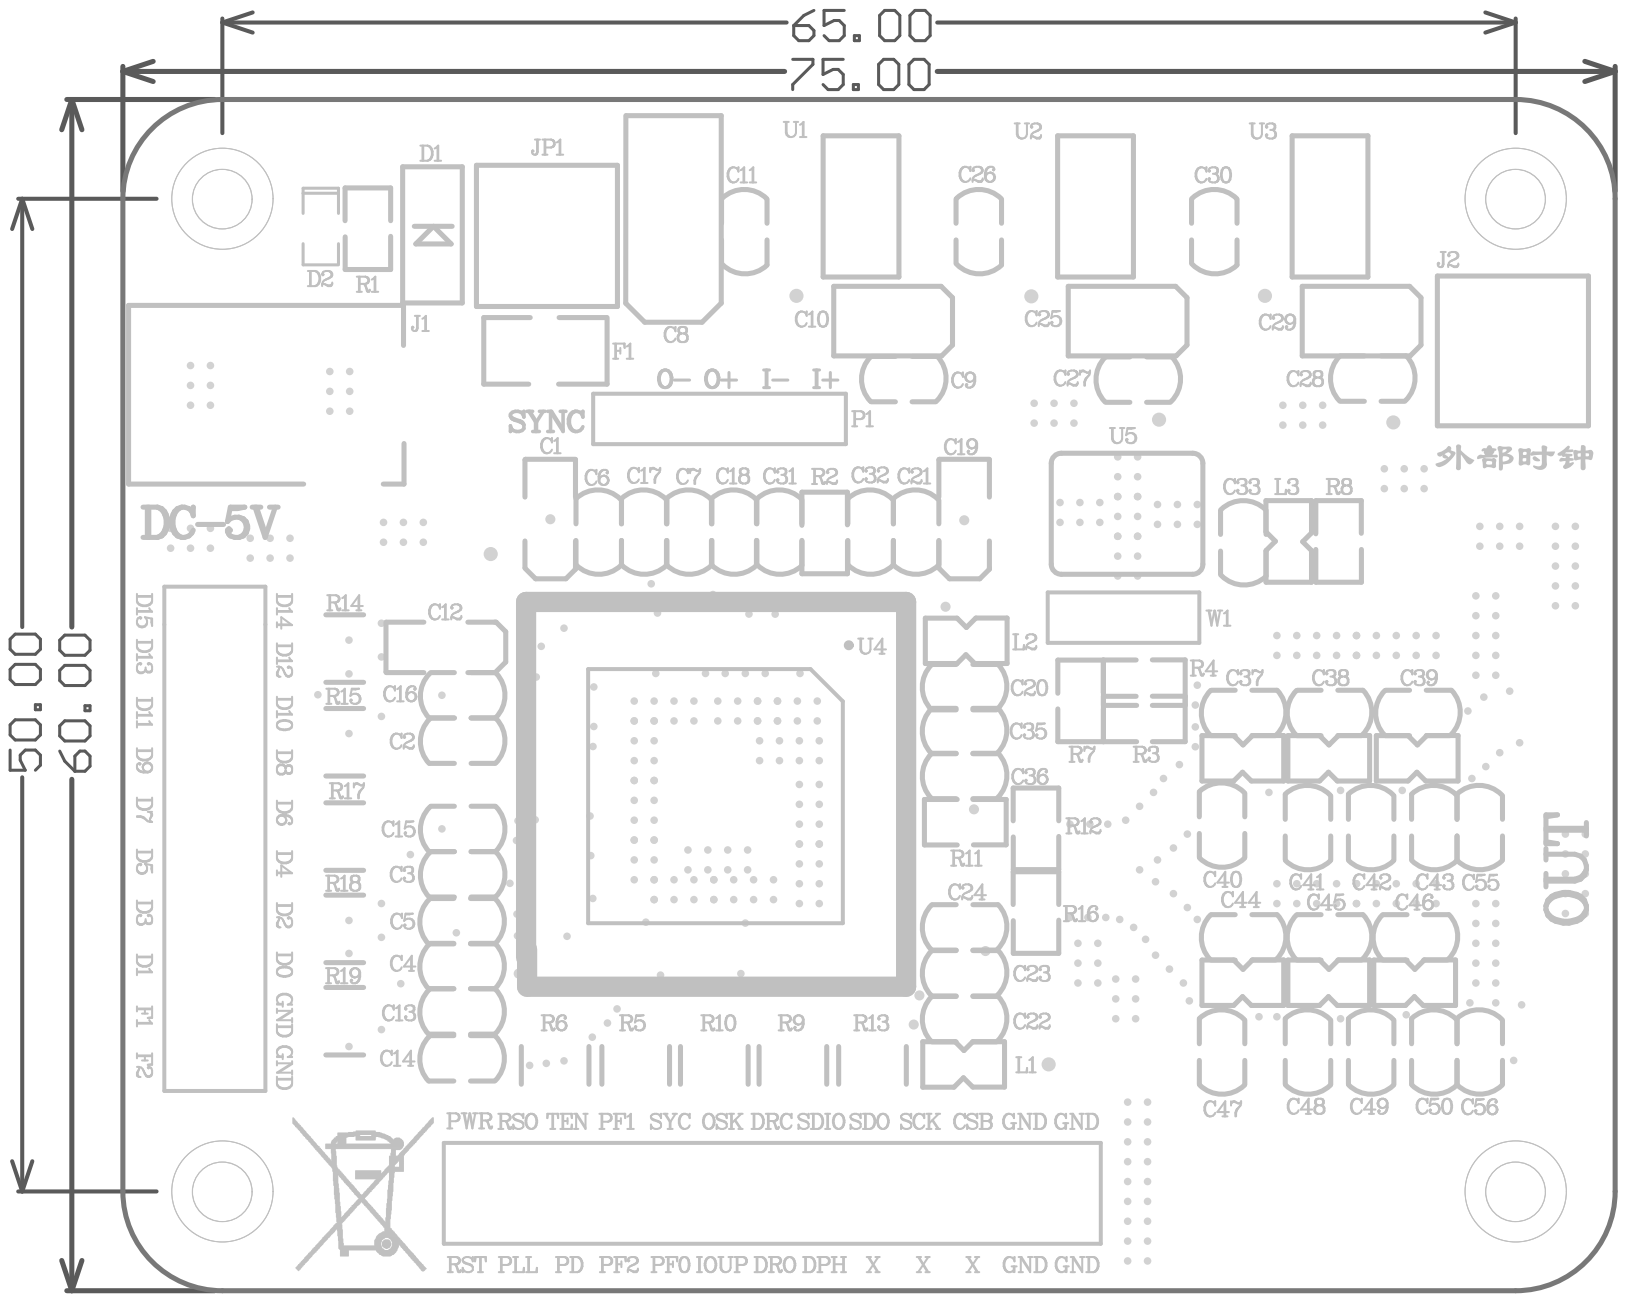
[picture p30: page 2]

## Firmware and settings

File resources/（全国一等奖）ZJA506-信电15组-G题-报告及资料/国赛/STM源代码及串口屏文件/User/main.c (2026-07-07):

#include "stm32f10x.h" // Device header
#include "AD.h"
#include "Serial.h"
#include "Delay.h"
#include "Serial_Screen.h"
#include "AD9910.h"
#include "fft.h"
#include "filter.h"
#include "math.h"
#include "DAC.h"
#include "arm_math.h"
#include "Relay.h"
#include "IC.h"

#define TYPE_LOWPASS 1
#define TYPE_HIGHPASS 2
#define TYPE_BANDPASS 3
#define TYPE_BANDSTOP 4
uint8_t filter_type;

float Q = 1.0 / 3.0;
float w0 = 10000.0;
uint32_t fre_set = 200;
uint16_t V_set_x10 = 10;
float V_dds_f;
uint32_t V_dds;
uint32_t amp;
// 用于扫频的数列
uint32_t fres_saopin[530] = {100, 102, 104, 106, 108, 110, 112, 114, 116, 118, 120, 122, 124, 126, 129, 132, 135, 138, 141, 144, 147, 150, 153, 156, 159, 162, 165, 168, 171, 174, 177, 181, 185, 189, 193, 197, 201, 205, 209, 213, 217, 221, 225, 230, 235, 240, 245, 250, 255, 260, 265, 270, 275, 280, 286, 292, 298, 304, 310, 316, 322, 328, 335, 342, 349, 356, 363, 370, 377, 385, 393, 401, 409, 417, 425, 434, 443, 452, 461, 470, 479, 489, 499, 509, 519, 529, 540, 551, 562, 573, 584, 596, 608, 620, 632, 645, 658, 671, 684, 698, 712, 726, 741, 756, 771, 786, 802, 818, 834, 851, 868, 885, 903, 921, 939, 958, 977, 997, 1017, 1037, 1058, 1079, 1101, 1123, 1145, 1168, 1191, 1215, 1239, 1264, 1289, 1315, 1341, 1368, 1395, 1423, 1451, 1480, 1510, 1540, 1571, 1602, 1634, 1667, 1700, 1734, 1769, 1804, 1840, 1877, 1915, 1953, 1992, 2032, 2073, 2114, 2156, 2199, 2243, 2288, 2334, 2381, 2429, 2478, 2528, 2579, 2631, 2684, 2738, 2793, 2849, 2906, 2964, 3023, 3083, 3145, 3208, 3272, 3337, 3404, 3472, 3541, 3612, 3684, 3758, 3833, 3910, 3988, 4068, 4149, 4232, 4317, 4403, 4491, 4581, 4673, 4766, 4861, 4958, 5057, 5158, 5261, 5366, 5473, 5582, 5694, 5808, 5924, 6042, 6163, 6286, 6412, 6540, 6671, 6804, 6940, 7079, 7221, 7365, 7512, 7662, 7815, 7971, 8130, 8293, 8459, 8628, 8801, 8977, 9157, 9340, 9527, 9718, 9912, 10110, 10312, 10518, 10728, 10943, 11162, 11385, 11613, 11845, 12082, 12324, 12570, 12821, 13077, 13339, 13606, 13878, 14156, 14439, 14728, 15023, 15323, 15629, 15942, 16261, 16586, 16918, 17256, 17601, 17953, 18312, 18678, 19052, 19433, 19822, 20218, 20622, 21034, 21455, 21884, 22322, 22768, 23223, 23687, 24161, 24644, 25137, 25640, 26153, 26676, 27210, 27754, 28309, 28875, 29452, 30041, 30642, 31255, 31880, 32518, 33168, 33831, 34508, 35198, 35902, 36620, 37352, 38099, 38861, 39638, 40431, 41240, 42065, 42906, 43764, 44639, 45532, 46443, 47372, 48319, 49285, 50271, 51276, 52302, 53348, 54415, 55503, 56613, 57745, 58900, 60078, 61280, 62506, 63756, 65031, 66332, 67659, 69012, 70392, 71800, 73236, 74701, 76195, 77719, 79273, 80858, 82475, 84124, 85806, 87522, 89272, 91057, 92878, 94736, 96631, 98564, 100535, 105535, 110535, 115535, 120535, 125535, 130535, 135535, 140535, 145535, 150535, 155535, 160535, 165535, 170535, 175535, 180535, 185535, 190535, 195535, 200535, 205535, 210535, 215535, 220535, 225535, 230535, 235535, 240535, 245535, 250535, 255535, 260535, 265535, 270535, 275535, 280535, 285535, 290535, 295535, 300535, 305535, 310535, 315535, 320535, 325535, 330535, 335535, 340535, 345535, 350535, 355535, 360535, 365535, 370535, 375535, 380535, 385535, 390535, 395535, 400535, 405535, 410535, 415535, 420535, 425535, 430535, 435535, 440535, 445535, 450535, 455535, 460535, 465535, 470535, 475535, 480535, 485535, 490535, 495535, 500535, 505535, 510535, 515535, 520535, 525535, 530535, 535535, 540535, 545535, 550535, 555535, 560535, 565535, 570535, 575535, 580535, 585535, 590535, 595535, 600535, 605535, 610535, 615535, 620535, 625535, 630535, 635535, 640535, 645535, 650535, 655535, 660535, 665535, 670535, 675535, 680535, 685535, 690535, 695535, 700535, 705535, 710535, 715535, 720535, 725535, 730535, 735535, 740535, 745535, 750535, 755535, 760535, 765535, 770535, 775535, 780535, 785535, 790535, 795535, 800535, 805535, 810535, 815535, 820535, 825535, 830535, 835535, 840535, 845535, 850535, 855535, 860535, 865535, 870535, 875535, 880535, 885535, 890535, 895535, 900535, 905535, 910535, 915535, 920535, 925535, 930535, 935535, 940535, 945535, 950535, 955535, 960535, 965535, 970535, 975535, 980535, 985535, 990535, 995535};

// 频点总数
uint16_t num_saopin = 530;

// 最大增益
float max_gain;
uint16_t max_gain_index;
// 最小增益
float min_gain;
uint16_t min_gain_index;
// 当前增益
float gain;
float gains[205];
float high_gain;

float low_gain;
float jiezhi_gain;
float f_low = 0, f_high = 0;
uint16_t cutoff_index;
float freq1;
float freq2;
float gain_fc_db;
float gain_f2_db;
float slope;

float nihe_Q = 0.0f;
float nihe_w0 = 0.0f;
float nihe_f0 = 0.0f;
float nihe_K = 0.0f;
float a2, a1, a0, b2, b1, b0;

float32_t filter_in[1024], filter_out[1024];
uint16_t dac_data[1024];
uint16_t dac_clk;

uint16_t ii;

float getGain(uint32_t fre);
float getHw(float fre);

float d_a  = 0.0f;
int main()
{
	Serial_Init();
	
	RCC_AHBPeriphClockCmd(RCC_AHBPeriph_DMA1, ENABLE);
	ADC_DMA_Init(); // 初始化ADC的DMA中断
	AD_Init();		// 初始化ADC
	TIM8_init(180, 1);
	Relay_Init();
	Serial_Screen_Init();
    IC_Init();
	// 	Delay_ms(500);
	//  AD9833_Init();
	// AD9833_SetFrequencyQuick(50000.0, AD9833_OUT_TRIANGLE); // 写输出频率1000.0Hz,输出正弦波
	// //	AD9833_SetPhase(AD9833_REG_PHASE0,2048);//设置180°相位，范围：0-4095(0-360°)
	GPIO_init();
	AD9910_Init();
	Freq_Amp_convert(10000, 300);


	Relay_On();
	while (1)
	{

		if (Serial_Screen_GetRxFlag())
		{
			if (Serial_RxPacket[0] == 0xC1)
			{
				d_a += 0.02f;
			}
			if (Serial_RxPacket[0] == 0xC0)
			{
				d_a -= 0.02f;
			}
			if (Serial_RxPacket[0] == 0xA1)
			{
				if (Serial_RxPacket[1] == 0xA0)
				{
					fre_set -= 100;
				}
				else if (Serial_RxPacket[1] == 0xA1)
				{
					fre_set += 100;
				}
				else if (Serial_RxPacket[1] == 0xA2)
				{
					fre_set = 0;

					for (ii = 0; ii < Serial_Screen_Fre_BitCount - 1; ii++)
					{

						fre_set = 10 * fre_set + (Serial_Screen_Fre_Packet[ii] - 0x30);
					}
				}

				if (fre_set == 100)
				{
					amp = 600;
				}
				else if (fre_set == 200)
				{
					amp = 400;
				}
				else if (fre_set == 300)
				{
					amp = 350;
				}
				else if (fre_set == 400)
				{
					amp = 330;
				}
				else
					amp = 300;

				Serial_Screen_setFre(4, fre_set);
				AD9910_Init();
				Freq_Amp_convert(fre_set, amp);
			}

			if (Serial_RxPacket[0] == 0xA2)
			{
				if (Serial_RxPacket[1] == 0xA0)
				{
					V_set_x10 -= 1;
				}
				else if (Serial_RxPacket[1] == 0xA1)
				{
					V_set_x10 += 1;
				}

				Serial_Screen_setVpp(7, V_set_x10);
			}

			if (Serial_RxPacket[0] == 0xA0)
			{
				V_dds_f = ((float)V_set_x10 * 100.0 / getHw(fre_set));
				V_dds_f /= getGain(fre_set); // 这里修改为放大倍数
				V_dds = (int)(V_dds_f + 0.5);
				AD9910_Init();
				Freq_Amp_convert(fre_set, V_dds);
				Serial_Screen_setHw(33, (int)(getHw(fre_set) * 100 + 0.5));
				Serial_Screen_setFre(35, (int)((getGain(fre_set) * (float)V_dds) + 0.5));
				//Serial_Printf("gain:%.2f,Hw:%.2f,freset:%d,vddsf:%.2f,vdds:%d\n\r\n", getGain(fre_set), getHw(fre_set), fre_set, V_dds_f, V_dds);
			}
			if (Serial_RxPacket[0] == 0xB0)
			{
				max_gain = 0;
				AD9910_Init();
				Freq_Amp_convert(100, 200);
				Delay_ms(300);
				for (uint16_t i = 0; i < num_saopin; i++)
				{
					if (fres_saopin[i] < 500)
					{
						TIM_Cmd(TIM8, DISABLE);
						TIM8_init(1440, 1);
					}
					else
					{
						TIM_Cmd(TIM8, DISABLE);
						TIM8_init(180, 1);
					}

					AD9910_Init();
					Freq_Amp_convert(fres_saopin[i], 200);
					Delay_ms(100);
					adc_flag = 0;
					TIM_Cmd(TIM8, ENABLE);
					while (adc_flag == 0)
						;
					getVpp(AD_Value_buf);

					gain = (float)Vpp / (200 * getGain(fres_saopin[i]));
					gains[i] = gain;
					if (gain > max_gain)
					{
						max_gain = gain;
						max_gain_index = i;
					}
					//Serial_Printf("Vpp:%d,gain:%.2f,fre:%d\n\r\n", Vpp, gain, fres_saopin[i]);
				}
				if (max_gain > 1)
				{
					max_gain = 1;
				}
				jiezhi_gain = max_gain * 0.707f;

				low_gain = (gains[0] + gains[1] + gains[2]) / 3;
				high_gain = (gains[num_saopin - 3] + gains[num_saopin - 2] + gains[num_saopin - 1]) / 3;

				if (low_gain > 0.65 * max_gain && high_gain < 0.65 * max_gain)
				{
					filter_type = TYPE_LOWPASS;
				}
				else if (low_gain < 0.6 * max_gain && high_gain > 0.65 * max_gain)
				{
					filter_type = TYPE_HIGHPASS;
				}
				else if (low_gain < 0.6 * max_gain && high_gain < 0.6 * max_gain)
				{
					filter_type = TYPE_BANDPASS;
				}
				else if (low_gain > 0.5 * max_gain && high_gain > 0.5 * max_gain)
				{
					filter_type = TYPE_BANDSTOP;
				}

				if (filter_type == TYPE_BANDPASS)
				{
					for (uint16_t i = max_gain_index; i > 16; i--)
					{
						if (gains[i] >= jiezhi_gain && gains[i - 1] < jiezhi_gain)
						{
							// 线性插值精确计算频率
							f_low = (float)fres_saopin[i - 1] +
									(jiezhi_gain - gains[i - 1]) *
										(fres_saopin[i] - fres_saopin[i - 1]) /
										(gains[i] - gains[i - 1]);
							break;
						}
					}
					for (uint16_t i = max_gain_index; i < 500 - 1; i++)
					{
						if (gains[i] >= jiezhi_gain && gains[i + 1] < jiezhi_gain)
						{
							f_high = (float)fres_saopin[i] +
									 (jiezhi_gain - gains[i]) *
										 (fres_saopin[i + 1] - fres_saopin[i]) /
										 (gains[i] - gains[i + 1]);
							break;
						}
					}
					nihe_f0 = sqrtf(f_low * f_high);
					nihe_w0 = 2 * PI * nihe_f0;
					nihe_Q = nihe_f0 / (f_high - f_low);
					nihe_K = max_gain;
					a1 = nihe_K * nihe_w0 / nihe_Q;
					a2 = 0;
					a0 = 0;
					b2 = 1;
					b1 = nihe_w0 / nihe_Q;
					b0 = nihe_w0 * nihe_w0;
				}
				else if (filter_type == TYPE_BANDSTOP)
				{
					// 1. 寻找最小增益点（中心频率点）

					min_gain_index = 0;
					min_gain = gains[0];
					for (uint16_t i = 1; i < 175; i++)
					{
						if (gains[i] < min_gain)
						{
							min_gain = gains[i];
							min_gain_index = i;
						}
					}

					// 2. 初始化截止频率
					f_low = 0.0f;
					f_high = 0.0f;

					// 3. 向低频方向搜索截止点（增益上升沿）
					for (uint16_t i = min_gain_index; i > 1; i--)
					{
						if (gains[i] <= jiezhi_gain && gains[i - 1] > jiezhi_gain)
						{
							// 线性插值计算低频截止频率
							f_low = (float)fres_saopin[i - 1] +
									(jiezhi_gain - gains[i - 1]) *
										(fres_saopin[i] - fres_saopin[i - 1]) /
										(gains[i] - gains[i - 1]);
							break;
						}
					}

					// 4. 向高频方向搜索截止点（增益上升沿）
					for (uint16_t i = min_gain_index; i < 500; i++) // 174=175-1
					{
						if (gains[i] <= jiezhi_gain && gains[i + 1] > jiezhi_gain)
						{
							// 线性插值计算高频截止频率
							f_high = (float)fres_saopin[i] +
									 (jiezhi_gain - gains[i]) *
										 (fres_saopin[i + 1] - fres_saopin[i]) /
										 (gains[i + 1] - gains[i]);
							break;
						}
					}

					// 5. 计算滤波器关键参数
					nihe_f0 = sqrtf(f_low * f_high);	 // 中心频率
					nihe_w0 = 2 * PI * nihe_f0;			 // 角频率
					nihe_Q = nihe_f0 / (f_high - f_low); // 品质因数
					nihe_K = max_gain;					 // 通带增益

					// 6. 计算传递函数系数（双二阶形式）
					// 分子系数: K*(s^2 + w0^2)
					a2 = nihe_K;					 // s^2项系数
					a1 = 0;							 // s项系数
					a0 = nihe_K * nihe_w0 * nihe_w0; // 常数项系数

					// 分母系数: s^2 + (w0/Q)s + w0^2
					b2 = 1;					// s^2项系数（归一化）
					b1 = nihe_w0 / nihe_Q;	// s项系数
					b0 = nihe_w0 * nihe_w0; // 常数项系数
				}
				else if (filter_type == TYPE_LOWPASS)
				{
					// 1. 寻找截止频率点（下降沿）

					for (uint16_t i = 0; i < 500; i++)
					{
						if (gains[i] >= jiezhi_gain && gains[i + 1] < jiezhi_gain)
						{
							// 线性插值计算截止频率
							f_high = (float)fres_saopin[i] +
									 (jiezhi_gain - gains[i]) *
										 (fres_saopin[i + 1] - fres_saopin[i]) /
										 (gains[i] - gains[i + 1]);
							break;
						}
					}
					nihe_f0 = f_high;
					nihe_K = max_gain;
					nihe_w0 = 2 * PI * nihe_f0; // 角频率
					nihe_Q = 0.707;
					a2 = 0;
					a1 = 0;
					a0 = nihe_K * nihe_w0 * nihe_w0;
					b2 = 1;
					b1 = nihe_w0 / nihe_Q;
					b0 = nihe_w0 * nihe_w0;
				}
				else if (filter_type == TYPE_HIGHPASS)
				{

					// 1. 寻找截止频率点（上升沿）

					for (uint16_t i = 500; i > 0; i--)
					{
						if (gains[i] >= jiezhi_gain && gains[i - 1] < jiezhi_gain)
						{
							// 线性插值计算截止频率
							f_low = (float)fres_saopin[i - 1] +
									(jiezhi_gain - gains[i - 1]) *
										(fres_saopin[i] - fres_saopin[i - 1]) /
										(gains[i] - gains[i - 1]);
							break;
						}
					}
					nihe_f0 = f_low;
					nihe_w0 = 2 * PI * nihe_f0; // 角频率
					nihe_Q = 0.707;
					nihe_K = max_gain; // 高频增益
					// 4. 传递函数系数（二阶高通）
					a2 = nihe_K; // s^2项系数
					a1 = 0;
					a0 = 0;

					b2 = 1;
					b1 = nihe_w0 / nihe_Q;
					b0 = nihe_w0 * nihe_w0;
				}
				Serial_Printf("max_gain:%.2f,high_gain:%.2f,low_gain:%.2f,filter_type:%d,f_low:%.2f,f_high:%.2f\n\r\n", max_gain, high_gain, low_gain, filter_type, f_low, f_high);
				Serial_Screen_setFilterType(filter_type);
				Serial_Screen_setFre(42, (int)f_low);
				Serial_Screen_setFre(43, (int)f_high);
			}

			if (Serial_RxPacket[0] == 0xB1)
			{
				Relay_Off();
				
				initIIRFilter(a2, a1, a0, b2, b1, b0, IC_GetFreq() * 16);
				
				 AD_SwitchToEXTI();
				Serial_Printf("freq:%d\n\r\n",IC_GetFreq());
					
					adc_flag = 0;
					while (adc_flag == 0)
						;
					for (ii = 0; ii < 1024; ii++)
					{
						filter_in[ii] = (float)AD_Value_buf[ii] - Vdc;
						//Serial_Printf("%.2f\n", filter_in[ii]);
					}
					processIIRFilter(filter_in, filter_out, 1024);
					for (ii = 0; ii < 1024; ii++)
					{
						dac_data[ii] = (int)(filter_out[ii] + 2048);
						//Serial_Printf("%d\n", dac_data[ii]);
					}
					DAC_Mode_Init(dac_data);
				
			}
		}
	}
}
float getHw(float fre)
{
	float w = 2 * PI * fre;
	return 5.0 /
		   sqrt((1 - (w / w0) * (w / w0)) * (1 - (w / w0) * (w / w0)) + (w / (w0 * Q)) * (w / (w0 * Q)));
}
float getGain(uint32_t fre)
{
	if (fre > 50 && fre <= 150)
	{
		return 4.40 + d_a;
	}
	else if (fre > 150 && fre <= 250)
	{
		return 7.8+ d_a;
	}
	else if (fre > 250 && fre <= 350)
	{
		return 10.25+ d_a;
	}
	else if (fre > 350 && fre <= 450)
	{
		return 11.4+ d_a;
	}
	else if (fre > 450 && fre <= 550)
	{
		return 12.4+ d_a;
	}
	else if (fre > 550 && fre <= 650)
	{
		return 12.9+ d_a;
	}
	else if (fre > 650 && fre <= 750)
	{
		return 13.35+ d_a;
	}
	else if (fre > 750 && fre <= 850)
	{
		return 13.6+ d_a;
	}
	else
		return 13.65;
}

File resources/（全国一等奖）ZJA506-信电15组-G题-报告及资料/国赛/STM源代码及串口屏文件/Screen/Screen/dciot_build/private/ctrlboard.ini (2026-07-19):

[tcpip]

dhcp=n

ipaddr=192.168.1.100

netmask=255.255.255.0

gw=192.168.1.1

dns=192.168.1.1

server_port=5050

remote_ip=192.168.1.200

network_transfer=0

network_mode=0



[ctrlboard]

lcd_width=1024

lcd_height=600

baudrate=115200

enable_keysound=0

audiolevel=100



[wifi]

wifi_mode=0

ssid=

password=

secumode=0

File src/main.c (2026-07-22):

/**
 * main.c —— STM32 App Framework 骨架
 *
 * 只做四件事：
 *   1) 内核: HAL_Init + 系统时钟 (HSE 8M × 9 = 72MHz)
 *   2) BSP : GPIO / USART1 (调试) / ADC
 *   3) 通用模块 & 驱动的 init
 *   4) 注册调度任务 → sched_run_forever
 *
 * 增加业务模块的步骤:
 *   - include/module/xxx.h + src/module/xxx.c: void xxx_init/void xxx_task
 *   - 若需要新驱动: include/drv/yyy.h + src/drv/yyy.c
 *   - 在下方 "任务表" 里加一行 sched_task_t，并在 main() 里 sched_register
 *
 * 任务耗时约束 (详见 core/scheduler.h):
 *   - 禁用 HAL_Delay / 阻塞轮询
 *   - 单次执行时间 < 5ms
 *   - 长操作用状态机分帧
 */

#include "stm32f1xx_hal.h"

#include "bsp/gpio.h"
#include "bsp/uart.h"
#include "bsp/adc.h"
#include "bsp/led.h"

#include "core/scheduler.h"
#include "module/ui.h"
#include "module/thd.h"
#include "module/dds.h"
#include "module/signal_out.h"
#include "module/panel_ctrl.h"
#include "module/learning.h"
#include "module/inference.h"
static void SystemClock_Config(void)
{
    RCC_OscInitTypeDef osc = {0};
    RCC_ClkInitTypeDef clk = {0};

    osc.OscillatorType = RCC_OSCILLATORTYPE_HSE;
    osc.HSEState       = RCC_HSE_ON;
    osc.PLL.PLLState   = RCC_PLL_ON;
    osc.PLL.PLLSource  = RCC_PLLSOURCE_HSE;
    osc.PLL.PLLMUL     = RCC_PLL_MUL9;
    if (HAL_RCC_OscConfig(&osc) != HAL_OK) {
        osc.OscillatorType      = RCC_OSCILLATORTYPE_HSI;
        osc.HSIState            = RCC_HSI_ON;
        osc.HSICalibrationValue = RCC_HSICALIBRATION_DEFAULT;
        osc.PLL.PLLSource       = RCC_PLLSOURCE_HSI_DIV2;
        osc.PLL.PLLMUL          = RCC_PLL_MUL16;
        if (HAL_RCC_OscConfig(&osc) != HAL_OK) while (1);
    }

    clk.ClockType      = RCC_CLOCKTYPE_SYSCLK | RCC_CLOCKTYPE_HCLK |
                         RCC_CLOCKTYPE_PCLK1  | RCC_CLOCKTYPE_PCLK2;
    clk.SYSCLKSource   = RCC_SYSCLKSOURCE_PLLCLK;
    clk.AHBCLKDivider  = RCC_SYSCLK_DIV1;
    clk.APB1CLKDivider = RCC_HCLK_DIV2;
    clk.APB2CLKDivider = RCC_HCLK_DIV1;
    if (HAL_RCC_ClockConfig(&clk, FLASH_LATENCY_2) != HAL_OK) while (1);
}




/* ===== 任务表 (在这里增删) ===== */
static sched_task_t t_ui         = { .run = ui_task,          .period_ms = 100,  .name = "ui"  };
static sched_task_t t_signal_out = { .run = signal_out_task,  .period_ms = 3000, .name = "sigout" };
/* 屏任务: 每 50 ms 处理一次 UART2 收到的屏事件.
 *   - drv/serial_screen 在 UART2 中断里 (SCREEN_UART_IRQHandler) 组好完整帧,
 *     调 panel_ctrl.on_frame (仍在中断里) 存待办 flag / 缓存 freq/vpp.
 *   - panel_ctrl_task 在这里的 task 上下文里检查 flag, 真正调 signal_out_set. */
static sched_task_t t_panel      = { .run = panel_ctrl_task,  .period_ms = 50,   .name = "panel" };
/* 学习任务: 10 ms tick 推进扫频状态机 (M3, 见 module/learning) */
static sched_task_t t_learning   = { .run = learning_task,    .period_ms = 10,   .name = "learn" };
/* 推理任务: IIR 全部在 ADC 回调里跑, 这里只做偶发检查 (M4) */
static sched_task_t t_inference  = { .run = inference_task,   .period_ms = 100,  .name = "infer" };

int main(void)
{
    /* ---- 内核 ---- */
    HAL_Init();
    SystemClock_Config();

    /* ---- BSP ---- */
    MX_GPIO_Init();
    MX_USART1_UART_Init();          /* 调试口 (UART_Printf 走这里) */
    MX_USART2_UART_Init();          /* 大彩串口屏 PA2/PA3 @115200 */
    MX_ADC1_Init();                 /* 学习/推理都要用 */

    /* ---- 通用模块 & 驱动 ---- */
    ui_init();
    dds_init();                     /* dds_init 内部会 ad9910_init: SPI/复位/PLL 锁定 */
    panel_ctrl_init();              /* 注册屏事件回调 (内部再次 MX_USART2_UART_Init 无害) */
    learning_init();                /* 学习状态机 + 频率表初始化 */
    inference_init();               /* 推理 biquad + DAC 初始化 */

    /* ---- 调度器 ---- */
    sched_init();
    //sched_register(&t_ui);
    //sched_register(&t_panel);       /* 屏事件驱动: 输入 + 输出 + 学习 + 推理按钮 */
    //sched_register(&t_learning);    /* 学习状态机 10 ms tick */
    //sched_register(&t_inference);   /* 推理观察任务 (真活在 ADC 回调) */
    //sched_register(&t_signal_out);
    dds_tone_sine(3000,0.1f,0.0f);
    sched_run_forever();
}

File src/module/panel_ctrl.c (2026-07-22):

/*
 * panel_ctrl.c —— 串口屏 ↔ 业务模块胶水层 (V5.1 协议)
 *
 * 屏 → MCU 上报帧统一格式:
 *   EE B1 11 [Screen_id:2B] [Ctrl_id:2B] [Ctrl_type:1B] [payload] FF FC FF FF
 *
 * 本模块只做:
 *   ISR 上下文: 组好帧后按 Ctrl_id 分发, 只置 flag / 缓存参数, 不做 SPI/ADC
 *   task 上下文 (50 ms): 检查 flag, 调对应业务模块
 *
 * 控件表 (与 panel_ctrl.h 里 SCREEN_CTRL_* 宏一致):
 *   4  文本 —— 频率输入
 *   7  文本 —— 电压输入
 *   11 按钮 —— 经模型输出   (M2, signal_out_set)
 *   40 按钮 —— 信号输出模式 (M1, dds_tone_sine 直调)
 *   50 按钮 —— 学习模式     (M3, learning_start)
 *   51 按钮 —— 推理模式     (M4, inference_start)
 *   52 按钮 —— 停止         (learning_stop + inference_stop + dds_stop)
 */

#include "module/panel_ctrl.h"
#include "drv/serial_screen.h"
#include "module/signal_out.h"
#include "module/dds.h"
#include "module/learning.h"
#include "module/inference.h"
#include "bsp/uart.h"
#include <stdio.h>
#include <stdlib.h>
#include <string.h>

/* ==================================================================
 *  ISR 与 task 之间: 待办 flag + 参数缓存
 * ================================================================== */
static volatile bool     s_pending_output     = false;
static volatile bool     s_pending_raw_output = false;
static volatile bool     s_pending_learn      = false;
static volatile bool     s_pending_infer      = false;
static volatile bool     s_pending_stop       = false;

static volatile double   s_last_freq_v        = 1000.0;    /* 默认 1kHz */
static volatile float    s_last_vpp_v         = 1.0f;      /* 默认 1V   */

/* 学习结果推送屏显 (由 task 观察 learning_get_state 变化触发) */
static learn_state_t     s_prev_learn_state   = LEARN_IDLE;

/* ==================================================================
 *  ASCII → 数字
 * ================================================================== */
static double parse_ascii_double(const uint8_t *s, uint8_t n)
{
    if (!s || n == 0) return 0.0;
    char tmp[16];
    uint8_t m = (n < sizeof(tmp) - 1) ? n : (uint8_t)(sizeof(tmp) - 1);
    memcpy(tmp, s, m);
    tmp[m] = '\0';
    return atof(tmp);
}

/* ==================================================================
 *  按钮帧共享检查: 是否 "按下" 事件
 *   payload = [Subtype:1B, Status:1B], Status=0x01 = 按下
 * ================================================================== */
static inline bool is_button_press(uint8_t ctrl_type,
                                   const uint8_t *payload, uint8_t plen)
{
    return (ctrl_type == 0x10) && (plen >= 2) &&
           (payload[plen - 1] == 0x01);
}

/* ==================================================================
 *  drv/serial_screen 帧回调 (中断上下文)
 * ================================================================== */
static void on_frame(uint16_t screen_id, uint16_t ctrl_id, uint8_t ctrl_type,
                     const uint8_t *payload, uint8_t payload_len)
{
    (void)screen_id;

    switch (ctrl_id) {
    case SCREEN_CTRL_FREQ_INPUT:
        s_last_freq_v = parse_ascii_double(payload, payload_len);
        break;

    case SCREEN_CTRL_VPP_INPUT:
        s_last_vpp_v = (float)parse_ascii_double(payload, payload_len);
        break;

    case SCREEN_CTRL_OUTPUT_BTN:
        if (is_button_press(ctrl_type, payload, payload_len))
            s_pending_output = true;
        break;

    case SCREEN_CTRL_RAW_OUTPUT_BTN:
        if (is_button_press(ctrl_type, payload, payload_len))
            s_pending_raw_output = true;
        break;

    case SCREEN_CTRL_LEARN_BTN:
        if (is_button_press(ctrl_type, payload, payload_len))
            s_pending_learn = true;
        break;

    case SCREEN_CTRL_INFER_BTN:
        if (is_button_press(ctrl_type, payload, payload_len))
            s_pending_infer = true;
        break;

    case SCREEN_CTRL_STOP_BTN:
        if (is_button_press(ctrl_type, payload, payload_len))
            s_pending_stop = true;
        break;

    default:
        break;
    }
}

/* ==================================================================
 *  API
 * ================================================================== */
void panel_ctrl_init(void)
{
    screen_init();
    screen_on_frame(on_frame);
    s_prev_learn_state = LEARN_IDLE;
}

/* 每 50 ms 跑一次 —— 处理屏事件 + 观察学习状态变化推屏 */
void panel_ctrl_task(void)
{
    /* --- 屏事件分发 --- */
    if (s_pending_output) {
        s_pending_output = false;
        double f = s_last_freq_v;
        float  v = s_last_vpp_v;
        UART_Printf("[panel] M2 OUTPUT_H: signal_out_set(%.2f Hz, %.3f V)\r\n",
                    f, (double)v);
        signal_out_set(f, v);
    }

    if (s_pending_raw_output) {
        s_pending_raw_output = false;
        double f = s_last_freq_v;
        UART_Printf("[panel] M1 OUTPUT_RAW: dds_tone_sine(%.2f Hz, 0.6 V)\r\n", f);
        dds_tone_sine(f, 0.6f, 0.0f);
    }

    if (s_pending_learn) {
        s_pending_learn = false;
        UART_Printf("[panel] M3 LEARN: learning_start()\r\n");
        if (!learning_start())
            UART_Printf("[panel] learning already running\r\n");
    }

    if (s_pending_infer) {
        s_pending_infer = false;
        UART_Printf("[panel] M4 INFER: inference_start()\r\n");
        if (!inference_start())
            UART_Printf("[panel] inference start failed (no model?)\r\n");
    }

    if (s_pending_stop) {
        s_pending_stop = false;
        UART_Printf("[panel] STOP: learning/inference/dds_stop\r\n");
        learning_stop();
        inference_stop();
        dds_stop();
    }

    /* --- 学习状态变化观察: RUNNING → DONE 时推屏 --- */
    learn_state_t st = learning_get_state();
    if (st != s_prev_learn_state) {
        if (st == LEARN_DONE) {
            const learn_result_t *r = learning_get_result();
            const char *name = learning_filter_name(r->type);
            double f0 = (r->n_params >= 1)
                          ? (double)r->params[0] / 6.28318530717958
                          : 0.0;
            UART_Printf("[panel] LEARN done -> %s, f0=%.1f Hz\r\n", name, f0);
            /* TODO: 用 screen_update_text() 把 "name/f0" 推到屏文本控件 */
        } else if (st == LEARN_FAILED) {
            UART_Printf("[panel] LEARN failed\r\n");
        }
        s_prev_learn_state = st;
    }
}

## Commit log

2026-07-15 增加AD9910模块例程
2026-07-16 增加硬件设计
2026-07-16 增加AD9910模块驱动
2026-07-16 增加RAM控制方式
2026-07-16 输出三角波方波
2026-07-17 RAM输出方波频率校准
2026-07-18 sinc例程增加
2026-07-18 增加已知模型输出设定计算代码
2026-07-19 标定传递函数，按照实际电路传递函数
    [1_P1.schdoc, PCB1.pcbdoc, PCB1_1.pcbdoc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]
2026-07-19 标定实际放大电路增益为5
2026-07-21 设定输出信号模式完成调试
2026-07-22 完善报告结构
2026-07-22 增加测试数据
2026-07-23 Revise theoretical analysis and calculations in report
    Updated theoretical analysis and calculations for the known model circuit, including voltage transfer function, component parameters, and frequency response analysis.
2026-07-24 调整报告
2026-07-24 修订报告
2026-07-24 删除无用文件
